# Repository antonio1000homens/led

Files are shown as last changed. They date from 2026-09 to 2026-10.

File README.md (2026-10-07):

# LED information board

CircuitPython prototype for four 64×32 HUB75 RGB panels arranged as one 256×32 board. The intended physical controller is an Adafruit MatrixPortal S3. The board is now a generic renderer: external feeds are normalized by the CPython backend into `/api/screens`, and both the browser simulator and physical MatrixPortal consume the same screen contract.

## Architecture

```text
National Rail ───┐
Queue-Times ─────┤
Todoist ─────────┼──> publisher/server ──> GET /api/screens ──> MatrixPortal S3
Open-Meteo ──────┤                              │                    │
Future feeds ────┘                              └──> browser          └──> 256×32 HUB75
```

## Repository layout

Application Python is grouped by runtime rather than kept flat at the repository root:

```text
code.py       CircuitPython/Wokwi entrypoint
hardware/matrixportal/firmware/  MatrixPortal implementation
backend/      local CPython server and Lambda implementation
shared/       renderer/fixture modules used by both runtimes
scripts/      build, test, deployment and maintenance tooling
tests/        host-side regression tests
docs/         cross-cutting architecture/deployment documentation
```

The root `code.py` is intentional because Wokwi/CircuitPython uses that
entrypoint. Use `scripts/stage-firmware.sh` to create the flat filesystem
expected by a physical board, or `scripts/install-firmware.sh` to copy it to
a mounted `CIRCUITPY` volume.

MQTT carries two independent display paths. Retained snapshots on
`led/screens/+` add expiring screens to the normal rotation; reminder events on
`led/flash/reminder` remain interrupting overlays that pause and resume that
rotation. The first cycle-screen producer is the [Home Assistant next-recycling
screen](https://github.com/antonio1000homens/homeassistant/issues/7). The board
uses one MQTT connection, and broker credentials remain in board-local
settings.

The MatrixPortal does not hold National Rail, Todoist, Queue-Times or weather-provider credentials. It only needs Wi-Fi access to the backend. Feed authentication, polling, caching and stale handling remain server-side.

The checked-in defaults run a deterministic fixture mode for Wokwi, with no credentials or LAN backend required. Screens rotate using each screen's `duration_seconds`. The top-right `HH:MM` clock and bottom-right weather status are renderer-level overlays and therefore remain visible on every screen.

## Production AWS deployment

Production does **not** run `backend/server.py` as an always-on webserver. EventBridge Scheduler invokes `led-publisher` once per minute; the Lambda refreshes only feeds whose independent TTL has elapsed, persists the last successful feed state to private S3, and atomically publishes the existing `/api/screens` contract as an S3 object. CloudFront serves the simulator and screen snapshot through a private S3 Origin Access Control (OAC).

The production endpoint is:

```text
https://led.alf-broadcast.co.uk
https://led.alf-broadcast.co.uk/api/screens
```

Cloudflare remains the authoritative DNS provider and points the DNS-only `led.alf-broadcast.co.uk` CNAME at CloudFront. The S3 `state/*` prefix is not exposed through CloudFront.

GitHub Actions uses AWS OIDC and stores only non-secret deployment configuration. The National Rail and Windsor Cloudflare deployment secrets are Standard `SecureString` parameters under `/led/deploy/*`; the workflow assumes `GitHubActionsLedDeployRole` first, then decrypts and masks those two values. Todoist is separate because its OAuth refresh token rotates at runtime: its client credentials plus access/refresh tokens remain in `/led/todoist/oauth`, which only the publisher runtime can read and update.

See [`docs/DEPLOYMENT.md`](docs/DEPLOYMENT.md) for first-time AWS bootstrap, the Bitwarden-to-SSM migration helper, deployment-secret rotation, Todoist OAuth bootstrap, GitHub variables, ACM/Cloudflare setup, manual deployment and runtime details.

## Remote model slicing

This repository owns the CAD sources and geometry validation. The reusable
Windsor Slicer service prepares this repository at an immutable commit,
generates the model declared in `.windsor-slicer.yaml`, validates it, and
returns a sliced 3MF. It does not submit jobs to a printer.

See [Windsor Slicer](https://github.com/antonio1000homens/windsor-slicer) for
the manifest contract and service details. The public MCP endpoint is
`https://slicer.alf-broadcast.co.uk/mcp`.
## Hardware notes

For the current MatrixPortal refresh/pacing architecture, measured performance
results, and the decisions from issues #70, #91, #92 and #94, see
[`hardware/matrixportal/docs/matrixportal-performance.md`](hardware/matrixportal/docs/matrixportal-performance.md).

The four panels must have an appropriate HUB75 data chain and a separate, correctly sized 5 V power supply. Do not attempt to power four panels from the MatrixPortal or USB alone. Confirm the panel scan/pin wiring against the actual panel before purchase; the software assumes the MatrixPortal S3 `MTX_*` pin definitions and 1/32-scan 64×32 panels.

Wokwi uses four chained WS2812 matrix parts as a visual surrogate because its documented CircuitPython target and built-in matrix part do not reproduce a MatrixPortal S3 HUB75 panel. It also prints the active screen to the serial monitor.

## Run tests

```sh
bash scripts/run-tests.sh
```

## Backend

For rapid look-and-feel work without a MatrixPortal, run the local server:

```sh
bash scripts/run-server.sh
```

Then visit `http://127.0.0.1:8000`. The browser polls `/api/screens` every 30 seconds and renders the same normalized screen kinds used by the physical board.

### Live National Rail data

The backend talks to National Rail Darwin LDBWS and keeps the credential server-side. Install the CPython-only dependency in an isolated environment:

```sh
python3 -m venv .venv
source .venv/bin/activate
python -m pip install -r requirements-server.txt
```

Copy `.env.example` to `.env` and set the Bitwarden Secrets Manager UUID:

```text
LED_DATA_SOURCE=national_rail
BWS_NATIONAL_RAIL_TOKEN_SECRET_ID=<bitwarden-secret-uuid>
```

The process requires an authenticated `bws` CLI, normally through `BWS_ACCESS_TOKEN`. It resolves the token at startup and never sends it to the MatrixPortal or browser. This is a local-development path only; the production GitHub deployment no longer depends on a Bitwarden machine account.

### Thorpe Park queue times

The backend can append a Thorpe Park screen sourced from Queue-Times.com park ID `2`. No Queue-Times credential is required. The default cache is 300 seconds to match the source's approximate refresh cadence.

Enable it in `.env`:

```text
LED_THORPE_PARK_SOURCE=queue_times
LED_THORPE_PARK_CACHE_SECONDS=300
LED_THORPE_PARK_RIDES=Hyperia,Stealth,The Swarm,SAW - The Ride,Nemesis Inferno,Colossus,Ghost Train,Rush,Detonator,Tidal Wave
```

Configured rides are matched case-insensitively and kept in a stable order. The heading remains fixed while a three-row viewport cycles down the configured list: rows hold briefly, slide upward together, then settle on the next ride. When more rides are configured the Thorpe Park screen duration grows so the additional rows can be shown before the board rotates to the next screen. A failed refresh keeps the last successful data and marks only the Thorpe Park screen stale; a cold Queue-Times failure produces an unavailable Thorpe screen without removing rail departures.

Queue data is displayed with `Powered by Queue-Times.com` attribution.

### Todoist upcoming events

Production can append a `calendar_agenda` screen sourced from the Todoist API v1 `GET /api/v1/tasks/filter` endpoint. The publisher follows Todoist cursor pagination, normalizes scheduled items into Europe/London time, retains active overdue tasks, sorts them chronologically, removes only undated tasks, and publishes at most six events. Overdue rows are labelled `OVERDUE` on the board.

The display uses a departure-board-style two-column row:

```text
13/09 18:30 Event one
14/09 ALL   All-day event
14/09 09:00 Event three
```

Three rows are visible at once. With four to six events the first three remain visible for five seconds, then the rows slide upward together and events 4–6 settle into the same viewport. The heading, clock and weather overlay remain fixed. With three or fewer events no paging occurs.

Default production settings are:

```text
LED_CALENDAR_SOURCE=off
LED_TODOIST_CACHE_SECONDS=300
LED_TODOIST_MAX_EVENTS=6
LED_TODOIST_FILTER_QUERY=due before: tomorrow | due after: yesterday
LED_TODOIST_TIMEZONE=Europe/London
LED_CALENDAR_DURATION_SECONDS=10
LED_CALENDAR_PAGE_SECONDS=5
```

The feed is intentionally **off by default**. The current production `/api/screens` object is publicly retrievable through CloudFront, so enabling a personal Todoist feed makes the selected task names and dates/times publicly retrievable as part of that JSON response. Use a deliberately narrow Todoist filter/project/label if this exposure is acceptable, or protect/personalize the screen endpoint before enabling private task data.

#### Todoist OAuth bootstrap

Use the Client ID and Client Secret from the Todoist integration rather than a personal API token. OAuth state is stored in SSM Parameter Store at `/led/todoist/oauth` as a **Standard `SecureString`**. The value contains the client credentials plus the current access and refresh tokens. The Lambda reads it with decryption, refreshes expiring access tokens itself, and immediately overwrites the parameter with Todoist's replacement refresh token.

For a newly-created Todoist integration, add this OAuth redirect URL in Todoist App Management unless you choose another URI:

```text
http://127.0.0.1:8765/callback
```

For a fresh authorization, run the bootstrap script from a machine with AWS CLI access to the LED account:

```sh
TODOIST_CLIENT_ID='<client-id>' \
AWS_PROFILE='<aws-profile>' \
python3 scripts/bootstrap-todoist-oauth.py
```

The script prompts securely for the Client Secret, requests only the `data:read` Todoist scope, opens the authorization page in your browser, validates the OAuth `state`, receives the localhost callback, exchanges the authorization code, and writes the credentials/tokens to the Standard `SecureString`. To use a different registered redirect URI, set `TODOIST_REDIRECT_URI`; `--manual` is also available when a localhost callback is unsuitable.

If you already bootstrapped the previous Secrets Manager implementation, migrate the existing OAuth JSON without authorizing Todoist again:

```sh
AWS_PROFILE='<aws-profile>' \
python3 scripts/bootstrap-todoist-oauth.py \
  --migrate-secret-id '<existing-secrets-manager-arn>'
```

After deploying the SSM-backed stack and verifying Todoist, schedule the old Secrets Manager secret for deletion so it is no longer billed:

```sh
AWS_PROFILE='<aws-profile>' aws secretsmanager delete-secret \
  --region eu-west-2 \
  --secret-id '<existing-secrets-manager-arn>' \
  --recovery-window-in-days 7
```

Do not pass the Client Secret on a shell command line. For unattended fresh authorization the script also accepts `TODOIST_CLIENT_SECRET` from the environment, but an interactive prompt is preferred.

Once OAuth is present in SSM, set the GitHub repository variable:

```text
LED_CALENDAR_SOURCE=todoist
```

and run the deployment workflow. There is no `BW_TODOIST_TOKEN` or Todoist token CloudFormation parameter; runtime token rotation is contained in the SSM `SecureString`.

A failed Todoist refresh preserves the last successful events and marks only the calendar screen stale. A cold Todoist failure publishes `Calendar unavailable` without affecting rail, queue or weather data. A successful response containing no qualifying tasks renders `No upcoming events` and is not stale.

For credential-free visual testing, the local fixture contains six normalized events and exercises both agenda pages:

```sh
bash scripts/run-server.sh --calendar-source fixture
```

### Current weather overlay and dedicated Weather screens

The backend uses one Open-Meteo request and one atomic Weather cache for all Weather output: the compact current-weather overlay, the seven-day daily forecast, the rolling next-24-hour forecast, and today's sunrise/sunset. The request includes current temperature/WMO weather code, hourly temperature/weather code, and daily max/min/weather code/sunrise/sunset with `timezone=auto`. The free non-commercial endpoint needs no API key. Weather is cached for 600 seconds by default, so MatrixPortal/browser polls never create separate upstream polling paths for the three dedicated screens.

The default coordinates are New Malden railway station, matching the default `NEM` departure board:

```text
LED_WEATHER_SOURCE=open_meteo
LED_WEATHER_CACHE_SECONDS=600
LED_WEATHER_LATITUDE=51.4039
LED_WEATHER_LONGITUDE=-0.256
```

Set `LED_WEATHER_SOURCE=off` to stop Weather polling and remove all Weather output, or change latitude/longitude for another location. When Weather is enabled, the dedicated screens appear in this order when their individual controls are enabled:

1. `weather_weekly` — the existing seven-day overview, default 8 seconds. It preserves the max-only layout introduced with #195: weekday, enlarged weather icon and maximum temperature.
2. `weather_today` — six rolling four-hour snapshots covering the next 24 hours, default 8 seconds. The first column is labelled `Now` and uses current conditions; the remaining columns are labelled at four-hour intervals and may cross midnight. The weather icon and temperature remain prominent.
3. `weather_sun` — today's local sunrise and sunset times, default 6 seconds.

The protected admin/control plane provides independent enable and duration controls for the overview, next-24-hour and sunrise/sunset screens. The master Weather `enabled` switch still owns provider polling. If all three dedicated screens are disabled while Weather remains enabled, polling/cache refresh continues and the current-weather overlay can still appear on unrelated screens.

The backend maps Open-Meteo WMO weather codes into a renderer-neutral icon set (`clear_day`, `clear_night`, `partly_cloudy_*`, `cloudy`, `fog`, `rain`, `snow`, `storm`). All three dedicated Weather screens use the full 256×32 canvas and suppress the normal clock/current-weather/STALE header chrome; the browser simulator mirrors the same screen sequence and supports forced-stale preview.

If a Weather refresh fails after at least one successful response, the complete last-good current + weekly + rolling next-24-hour + solar payload remains available with `stale: true` and the dedicated renderers use their muted treatment. On a cold Weather failure, unrelated feeds remain available; the seven-day overview may show its existing unavailable state when enabled, while empty next-24-hour and sunrise/sunset screens are not emitted. Browser attribution links to Open-Meteo are included as required by the provider's licence.

### Screen contract

`GET /api/screens` is the renderer-neutral contract. A response contains `fetched_at` plus one or more screens. The current-weather object is attached to every screen for the shared header carousel, and Weather also contributes one dedicated `weather_weekly` screen with a `days` array:

```json
{
  "fetched_at": "2026-09-13T11:45:30Z",
  "screens": [
    {
      "id": "departures",
      "kind": "rail_combined",
      "duration_seconds": 8,
      "title": "NEM departures",
      "source": "national_rail",
      "stale": false,
      "services": []
    },
    {
      "id": "calendar",
      "kind": "calendar_agenda",
      "duration_seconds": 10,
      "title": "UPCOMING",
      "source": "todoist",
      "stale": false,
      "viewport_size": 3,
      "page_seconds": 5,
      "events": [
        {"start": "2026-09-13T18:30:00+01:00", "all_day": false, "date_text": "13/09", "time_text": "18:30", "title": "Event one"}
      ]
    }
  ]
}
```

The MatrixPortal rotates these screens locally and does not reset the active screen every time fresh data is polled. If the backend becomes temporarily unreachable it keeps the last screens, marks the active screen stale, and dims the retained weather value.

The board can also receive MQTT cycle screens independently from HTTP. Publish
retained JSON snapshots to `led/screens/<screen.id>` at QoS 1. Each snapshot
uses `schema_version: 1`, `event: "upsert"`, ISO-8601 `published_at` and
`expires_at`, a `source`, and a renderer payload under `screen`. A later
`published_at` replaces that slot; an older one is ignored. Send
`event: "clear"` with a fresh `published_at` to remove a slot. Expiry is checked
against the synchronized board clock locally, so an expired retained value
does not reappear after reconnect. HTTP screens remain in backend order, then
active MQTT screens are appended in stable ID order.

The topic suffix must exactly equal `screen.id`. The board accepts only
schema version 1 and `upsert` or `clear` events, and ignores malformed,
unknown-kind, mismatched, older and already-expired snapshots. A clear retains
its publication timestamp for ordering. Reconnect delivers the broker's
retained active snapshot again.

```json
{
  "schema_version": 1,
  "event": "upsert",
  "published_at": "2026-10-07T19:00:05+01:00",
  "expires_at": "2026-10-14T00:00:00+01:00",
  "source": "homeassistant",
  "screen": {
    "id": "homeassistant-next-bin",
    "kind": "bin_collection",
    "title": "NEXT COLLECTION",
    "duration_seconds": 8,
    "slide_speed": 20,
    "collection_date": "2026-10-13",
    "collections": [{"id": "mixed", "label": "Mixed recycling"}],
    "source": "homeassistant",
    "stale": false
  }
}
```

Clear a slot by publishing a retained `event: "clear"` snapshot with a newer
`published_at` to that same topic. It has no `screen` or `expires_at` field.

The first MQTT renderer is `bin_collection`: provide `title`, ISO
`collection_date`, one or two `{id, label}` collection entries,
`duration_seconds`, and `slide_speed`. The supplied labels are shown together
on one screen, with long labels scrolling at the supplied pixel rate. Preview
it in the browser simulator with **Preview recycling screen**. The initial
producer work is tracked in [Home Assistant issue #7](https://github.com/antonio1000homens/homeassistant/issues/7).

The board clock is derived from the backend's UTC `fetched_at` timestamp and advanced locally between polls. The CircuitPython client converts UTC to Europe/London time itself, including the GMT/BST transitions, so no separate NTP or clock API is needed.

## Physical MatrixPortal configuration

For the deployed service, configure the board to use the CloudFront/custom-domain endpoint:

```python
DISPLAY_BACKEND = "matrix"
SCREEN_SOURCE = "api"
SCREEN_API_URL = "https://led.alf-broadcast.co.uk"
POLL_SECONDS = 30
ANIMATE = True
FRAME_SECONDS = 0.2

WIFI_SSID = "your-wifi-name"
WIFI_PASSWORD = "your-wifi-password"
WIFI_STARTUP_DELAY_SECONDS = 10
WIFI_TX_POWER_DBM = 8
```

The physical API application keeps Wi-Fi off for 10 seconds, then enables it
with an 8 dBm transmit-power limit before connecting. The bare-board test
restarted on the wall USB supply at its original transmit power, but remained
reachable at 8 dBm; the full application also answered pings on that supply.
Stability with powered panels still requires a physical check. Lower transmit
power reduces range and does not establish that the supply is electrically sound.

Use custom `WIFI_SSID` and `WIFI_PASSWORD` keys in board-local `settings.toml`,
or the Python settings above. Remove the reserved `CIRCUITPY_WIFI_SSID` and
`CIRCUITPY_WIFI_PASSWORD` keys: those cause an automatic connection before the
application can apply its transmit limit. Automatic browser maintenance is
disabled with this configuration; install over USB and power-cycle afterward
so the staged `boot.py` runs. Existing credentials remain board-local.

For local development instead, copy `hardware/matrixportal/firmware/settings_local.py.example` to the ignored root `settings_local.py` and point `SCREEN_API_URL` at the LAN machine running `scripts/run-server.sh`, for example `http://192.168.1.123:8000`.

The MatrixPortal does not need provider credentials or direct upstream API clients. It makes only the same `/api/screens` request regardless of which server-side feeds are enabled.

For a physical board to reach a local backend, start the grouped backend on an address reachable from the LAN rather than its safe `127.0.0.1` default. For example, on a trusted home network:

```sh
LED_SERVER_HOST=0.0.0.0 bash scripts/run-server.sh
```

Do not expose the local development server directly to the public Internet.

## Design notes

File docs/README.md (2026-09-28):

# Documentation

Cross-cutting repository documentation lives here. Hardware-specific documentation
lives beside the hardware it describes.

## Repository

- [Deployment](DEPLOYMENT.md) — AWS, CloudFront, Cloudflare, SSM and production rollout.
- [Control plane](CONTROL_PLANE.md) — admin/control API architecture and security boundaries.
- [GitHub Actions ownership](WORKFLOWS.md) — path-scoped CI/CD responsibilities.

## Hardware documentation

- [MatrixPortal S3](../hardware/matrixportal/README.md)
  - [Performance and refresh architecture](../hardware/matrixportal/docs/matrixportal-performance.md)
  - [Hardware refresh experiment record](../hardware/matrixportal/docs/HARDWARE_REFRESH_EXPERIMENT.md)
  - [MQTT hardware validation](../hardware/matrixportal/docs/MQTT_HARDWARE_VALIDATION.md)
- [Enclosure](../hardware/enclosure/README.md)
  - Direct-mount design docs are under `hardware/enclosure/docs/`.

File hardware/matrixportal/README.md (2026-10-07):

# MatrixPortal S3 first hardware test

This folder contains a deliberately small CircuitPython smoke test for the
physical HUB75 panels.

## Safe first connection

Start with one panel:

- power the MatrixPortal S3 from its USB-C connector;
- power the HUB75 panel from the separate regulated 5 V LED power supply;
- connect the MatrixPortal HUB75 output to the panel's **IN** connector;
- the HUB75 cable provides signal grounds between the controller and panel;
- do not try to power the LED panel from USB.

The test defaults to one 64x32 panel. Once one panel works, change
`PANEL_COUNT = 4` to test the repository's full 256x32 horizontal chain.

## Install CircuitPython from macOS

1. Use a USB-C cable that carries data, not a charge-only cable.
2. Connect the MatrixPortal S3 to the Mac.
3. Double-click **RESET**. A drive named `MATRXS3BOOT` should appear.
4. Download the current stable MatrixPortal S3 CircuitPython UF2 from:
   <https://circuitpython.org/board/adafruit_matrixportal_s3/>
5. Drag the UF2 onto `MATRXS3BOOT`.
6. The board reboots and a drive named `CIRCUITPY` appears.

If the board already mounts as `CIRCUITPY`, CircuitPython is already
installed and you can skip the UF2 step.

## Run the RGB smoke test

Copy `rgb_test.py` from this folder to the root of the `CIRCUITPY` drive
and rename it to `code.py`:

```sh
cp hardware/matrixportal/rgb_test.py /Volumes/CIRCUITPY/code.py
```

CircuitPython automatically reloads `code.py` when the file is saved.

With the panel powered separately you should see the whole panel cycle every
two seconds through dim red, green, blue, and black.

The colours are intentionally limited to roughly 25% per channel for this
first test rather than turning the entire panel full-bright white.

## Serial console on macOS

To see the test messages, find the CircuitPython USB serial device:

```sh
ls /dev/cu.usbmodem*
```

Then connect with the macOS `screen` command, substituting the device name
shown above:

```sh
screen /dev/cu.usbmodemXXXX 115200
```

Exit `screen` with **Ctrl-A**, then **\\** and confirm.

Expected output repeats the colour names:

```text
MatrixPortal S3 HUB75 smoke test started
Panel count: 1
Display size: 64x32
RED
GREEN
BLUE
BLACK
```

## After one panel works

Change:

```python
PANEL_COUNT = 1
```

to:

```python
PANEL_COUNT = 4
```

Then connect panel 1 **OUT** to panel 2 **IN**, panel 2 **OUT** to panel 3
**IN**, and panel 3 **OUT** to panel 4 **IN**. Each panel still needs its
proper 5 V power connection.

The smoke test intentionally uses the same MatrixPortal S3 pin setup as
`hardware/matrixportal/firmware/display.py`:

```python
addr_pins=board.MTX_ADDRESS[:4],
**board.MTX_COMMON,
```

If a panel displays repeated rows, shifted rows, wrong colours, or no image
while the serial test is running, check the panel model/scan type and HUB75
IN/OUT orientation before changing the application renderer.

## Install the production application

After the four-panel smoke test works, replace the smoke-test `code.py` with
the real application. Put this uncommitted `settings_local.py` on the root of
the `CIRCUITPY` drive:

```python
DISPLAY_BACKEND = "matrix"
SCREEN_SOURCE = "api"
SCREEN_API_URL = "https://led.alf-broadcast.co.uk"

POLL_SECONDS = 30
ANIMATE = False  # use static pages for maximum HUB75 stability
FRAME_SECONDS = 0.2

WIFI_SSID = "YOUR_WIFI_NAME"
WIFI_PASSWORD = "YOUR_WIFI_PASSWORD"
```

Keep Wi-Fi credentials out of `settings.py` and out of Git. The application
uses `wifi.radio.connect(...)` through `ScreenClient` and reads production
screen data from `/api/screens`.

### Enable local Wi-Fi application uploads

The MatrixPortal S3 supports CircuitPython Web Workflow over its local Wi-Fi
network. This updates application files only; CircuitPython UF2 firmware still
requires USB and `MATRXS3BOOT`.

During initial USB setup, copy `settings.toml.example` to the root of the
`CIRCUITPY` drive as `settings.toml` and replace the placeholders:

```toml
CIRCUITPY_WIFI_SSID="your-wifi-name"
CIRCUITPY_WIFI_PASSWORD="your-wifi-password"
CIRCUITPY_WEB_API_PASSWORD="unique-local-password"
CIRCUITPY_WEB_API_PORT=80
CIRCUITPY_WEB_INSTANCE_NAME="matrixportal-s3"
```

Hard-reset the board after saving the file. From a computer on the same trusted
LAN, open `http://matrixportal-s3.local/` (or the IP shown by the serial
console) and authenticate with a blank username plus the Web Workflow password.

For an application upload, open the Web Workflow serial console, press
**Ctrl-C** until the `>>>` prompt appears, and eject any mounted `CIRCUITPY`
drive on the computer. Then run:

```sh
python3 scripts/upload-firmware-wifi.py --host http://matrixportal-s3.local
```

The helper stages the same application payload as the USB installer, uploads
`code.py` last, and verifies every file by SHA-256 readback. It never modifies
`settings.toml`, `settings_local.py`, or `lib/`.

If a write returns HTTP 409, first eject the USB drive and retry while leaving
the board at the `>>>` prompt. On the tested MatrixPortal S3 running
CircuitPython 10.3.0, ejecting alone left the filesystem locked. If HTTP 409
persists, use the verified workaround: disable USB mass storage at startup for
the upload:

1. With `CIRCUITPY` mounted read/write and the app paused, check whether
   `boot.py` already exists at the drive root. If it does, stop and preserve it;
   do not overwrite a pre-existing startup script. Otherwise create a temporary
   `boot.py` containing only these two lines:

   ```python
   import storage
   storage.disable_usb_drive()
   ```

2. Eject `CIRCUITPY` but keep USB connected, then hard-reset the board. Confirm
   the volume is absent and `/cp/diskinfo.json` reports `writable: true`.
3. After the hard-reset, press **Ctrl-C** in the serial console to pause the
   application again at `>>>`, then run the uploader. Do not leave the temporary
   `boot.py` on the board after the upload.
4. Remove it through the authenticated Web Workflow endpoint with:

   ```sh
   python3 scripts/upload-firmware-wifi.py --host http://matrixportal-s3.local --remove-temporary-boot-py
   ```

   The helper prompts for the password, confirms `boot.py` contains exactly the
   two workaround lines above, deletes it, and verifies the file is gone. It
   refuses to delete a different `boot.py`. Then press **Ctrl-D** to resume the
   app and hard-reset once more to restore the default USB mass-storage
   interface.

Authentication failures return only a safe retry message. If an upload is
interrupted, leave the board paused and run the helper again; uploads are
repeatable and overwrite the staged application files before verifying them
again.

Press **Ctrl-D** in the serial console after a successful upload. CircuitPython
reloads `code.py` and returns to normal display mode. A hardware reset also
starts normal mode. The existing USB procedure remains the recovery path:
restore application files to `CIRCUITPY`, and use `MATRXS3BOOT` for UF2
firmware updates.

Web Workflow uses password-protected HTTP on the local network. Do not expose
the board outside the trusted LAN or reuse its Web Workflow password elsewhere.

From the repository root, create an uncommitted local settings file if needed:

```sh
cp hardware/matrixportal/firmware/settings_local.py.example settings_local.py
```

Then stage and install the application. The install helper flattens `hardware/matrixportal/firmware/`
and `shared/` into the layout CircuitPython expects while leaving an existing
`settings_local.py` and `lib/` directory untouched:

```sh
bash scripts/install-firmware.sh /Volumes/CIRCUITPY
cp settings_local.py /Volumes/CIRCUITPY/
```

To inspect the exact payload without writing to the board:

```sh
bash scripts/stage-firmware.sh
ls .build/circuitpy
```

The current runtime dependencies are listed in `requirements.txt`. Install
them into a temporary macOS environment and target the board:

```sh
python3 -m venv .venv-circuitpy
source .venv-circuitpy/bin/activate
pip install circup
circup install -r requirements.txt
```

The MQTT listener is enabled by default, but it needs a broker configured only
in board-local `settings_local.py`. The checked-in broker setting stays empty
and contains no credentials. MQTT waits 30 seconds after display and client
initialization before its first connection attempt. It subscribes at QoS 1 to
the exact reminder topic and to the configured cycle-screen wildcard
(`MQTT_SCREENS_TOPIC`, default `led/screens/+`). Cycle screens do not depend on
the runtime Flash control from `/api/screens`; that control gates reminder
overlays only.

Flash enablement and display duration are runtime values from `/api/screens`;
they are not configured in `settings_local.py`. The board uses the safe
five-second default until its first successful runtime-config refresh.

Install `adafruit_minimqtt` into `CIRCUITPY/lib` with
`circup install -r requirements.txt`; the board still uses only uncommitted
`settings_local.py` for broker hostname, port, topic and any credentials. The
board connects outbound and does not require a reserved IP.

`gtsr4.pem` is a public Google Trust Services root certificate required by the
current `led.alf-broadcast.co.uk` certificate chain on this CircuitPython
firmware. Keep it on `CIRCUITPY`; it contains no project secret.

The production application starts in normal mode. Press **UP** to toggle
diagnostic mode. In diagnostic mode, **DOWN** cycles moderate-brightness
full-panel red, green, blue, white, and black. Press **UP** again to return to
the application. In normal mode, **DOWN** immediately advances to the next
screen and restarts its display duration. A reset always returns to normal
mode.

## Serial diagnostics on macOS

With the board connected over USB-C, find its CircuitPython serial device:

```sh
ls /dev/cu.usbmodem*
```

Connect at 115200 baud:

```sh
screen /dev/cu.usbmodemXXXX 115200
```

Startup messages, Wi-Fi failures, API failures, and rendered screen details
are printed there. Exit `screen` with **Ctrl-A**, then **\\**, then confirm
with **y**. Press **Ctrl-D** to reload CircuitPython after saving files; use
**Ctrl-C** to interrupt the running application when debugging.

Always eject `CIRCUITPY` before unplugging it:

```sh
diskutil eject /dev/diskN
```

Replace `diskN` with the external disk shown by `diskutil list`. Keep the
MatrixPortal on USB-C and the HUB75 panels on their separate regulated 5 V
supply; never hot-plug HUB75 cables while powered.

## Dirty-region refresh benchmark

Issue #92 contains a standalone benchmark for checking whether smaller
`displayio` dirty regions reduce the time spent in
`FramebufferDisplay.refresh()` on the four-panel MatrixPortal S3 chain.

This benchmark temporarily replaces the production `code.py`. It does not use
Wi-Fi, HTTP, MQTT, fonts, or the application renderer.

Copy it to the board:

```sh
cp hardware/matrixportal/partial_refresh_benchmark.py /Volumes/CIRCUITPY/code.py
```

Connect to the serial console and capture the `BENCH` lines. The script runs
three rounds and alternates scenario order to reduce bias from runtime drift.
It compares:

- a full 256×32 dirty TileGrid;
- a 256×8 dirty band;
- a 32×8 dirty band;
- a 32×8 TileGrid moving by one pixel.

All cases use the production-oriented matrix constraints for this experiment:
`bit_depth=1`, `doublebuffer=True`,
`FramebufferDisplay(auto_refresh=False)`, and
`refresh(target_frames_per_second=None)`.

The lit pattern is intentionally sparse so the full-screen case does not drive
all LEDs continuously while still dirtifying the complete TileGrid extent.

Expected serial output is aggregate-only:

```text
MatrixPortal dirty-region refresh benchmark
CONFIG width=256 height=32 bit_depth=1 doublebuffer=True warmup=12 samples=80 rounds=3
ROUND 1
BENCH scenario=full_256x32 count=80 min_ms=... avg_ms=... max_ms=...
BENCH scenario=band_256x8 count=80 min_ms=... avg_ms=... max_ms=...
BENCH scenario=band_32x8 count=80 min_ms=... avg_ms=... max_ms=...
BENCH scenario=move_32x8_1px count=80 min_ms=... avg_ms=... max_ms=...
...
BENCH COMPLETE
```

Do not interpret a smaller dirty area as a native partial HUB75 scan. The
benchmark is specifically intended to determine whether the current
CircuitPython RGBMatrix/Protomatter presentation cost remains effectively
global after `displayio` has already limited composition to dirty regions.

After testing, restore the production application with:

```sh
bash scripts/install-firmware.sh /Volumes/CIRCUITPY
cp settings_local.py /Volumes/CIRCUITPY/
```

## Short-transition cadence experiment

Issue #94 adds explicit application-cadence profiles for matched physical
comparisons. The checked-in and production default is `transition_20` (fixed
B8 presentation with 20 Hz page/header transitions).
The opt-in candidates are:

- `adaptive`: current P1 behaviour, with 12 Hz page/header/departures
  transitions and the Todoist marquee at 8 Hz;
- `transition_15`: P2, with only Todoist page/header transitions at 15 Hz;
- `transition_20`: P3, with only Todoist page/header transitions at 20 Hz.

Set one value in the ignored board-local `settings_local.py`, then install the
current application and reload CircuitPython:

```python
MATRIX_ANIMATION_PROFILE = "transition_15"
```

```sh
bash scripts/install-firmware.sh /Volumes/CIRCUITPY
```

Capture `MATRIX PRESENTATION`, `MATRIX STATS`, and `FRAME PACE` serial lines
for matched runs. The class counters in `MATRIX STATS` distinguish Todoist
marquee, Todoist page slide, header slide, and departures calling updates.
Do not change marquee speed, slide duration, or presentation mode as part of
this comparison. Restore `transition_20` after temporary candidate runs and
verify a clean boot before treating the board as deployable.

For a deterministic local payload that actually exercises both Todoist pages
and the clock/weather header, run the backend with both fixture sources:

```sh
LED_SERVER_HOST=0.0.0.0 bash scripts/run-server.sh \
  --calendar-source fixture \
  --weather-source fixture
```

The calendar fixture is emitted with the production Todoist source identity,
viewport/page timing, and an extended screen duration calculated for all six
events. The weather fixture avoids making the comparison depend on an external
weather request.

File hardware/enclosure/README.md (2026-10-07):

# LED enclosure CAD

The project is committed to the **modular hinged direct-mount enclosure** tracked by issue #133. This is the single supported enclosure architecture.

The hinge mechanism follows the validated geometry restored in PR #119:
the **equipment enclosure/base is stationary**, while the **LED panel and its
mounting template form the moving leaf** and open forward/down through a full
0–90° service arc.

The newer modular equipment system remains in place behind that hinge: a
stationary universal base contains a recessed rear locating groove, and the
universal backplane/enclosure drops vertically into that groove from above.
The backplane now carries a **54 mm clear-depth universal equipment zone**.
Only the lower U-channel insertion section is smaller; immediately above the
guides the shell uses one identical full-width Y/Z profile for the complete
256 mm length. That makes the long X dimension suitable as the print-vertical
axis. The deep section returns toward the panel near the top and finishes with a
**23.5 mm flat upper wall** parallel to the lifted LED panel. Ventilation uses **horizontal slots on the upper return ramp and lower
transition shoulder**. The long rear wall remains solid for the accessory-boss
mounting grid. The backplane reuses all three
existing top-row panel screw positions as aligned closure fasteners, so no
rotating tab or local top cutout is required.

## Architecture

```text
moving LED panel
   |
moving panel mounting template + local hinge roots
   |
6 mm metal hinge rail
   |
stationary equipment-side hinge knuckles
   |
reinforced hinge shelf + rearward support webs
   |
stationary universal equipment base
   |
recessed rear top-down groove
   |
lower 40 mm-depth U-channel insertion section
   |
full-width 54 mm enclosure profile with constant X cross-section
   |
solid rear boss-mount wall
   |
horizontal vents on lower transition + upper return ramp
   |
23.5 mm flat upper wall flush with lifted panel
   |
three aligned top-row closure screw holes
   |
   +-- detachable left side
   +-- detachable right side
   +-- future PSU adapter
   +-- future MatrixPortal adapter
   +-- future power/cable adapters
```

Every equipment base and every backplane remains interchangeable between all
four panel positions. Position- or component-specific behaviour belongs on
detachable side pieces or accessory adapters.

### Side naming and front-view orientation

The enclosure's `left` / `right` identifiers are **CAD coordinate/end names**,
not the viewer's left/right when standing in front of the finished LED display.
Because the assembly is being viewed from the opposite face, they appear
reversed in a front view:

- CAD **right** / X=module width = **front-view LEFT** = **C14 power inlet**;
- CAD **left** / X=0 = **front-view RIGHT** = **MatrixPortal S3 service/dock**.

The intended physical layout is therefore **C14 on the left and MatrixPortal on
the right when looking at the LED board from the front**. Do not swap these
parts solely to make the internal CAD side names match front-view terminology.

## Canonical printable parts

| Wrapper | Purpose |
| --- | --- |
| `parts/01_panel_hinge_template_PRINT_1.scad` | **Moving** LED/panel mounting template with local hinge roots |
| `parts/02_hinged_equipment_base_PRINT_1.scad` | **Stationary** universal equipment base, hinge knuckles/support webs/guard and recessed rear backplane groove |
| `parts/03_universal_equipment_backplane_PRINT_1.scad` | Top-down removable enclosure backplane, oriented with its 256 mm length vertical for printing; the STL is clean and uses slicer-generated support under the insertion tongue |
| `parts/04_left_equipment_side_PRINT_1.scad` | Detachable left end wall matching the lower insertion section, constant full-depth zone and upper return |
| `parts/05_right_equipment_side_PRINT_1.scad` | Detachable right end wall matching the lower insertion section, constant full-depth zone and upper return |

Matching canonical STL meshes are versioned under `stl/` and must be regenerated whenever a production SCAD changes.

## Panel mounting geometry

The six physically corrected brass insert centres remain:

- X = **7.9 / 128.0 / 248.1 mm**
- Y = **7.9 / 120.1 mm**

The four moulded-locator clearance centres remain:

- X = **26.704 / 229.296 mm**
- Y = **12.0 / 116.0 mm**
- clearance diameter = **10 mm**

## Restored PR #119 hinge

The canonical hinge now preserves the validated mechanical arrangement rather
than only its clearance numbers:

- metal rail: **6.0 mm**
- printed bore: **7.2 mm**
- barrel OD: **14 mm**
- moving panel/template lower edge and hinge centreline: **40 mm above the stationary floor**
  (**20 mm higher** than the previous installation)
- hinge axis: **y=40 mm, z=16 mm**
- closed moving-template back to barrel clearance: **7 mm**
- moving panel/template knuckles: **34–60, 92–118, 166–194 mm**
- stationary equipment knuckles: **62–90, 136–164, 196–220 mm**
- moving template uses the existing **local hinge roots only**, with no
  full-width lower lip; the moving/front-panel geometry is intentionally
  unchanged and remains outside this reinforcement change
- stationary hinge roots use **rearward-sloping webs that terminate at the hinge shelf**
- each stationary root has a **3 mm local pad** joining its barrel to the web
- a **2 mm full-width stationary lower hinge guard** sits behind the barrel with
  **0.8 mm radial clearance**
- service/mechanical opening range: **0–90°**

The panel/template rotates forward/down. The equipment base, removable backplane
and electronics stay stationary. The raised hinge also allows the stationary
base floor to extend **20 mm farther toward the front** without entering the
0–90° moving-panel sweep. The extension remains a flat structural floor; the
previous shallow front reinforcement ramp has been removed. The moving
template/front-panel geometry is unchanged; its print wrapper removes the
40 mm installation offset.

The 6 mm hinge rail is defined from **X=10 mm to X=246 mm**. Each detachable
outer side now carries a hinge-style rod support with the same **14 mm OD** and
**7.2 mm clearance bore** as the main hinge barrels. The outer section remains
capped at the rail endpoint so the rod cannot escape axially; from that endpoint
the support becomes a hollow sleeve around the rod and continues to the nearest
hinge barrel (**X=34 mm** on the left and **X=220 mm** on the right). This removes
the previous exposed solid-plug appearance while keeping the rod retained.

## Top-down removable backplane

The base/backplane interface uses a **recessed groove at the rear edge of the
base** plus two structural side guides. The centre groove is 2 mm deep with
0.6 mm nominal clearance around the 3 mm backplane edge. Each side guide is
**40 mm high × 5 mm wide** and grows directly from the base. The lower 40 mm of
the backplane is stepped inward by 5 mm per side plus 0.6 mm running clearance;
above the guide towers it returns to the normal full width.

**Base/backplane compatibility:** the 40 mm guide height and 40 mm narrowed
backplane foot are a matched interface. A backplane built to this geometry will
not fully seat in the earlier 50 mm-guide base: its full-width shoulder contacts
the final ~10 mm of the old towers before the lower edge reaches the 2 mm rear
seat, leaving the assembly standing roughly 10 mm high. When adopting this
revision, print/use the matching `02_hinged_equipment_base_PRINT_1` and
`03_universal_equipment_backplane_PRINT_1` together.

The guide towers are deliberately thickened toward the **inside** of the
enclosure. Their self-mating pin/socket junctions are carried on that interior
structure, so module-to-module and end-panel connections are hidden from the
outside. The rear exterior plane remains clean.

Each guide root is now additionally reinforced in two directions without
changing the backplane slot:

- the existing **16 mm-high junction support** continues forward until it
  overlaps the stationary hinge plate/guard, making one continuous side load
  path;
- each guide also has a **26 mm-footprint triangular floor gusset**, spanning
  the full 5 mm guide width and rising to 75% of the 40 mm guide height. The
  wedges sit ahead of the insertion slot and overlap the guide's front lip;
- both 1.2 mm capture lips of each 40 mm side guide now continue **inward toward
  the centre as backup backplane support**, stopping at the outer edge of the
  first continuous-rib socket (around X=51.4 mm on the left and X=204.6 mm on
  the right). The resulting first rib gaps remain open with the existing
  0.6 mm rib clearance, so a damaged end tongue does not leave the backplane
  supported only at the extreme enclosure edge;
- the rear of the guide gains a **10 mm-deep triangular buttress at the base**,
  tapering back to the normal guide rear face at the top of the 40 mm rail;
- a low **full-width rear shelf** extends the stationary base to the same rear
  plane as those buttresses; the left and right **1.2 mm-thick upright
  guardrails now continue from each side guide to the nearest outer rib**
  (about 58.5 mm each), with a small overlap into the X=64 / 192 mm rib tabs;
  the centre span stays open apart from the existing X=128 mm tab;
- the **3 mm backplane slot and 0.6 mm running clearance remain unchanged**.

The removable backplane/enclosure installs from directly above:

1. lower the shortened 40 mm backplane foot between the two 5 mm side guides;
2. continue downward into the rear groove until the backplane reaches the
   positive 2 mm-deep seat;
3. the 2 mm rear groove seats the sliding tongue independently. Each of the
   three **continuous 24 mm ribs now extends 1 mm below the nominal Y=0.5 mm
   floor reference**. This compensates for the observed ~1 mm physical assembly
   lift without changing the stationary base. The stationary guardrail enters a channel carved through the
   front of the rib: 0.6 mm tongue clearance, 1.2 mm guardrail thickness and
   0.6 mm clearance to the solid rear rib wall. The low rear shelf is pocketed
   through the complete rear shelf/base-seat band beneath the rib footprint,
   while the #170 outer rails/tabs are deliberately retained inside those
   sockets. All three rib feet expose bilateral lower/front entry relief so a
   stationary tab cannot catch on a closed half of a rib during top-down
   insertion. The centre tab uses two
   short low root spurs across the centre-rib socket so it remains manifold with
   the surrounding shelf without closing the full centre span;
4. the full-width shoulder above the guides then sits over the tower tops while
   the low rear shelf and rib rear faces terminate on the same flush plane;
5. fit the detachable outer side/end piece where required.

The universal backplane keeps the existing lower guide interface but is now
designed around side-on vertical printing:

- lower guide/insertion zone retains the original **40 mm** depth and narrowed
  width required by the U-channel capture;
- immediately above the 40 mm guide section, the shell switches to the
  **full service width** and keeps the same Y/Z profile across the complete
  256 mm X length;
- the fragile tongue-to-deep-shell junction is reinforced by **three continuous
  rear ribs**, centred at X = **64 / 128 / 192 mm**. Each keeps the existing
  **24 mm print-Z taper** but now runs as one solid object from the reinforced
  shoulder to **Y=-0.5 mm**, providing 1 mm of rib-only seating compensation
  below the nominal Y=0.5 mm base reference. The existing **18 mm-wide guardrail
  channel** is subtracted through the lower/front portion of that solid rib,
  preserving the 0.6 mm tongue clearance, 1.2 mm guardrail and 0.6 mm rear
  clearance. Because the whole rib retains the existing gradual X/print-Z taper,
  Windsor/Bambu Studio does not detect a floating region;
- main equipment zone: **54 mm clear depth**;
- structural full-depth rear-wall region: **92 mm high** from the 40 mm guide
  top to the return ramp;
- the reinforced lower shoulder occupies the first **8 mm**, leaving **84 mm
  of genuinely usable full-depth height above it**: 80 mm PSU height + 4 mm
  total vertical clearance;
- return ramp: **12 mm high**, repeated identically across X and carrying the restored top ventilation;
- final upper wall: **23.5 mm high**, flat and parallel to the lifted LED panel;
  the raised enclosure provides enough extra height to restore the 12 mm return
  ramp while retaining the full PSU envelope;
- stationary enclosure top: **168 mm**, matching the lifted front-panel height;
- ventilation: **three rows** of seven **24 mm × 1 mm rounded horizontal slots**
  on the reinforced lower transition plus **four rows** of seven matching slots
  across the restored **12 mm upper return ramp**;
- the full-depth rear wall stays solid for the M3 boss grid;
- lower insertion wall and final 23.5 mm top wall remain solid;
- rear cable/ribbon slots remain absent;
- three closure-hole X positions: **7.9 / 128.0 / 248.1 mm**;
- closure-hole installed Y: **160.1 mm**;
- closure-hole diameter: **4.5 mm**, identical to the panel mounting holes.

These three holes are derived directly from the existing measured top-row panel
mounting coordinates, so the enclosure and panel stay aligned from one source
of truth. Longer screws pass through the stationary backplane into the existing
panel mounting locations and act as removable closure fasteners. The three
closure screws must be removed or loosened before opening the hinged panel.

### Panel-pair seam joiners

Three removable joiners tie the four enclosure modules together at the three
internal panel seams. Each joiner reuses the two existing top-row closure screws
nearest a seam: the right-most hole of the module on the left and the left-most
hole of the module on the right.

- screw-centre spacing across a seam: **15.8 mm** (7.9 mm either side);
- clearance holes: **4.5 mm**, matching the existing panel/enclosure holes;
- body: **28.8 mm × 13 mm × 3 mm** PETG-friendly dog-bone plate;
- install location: rear face of the shallow top wall at the existing closure
  screw height;
- quantity for the complete four-panel display: **3**.

Render `parts/10_panel_pair_joiner_PRINT_3.scad` to produce all three joiners
in one print job. Because the joiner adds 3 mm under each screw head, use
closure screws long enough to retain the same thread engagement in the LED
panel. The joiners are removable and do not change the hinge/service procedure.

The upper module/end-plate alignment remains entirely below the 75 mm ramp
start, but now uses only **compact local seam bosses** around the seated tab/slot
instead of the previous long diagonal edge arms. Each boss is 10 mm high and
tapers across the 8 mm edge width from the native 3 mm rear wall to the local
connector thickness, which keeps the side-on print self-supporting. The vertical
release slot still extends 15 mm into the ramp so the removable backplane can
lift past an end plate without bringing solid connector geometry into the clamp
clearance zone.

The full-depth **rear wall** carries the accessory mounting grid and remains
solid around that grid except for the blind boss holes. Ventilation is confined
to the reinforced lower transition shoulder and the restored 12 mm upper return
ramp. The lower insertion section and final 23.5 mm flat upper wall remain solid. Rear cable/ribbon through-slots remain intentionally absent.

In a joined row, side pieces are installed only at the two outside edges;
neighboring guide-tower pin/socket features mate across internal seams.
HUB75/power cabling must route through these open internal module-to-module
sides rather than through the rear backplane.
Glue is not part of normal assembly.

## Universal accessory interface

Every backplane carries the same M3-ready boss grid on its **inside face**.
The bosses project into the equipment cavity and use blind holes; at least
1.2 mm of solid material remains on the external rear face, so no boss or screw
hole is visible from outside:

- X = **32 / 80 / 128 / 176 / 224 mm**
- Y = **62.5 / 82.5 / 102.5 mm** (three rows; outer rows 22 mm inside the full-depth-region edges, plus a centred row)
- boss OD = **7 mm**
- boss height = **4 mm**
- blind M3 clearance hole = **3.4 mm**, stopping before the external rear skin

PSU, MatrixPortal and future electronics should use detachable adapter plates.

### MatrixPortal S3 side-mounted click dock

The MatrixPortal S3 has a removable left-end service dock under
`matrixportal/`. The **dedicated left side**, rather than the backplane, now
retains the dock:

- `parts/09_left_equipment_side_matrixportal_PRINT_1.scad` adds two inward
  keyed receiver channels immediately below/above the **52 × 31 mm**
  carrier/service opening;
- `parts/08_matrixportal_s3_dock_PRINT_1.scad` has matching PETG snap tabs,
  no M3 dock fixing holes and **no backplane boss sockets**;
- the dock's solid rear face runs **0.40 mm clear of the universal boss-tip
  plane**, so the complete side/dock/controller assembly can be pulled outward
  without the backplane capturing it;
- `parts/10_matrixportal_s3_carrier_PRINT_1.scad` carries the controller on
  four **11.5 mm** standoffs, each with a fixed **2.20 mm locating pin**, clearing
  the conservative 9 mm underside connector envelope by 2.5 mm;
- print **two** `parts/11_matrixportal_s3_keeper_PRINT_1.scad` bars; each drops
  over one column of locating pins and slides 2 mm into a small PETG click-lock,
  so the PCB needs no M2.5 screws or nuts;
- the carrier still slides in from the CAD-left/front-right side on captive
  dovetails and clicks into a shallow PETG detent at a positive seated stop;
- normal controller access is now by removing the **front-right side with the
  MatrixPortal still attached**, exposing its connectors without opening the
  hinged enclosure;
- the controller keeps its native XY orientation so the USB/button edge faces
  outward left and HUB75 faces inward;
- `schematics/01_matrixportal_mount_ASSEMBLY.scad` previews the complete
  side-mounted dock, carrier, PCB and keeper assembly.

The generic `04_left_equipment_side_PRINT_1.scad` remains available when
controller-side service access is not required. See `matrixportal/README.md`
for hardware, fit-tuning and printing details.

For the measured ~110 × 80 × 37 mm PSU, the full-width ~255 × 84 × 54 mm
equipment region leaves ample horizontal room, 2 mm above/below the 80 mm
dimension when centred, and 17 mm of depth clearance. The rear shell profile is
continuous across X above the lower guide/insertion section. Where a 4 mm boss overlaps
the PSU footprint, 50 mm of usable depth remains, still 13 mm beyond the PSU.

## Full-height detachable end caps and side alignment

The detachable left/right sides are now full-height **end caps** rather than
enclosure-only plates:

- the **lower/base section** now uses a deliberate stepped side silhouette:
  from the rear guide/guard-rail region its upper edge runs **horizontally
  forward to the hinge/front panel**, then the front edge runs **vertically
  downward** until it intersects the existing triangular base reinforcement,
  and from that intersection the side continues along the existing **diagonal
  triangle profile** to the lower tip;
- the side therefore closes the exposed region between the rear rails and hinge
  panel without extending the diagonal upward across that gap. The old forward
  floor extension remains deliberately omitted;
- the base's existing complementary **4.0 mm pin / 4.7 mm socket** interface is
  reused unchanged by the end cap, so each side locks to the same A/B junctions
  used when two bases mate;
- the **upper/enclosure section** follows the deep region and return ramp, then
  stops at the ramp end; there is **no shallow top leg** up to the LED-board edge
  because the enclosure/backplane itself closes that final gap;
- the retained upper section still adds an inward return that reaches
  **10 mm beyond the actual enclosure edge**;
- that return includes the complete vertical service corridor swept by the
  removable backplane during its first 15 mm of upward release, so it cannot
  trap the backplane during removal;
- the existing 0.4 mm side clearance plus 0.5 mm backplane inset means that
  return is 10.9 mm from the side's inner face to its inner end;
- the return is carved around the live base/backplane geometry and has a
  dedicated keep-out around the upper module-to-module connector and its
  vertical release path, so it cannot consume the connector region.

The external 3 mm end face follows the retained base/upper profile. In the lower
section the visible front boundary is now explicitly **horizontal → vertical →
diagonal** when viewed from the side: rear rails to hinge/front panel, down that
panel to the live triangle, then along the triangle. Small overlaps into the
adjacent base geometry keep the STL one printable shell. It does not recreate
the removed forward floor extension and does not add an inward capture tongue.
The upper section still does not extend above the enclosure return ramp, and the
internal 10 mm return remains locally removed where the current
enclosure/module connector needs space.
These features provide end coverage and alignment/retention, not the primary
structural load between modules.

## Right-side C14 mains inlet

The detachable **right** equipment side includes a portrait snap-in opening for
the fused/switched IEC C14 inlet. It is integrated into the new full-height end
cap and its hidden relief cuts through the 10 mm upper return locally, leaving
the intended thin snap land at the exterior face.

- measured body/cutout: **44 mm high × 27 mm wide** in portrait orientation;
- requested fit allowance: **1.10 mm per edge** → **46.2 × 29.2 mm printed opening** (1 mm larger on every edge than the previous 44.2 × 27.2 mm aperture);
- measured body intrusion: **30 mm** behind the inside face;
- conservative rotated flange keep-out: **50 mm high × 30.5 mm wide**;
- current side wall: **3.0 mm**;
- hidden relief leaves a **1.4 mm** snap land while the rest of the side stays
  at the current 3 mm thickness;
- hidden relief margin: **2 mm** around the opening.

Placement is derived from the current `universal_deep_y1`,
`enclosure_front_z` and `universal_deep_rear_z` values. In the current model
the 44 × 27 × 30 mm occupied body envelope sits well above the hinge rod
retainer/sleeve; validation checks both the full body envelope against the rod
sleeve and against the stationary enclosure core. Later base/enclosure changes
therefore fail CI if they consume that clearance.

If the real inlet has a 2 mm or thicker latch shoulder, tune
`c14_snap_panel_t` after the physical fit test rather than changing the measured
44 × 27 mm body envelope; the exterior opening intentionally carries the larger
46.2 × 29.2 mm fit allowance above.

Physical acceptance: the flange sits flat, the spring lugs clear and catch
behind the inner edge, the inlet cannot pull back out without compressing the
lugs, and the 3 mm side remains intact outside the local hidden relief.

## Assembly previews

Single-module service views:

- `schematics/00_hinged_enclosure_ASSEMBLY.scad` — one module open to 90°
- `schematics/00_hinged_enclosure_CLOSED_ASSEMBLY.scad` — one module closed

Complete four-module display views:

- `schematics/00_complete_enclosure_OPEN_ASSEMBLY.scad` — all four modules open to 90°
- `schematics/00_complete_enclosure_CLOSED_ASSEMBLY.scad` — all four modules closed

The complete views use the current self-mating modular geometry: internal seams do
not carry detachable side retainers; only the two outside edges use end pieces.

## STL generation and validation

Regenerate the checked-in manufacturing STLs with:

```bash
python hardware/enclosure/scripts/generate_stls.py
```

Run the mechanical validator with:

```bash
python hardware/enclosure/scripts/validate_enclosure.py
```

CI regenerates all eleven canonical parts, verifies they match the checked-in
STLs, checks mesh health and floating-layer proxies, verifies base/backplane
fit and top-down insertion, then holds the **equipment enclosure stationary**
and checks the **moving panel/template** and 6 mm rod for volumetric interference
at 0, 15, 30, 45, 60, 75 and 90°. It also checks the rear-groove location,
the 54 mm universal deep zone, the **constant X profile and horizontal vents**,
the final 23.5 mm flat top wall, the three-screw top closure, capped hollow rail sleeves, lower usable
equipment volume, and neighboring-module clearance.

During design/iteration, Windsor Slicer can be invoked explicitly using the repository-root
`.windsor-slicer.yaml` and the real Bambu Studio H2D profile. GitHub Actions does **not** run Bambu Studio or generate `.3mf` files.

## Physical acceptance order

1. Print one moving panel hinge template and one stationary equipment base.
2. Confirm the three top closure screws align and secure the closed panel; then
   remove/loosen them and confirm the real 6 mm rail lets the **panel/template**
   rotate freely from 0–90° while the equipment base stays fixed.
3. Confirm the stationary lower guard and rearward hinge support webs never touch the moving panel.
4. Print one universal backplane and verify the narrowed lower 40 mm slides
   between both 5 mm guide towers with 0.6 mm running clearance, then seats
   2 mm into the rear groove and removes upward.
5. Verify the backplane returns to full width above the guide towers and the
   towers prevent lateral movement. Inspect all three tapered rear reinforcement
   ribs and confirm the **gap behind the sliding tongue is visibly present**.
   Check that the left/right upright guardrails run continuously from the side
   guides to the first outer rib on each side, and that all three 1.2 mm tabs
   enter their rib channels freely with 0.6 mm clearance to the tongue and
   0.6 mm clearance to the rear rib foot/wall. Confirm the 12 mm-wide rear foot
   continues below each rail to Y=2.5 mm without closing the channel. The centre
   span must remain open and the slide-facing surface must remain flat/unmodified.
6. Verify the main equipment zone provides 54 mm clear depth across the usable
   width and **84 mm clear height above the reinforced shoulder** (80 mm PSU +
   4 mm clearance). Confirm all three narrow rounded vent rows are clean on the
   reinforced lower transition and all four rounded rows are clean across the
   restored 12 mm upper return ramp; the full-depth rear boss wall should remain solid.
   Confirm the final 23.5 mm wall is flat/parallel to the panel with all three
   top-row closure holes aligned and there are still no rear cable/ribbon slots.
7. Print both side pieces and verify the hidden pin/socket engagement, solid
   exterior faces, profile alignment, and that each capped rod retainer remains
   hollow around the 6 mm rod up to the nearest hinge barrel.
8. Verify two identical stationary equipment assemblies align side-by-side
   using the hidden guide-tower junctions.
9. Fit representative M3 hardware/adapters to the **inside** lower boss grid
   and confirm the outside rear skin remains unbroken.
10. Only then print the remaining modules.

PETG remains preferred for repeated hinge testing.

### Backplane print stability

The backplane now prints **side-on with the 256 mm X dimension vertical**. Above
the guide section the shell has the same Y/Z profile on every structural layer,
so the 54 mm deep wall, 12 mm return ramp and top wall build without the old
under-ramp support forest.

The lower insertion tongue is intentionally narrower than the main shell so it
can slide into the base U-channels. With the left end on the bed, that tongue
starts above the bed. The manufacturing STL now leaves this region **clean**:
no sacrificial pedestal is fused into the CAD.

Use the repository-root Windsor Slicer manifest with the
`petg-supported` variant. It selects **Bambu Lab H2D 0.4 nozzle**,
**0.20mm Standard @BBL H2D**, **Bambu PETG Basic @BBL H2D 0.4 nozzle**,
**Textured PEI Plate**, and **tree-auto support**. The separate
`support-free-check` variant deliberately leaves support off so unsupported
regions remain visible during diagnostics.

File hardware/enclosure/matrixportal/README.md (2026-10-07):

# MatrixPortal S3 click dock

This accessory mounts an Adafruit MatrixPortal S3 from the **detachable left
equipment side**, keeping controller-specific attachment off the universal
backplane.

The controller uses a **side-carried two-part service dock**:

1. the fixed dock snaps into two keyed PETG receiver channels built into the
   MatrixPortal-specific CAD-left / **front-view-right** side;
2. the dock has **no backplane screws, boss sockets, locating pockets or other
   capturing features**;
3. its solid rear face runs **0.40 mm clear of the universal backplane boss
   tips**, so the side can withdraw laterally without catching them;
4. the MatrixPortal stays attached to a raised removable carrier;
5. the carrier still slides on captive dovetails for separate bench servicing.

The complete **side + dock + carrier + MatrixPortal** is therefore one removable
service assembly. Pulling the front-right side outward brings the controller
with it and exposes the USB-C, buttons and HUB75 connectors without opening the
main enclosure.

## Mechanical source

The board dimensions come from Adafruit's official Eagle board file in
`adafruit/Adafruit-MatrixPortal-S3-PCB`:

- PCB: **63.50 × 44.45 mm**;
- PCB thickness model: **1.60 mm**;
- four plated mounting holes: **2.50 mm**;
- native hole centres: X = **7.62 / 48.26 mm**, Y = **15.875 / 35.56 mm**;
- USB-C and Reset/Up/Down are on the same short edge;
- HUB75 connectors are on the opposite short edge.

The board uses its native XY orientation so the USB/button edge faces the
**outer left side** and HUB75 faces inward.

The Eagle source confirms a mirrored HUB75 connector on the underside, but does
not provide a reliable mechanical component height. The CAD therefore uses a
conservative **9 mm underside connector envelope** and the carrier raises the
PCB by **11.5 mm**, leaving **2.5 mm nominal clearance**. If the physical
connector proves taller, tune `mp_underside_connector_h` rather than moving the
official mounting-hole pattern.

## Printable parts

- `../parts/08_matrixportal_s3_dock_PRINT_1.scad` — fixed side-carried dock
  with two keyed snap tabs, a solid backplane-facing surface, two captive
  dovetail rails, click detent and seated stop;
- `../parts/09_left_equipment_side_matrixportal_PRINT_1.scad` — replacement
  left end cap with the enlarged carrier/service opening plus the two matching
  inward-facing dock receiver channels;
- `../parts/10_matrixportal_s3_carrier_PRINT_1.scad` — removable raised
  controller carrier with four 11.5 mm standoffs, integrated locating/locking
  pins and a low-profile pull tab;
- `../parts/11_matrixportal_s3_keeper_PRINT_1.scad` — tool-free slide-lock
  keeper bar. **Print two copies**, one for each mounting-hole column.

Do **not** fit both the generic `04_left_equipment_side_PRINT_1` and the
MatrixPortal-specific `09_...` left side.

## Side-carried dock attachment

The MatrixPortal-specific CAD-left / **front-view-right** side is the dock's
**only structural attachment**. Two receiver channels sit just outside the
52 mm-high service aperture: one below and one above. Matching tabs on the dock
slide into these channels from the enclosure interior and click into place.

The dock deliberately has **no geometry that wraps around, screws into or keys
against the backplane**. Its rear face is solid and the installed dock plane is
offset **0.40 mm toward the LED panel** from the universal boss-tip plane. This
provides running clearance when the side is pulled outward.

The boss grid therefore remains completely independent of MatrixPortal service.
If the long dock flexes unusually far, the boss tips can act only as
non-capturing bump stops after the 0.40 mm gap is consumed; they are not part of
normal retention.

### Side-removal service sequence

1. disconnect any external cable that would prevent the side moving outward;
2. release the detachable front-right side from the enclosure;
3. pull the side outward — the fixed dock, carrier and MatrixPortal move with it;
4. the USB-C, Reset/Up/Down and HUB75 connections are then accessible without
   opening the hinged enclosure;
5. if required on the bench, pull the carrier from its dovetails separately.

## Carrier / click interface

The carrier inserts from **left to right**:

- two captive dovetails guide and retain it in Z;
- **0.30 mm** dovetail running clearance is built into the grooves;
- one rail has a shallow ramped detent with **0.25 mm nominal click
  interference**;
- the matching carrier roof pocket lets the detent relax once fully seated;
- a fixed stop behind the carrier leading edge prevents over-insertion;
- a 3 mm low-profile pull tab sits inside the left service opening for removal.

The detent is intentionally a modest PETG interference rather than a rigid
latch. It should click positively while still releasing with a deliberate pull.
Physical fit testing should tune `mp_detent_extra_h` or
`mp_dovetail_clearance` in small increments if needed.

## Tool-free board attachment and underside clearance

The carrier now needs **no MatrixPortal screws or nuts**.

Each 11.5 mm standoff has a fixed **2.20 mm printed locating pin**. The official
PCB holes are 2.50 mm, leaving 0.30 mm diametral installation clearance. Place
the MatrixPortal straight down over the four pins until the PCB rests on the
standoff shoulders.

Each pin then continues above the PCB to a reduced **1.60 mm locking neck** and
a full-diameter tip. Lock the board with **two printed keeper bars**:

1. place one keeper over each X column of two pins using the round entry holes;
2. slide the keeper approximately **2 mm** toward the board's lower-Y edge;
3. both pin necks pass a slightly undersized PETG throat and click into the
   terminal pockets;
4. the full-diameter pin tips prevent the locked keeper lifting off.

The keeper has local feet only around the mounting-hole keepouts. Its bridge
sits **4.5 mm above the PCB top surface**, avoiding the known USB/button
components and staying left of the modelled HUB75 connector envelope. To remove
the board, slide both keepers back through their click throats, lift them off,
then lift the PCB straight off the four locating pins.

The **11.5 mm** standoff height continues to clear the conservative 9 mm
underside connector envelope by 2.5 mm.

## Service opening

The MatrixPortal service edge remains at X = **1.5 mm**. The MatrixPortal side
now has a rounded **52 × 31 mm** Y/Z opening so the complete carrier + raised PCB
can pass through the left end while keeping USB-C and the three right-angle
buttons accessible.

## Printing

The dock, carrier and keeper have been validated with:

- Bambu Lab H2D 0.4 nozzle;
- 0.20 mm Standard;
- Bambu PETG Basic;
- Textured PEI Plate;
- supports **off**.

All three slice without a floating-region warning. The MatrixPortal-specific side
retains the enclosure side part's existing support/floating-region behaviour.

## Preview

Open `../schematics/01_matrixportal_mount_ASSEMBLY.scad` to inspect the
side-mounted fixed dock, the two side receiver channels, passive backplane-boss
registration, raised carrier, locked keeper bars, PCB reference and conservative
underside connector envelope together.

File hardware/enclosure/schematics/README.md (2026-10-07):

# Mechanical reference views

The hinged direct-mount design is canonical.

Current assembly views:

- `00_hinged_enclosure_ASSEMBLY.scad` — single module, open service position;
- `00_hinged_enclosure_CLOSED_ASSEMBLY.scad` — single module, closed position;
- `00_complete_enclosure_OPEN_ASSEMBLY.scad` — complete four-module display,
  all panel leaves open to 90°;
- `00_complete_enclosure_CLOSED_ASSEMBLY.scad` — complete four-module display,
  all panel leaves closed;
- `01_matrixportal_mount_ASSEMBLY.scad` — left-end MatrixPortal click dock, raised carrier, tool-free keeper bars, PCB reference and service-side end-cap preview;
- `matrixportal_s3_REFERENCE.scad` — non-printing MatrixPortal S3 mechanical
  reference derived from Adafruit's official Eagle board geometry.

The old non-hinged complete assembly was removed when issue #133 committed the
repository to the hinged architecture. The two complete assembly views above
restore full-system visualisation using the current hinged modular geometry.

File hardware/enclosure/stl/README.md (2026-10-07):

# Canonical STL outputs

The printable STL meshes in this directory are **versioned manufacturing
outputs** generated from the canonical OpenSCAD wrappers in `../parts/` and
`../powersupply/`.

The SCAD files remain the editable source of truth, but each production print
wrapper has a matching checked-in STL so the current design can be inspected or
loaded directly into Bambu Studio without relying on an expiring CI artifact.

Canonical pairs:

- `../parts/01_panel_hinge_template_PRINT_1.scad`
  → `01_panel_hinge_template_PRINT_1.stl`
- `../parts/02_hinged_equipment_base_PRINT_1.scad`
  → `02_hinged_equipment_base_PRINT_1.stl`
- `../parts/03_universal_equipment_backplane_PRINT_1.scad`
  → `03_universal_equipment_backplane_PRINT_1.stl`
- `../parts/04_left_equipment_side_PRINT_1.scad`
  → `04_left_equipment_side_PRINT_1.stl`
- `../parts/05_right_equipment_side_PRINT_1.scad`
  → `05_right_equipment_side_PRINT_1.stl`
- `../powersupply/02_service_tray_snap_dock_PRINT_1.scad`
  → `06_psu_service_tray_snap_dock_PRINT_1.stl`
- `../powersupply/03_service_tray_snap_tray_PRINT_1.scad`
  → `07_psu_service_tray_snap_tray_PRINT_1.stl`
- `../parts/08_matrixportal_s3_dock_PRINT_1.scad`
  → `08_matrixportal_s3_dock_PRINT_1.stl`
- `../parts/09_left_equipment_side_matrixportal_PRINT_1.scad`
  → `09_left_equipment_side_matrixportal_PRINT_1.stl`
- `../parts/10_matrixportal_s3_carrier_PRINT_1.scad`
  → `10_matrixportal_s3_carrier_PRINT_1.stl`
- `../parts/11_matrixportal_s3_keeper_PRINT_1.scad`
  → `11_matrixportal_s3_keeper_PRINT_1.stl`

## Additional committed manufacturing output

- `../parts/10_panel_pair_joiner_PRINT_3.scad`
  → `10_panel_pair_joiner_PRINT_3.stl`

The panel-pair joiner STL is checked in alongside its SCAD source so it can be
loaded directly into Bambu Studio like the other enclosure manufacturing
outputs. It contains all three identical seam joiners required for the
four-panel display.

This supplemental joiner is intentionally **not** added to the enclosure
CI/validation matrix; it reuses the existing closure-hole geometry and does not
modify any enclosure component.

## Development workflow

During creation/iteration:

```bash
python hardware/enclosure/scripts/generate_stls.py
```

Then:

1. edit the SCAD;
2. regenerate the matching STL;
3. inspect/validate geometry;
4. when useful, explicitly run Windsor Slicer/Bambu Studio to validate actual
   printability;
5. iterate until satisfied;
6. commit the final SCAD and matching STL together.

Bambu slicing is **not** a normal GitHub Actions/PR step. Generated `.3mf`
files are iteration/validation artifacts and are not canonical repository
outputs.

## Pull-request validation

GitHub Actions regenerates all **eleven** canonical STLs with OpenSCAD and runs
the normal mechanical/geometry checks. The regenerated meshes are also uploaded
as a downloadable workflow artifact.

CI compares each regenerated mesh with the corresponding checked-in STL. A
missing or stale checked-in STL is reported as a **warning**, not as a mechanical
validation failure: the fresh OpenSCAD output generated in that run is the mesh
used by validation and is available in the `enclosure-stls` artifact.

Generation failures, missing generated meshes, and mechanical/geometry
validation failures remain hard CI failures. The verification script remains
strict by default for local/manual use; CI opts into warning mode with
`--warn-only`.

## Loop safety

The GitHub Actions enclosure workflow **never commits generated STL files**.

- SCAD changes on an open PR trigger regeneration, validation and comparison.
- SCAD/STL changes merged to `master` trigger the same read-only validation.
- STL-only changes can trigger one validation run so manual replacements are
  checked.
- STL drift is surfaced as a warning and does not cause a red mechanical check.
- The workflow has `contents: read` permission and cannot push generated files
  back into the repository.

This deliberately prevents the pattern:

`SCAD change → bot STL commit → workflow trigger → bot STL commit → ...`

Canonical STL updates are created with
`python hardware/enclosure/scripts/generate_stls.py` and can be committed with
the corresponding SCAD change when a refreshed versioned manufacturing output
is wanted. CI independently regenerates the meshes and warns if the committed
STL differs from the source-generated geometry.

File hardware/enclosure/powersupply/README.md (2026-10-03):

# Enclosure-centred PSU service tray

Issue #177 replaces the fixed dock's front screw-mounted latch with a pull-release flexure integral to the removable tray. Source geometry is OpenSCAD; checked-in meshes are generated artifacts.

## Parts and interface

| File | Purpose |
| --- | --- |
| `02_service_tray_snap_dock_PRINT_1.scad` | Fixed dock with enclosure pockets, runners, stop and underside detent groove |
| `03_service_tray_snap_tray_PRINT_1.scad` | Removable tray with open-ended runner grooves and integral flexure |
| `05_backplane_fit_preview.scad` | Actual enclosure backplane, fit states, PSU envelope and detent section |
| `06_boss_heatset_insert_test.scad` | Optional M3 insert test coupon for the enclosure's blind boss holes |
| `07_detent_test_coupon_TEST_1.scad` | Parametric production flexure and mating-groove coupon for PETG fit testing |
| `psu_mount_common.scad` | PSU measurements and common mount geometry |
| `service_tray_snap_latch_common.scad` | Dock, tray and flexure geometry |
| `../psu_adapter_interface.scad` | Shared geometry-free mounting-grid offsets and column selection |

## Measured dimensions

The enclosure's reinforced 8 mm shoulder leaves a usable cavity from Y=48.5 to 132.5 mm, centred at Y=90.5. The shared grid uses five X columns `[32,80,128,176,224]` and rows `[71.5,90.5,109.5]`. The dock selects columns 80 and 176, represented locally by X=±48 and row offsets Y=−19/0/+19. The other enclosure bosses remain available for accessories; the dock has relief for the two upper/lower bosses in the unused X=128 column.

A revised dock only fits a backplane with the revised boss rows. Previously printed backplanes retain Y=67.5/86.5/105.5 and will not align. The dock is 118 × 79 × 4.2 mm and the tray remains 114 × 79 × 2.8 mm. The extra 1 mm dock thickness permits the enclosure screw heads to be recessed below the sliding surface without reducing the structural web above the rear boss pockets. The 110 × 80 × 37 mm PSU overhangs the tray by 0.5 mm per side. After physical fit correction, its diagonally opposed pilots are at (−52,−36) and (+52,+36), Ø2.8 mm: the landscape bottom-left hole moved up 1 mm and the top-right hole moved down 1 mm. The pilot edge now retains 2.1 mm of material.

The two support bars and PSU screw bosses share a top plane at tray-local Z=4.8 mm (2.8 mm plate + 2 mm support). Bars are at X=±34 mm, 5 mm wide and 66 mm long. This is separate from the six enclosure fixings (Ø3.6 clearance, Ø7 × 1.8 mm head recess, Ø7.5 × 1.2 mm locating pockets).

## Slide and pull-release flexure

The tray inserts along +X. Two internal runners at Y=±25 mm use a 2.4 mm base, 4 mm top and 1.8 mm height. Their 96 mm length ends at X=+39 mm; the former +49 mm end was shortened by 10 mm. Matching grooves retain 0.3 mm lateral clearance and open through the tray's +X leading edge. A separate wall at +X stops insertion.

The tray flexure wraps around the dock's −X edge. Its PETG coupon geometry uses a 30 mm cantilever, 5 mm X width and 1.2 mm thickness. The existing 3 mm-wide ramped nose remains at Y=0..3 so the cantilever stiffness and print geometry are unchanged; the fixed dock's 6.6 mm-wide underside pocket is shifted to Y=−1.8..+4.8, centring it on the nose at Y=+1.5 and leaving 1.8 mm lateral clearance per side. Nominal engagement remains 0.5 mm into the 0.8 mm-deep pocket, leaving 0.3 mm seated clearance above the detent. Pulling the tray cams the detent down; no button press is needed. Beam thickness and engagement are parameters for physical tuning. No release-force value has been measured. Check deflection against the actual backplane and use a PETG coupon before relying on repeated flexing.

Use six M3 ISO 7380 button-head screws with head diameter no greater than 5.7 mm and height no greater than 1.65 mm. The 1.8 mm recess puts that maximum head 0.15 mm below the 4.2 mm dock surface. The tray underside runs at Z=4.45 mm when seated, leaving 0.40 mm over the supported screw-head envelope during insertion/removal. The 4.2 mm dock still retains 1.2 mm of material between the head recess and the 1.2 mm rear registration pocket. Other screw heads require a fresh clearance check.

The dock's six bosses have a nominal 4 mm height and overlap the 3 mm backplane by 0.3 mm, leaving 3.7 mm exposed toward the dock. The assembly preview places the dock so those tips enter the registration pockets by 1.2 mm. The shared interface preserves Ø7 bosses, Ø3.4 blind holes and the 1.2 mm external wall skin. Confirm screw-head clearance for the actual hardware before assembly.

## Bill of materials

| Qty | Item | Specification / note |
| ---: | --- | --- |
| 1 | Universal equipment backplane | Must use the revised boss rows Y=71.5/90.5/109.5; older printed backplanes are incompatible. |
| 1 | Fixed PSU dock | Print in PETG; 118 × 79 × 4.2 mm. |
| 1 | Sliding PSU tray | Print in PETG; 114 × 79 × 2.8 mm plate with integral flexure. |
| 1 | PSU | Measured envelope 110 × 80 × 37 mm; corrected diagonal mounting pilots at (−52,−36) and (+52,+36) mm. |
| 6 | Dock-to-backplane screws | M3 ISO 7380 button head; head diameter ≤5.7 mm and head height ≤1.65 mm. Screw length is not established by the available measurements: verify engagement in the Ø3.4 mm blind boss bores and ensure the tips preserve the 1.2 mm exterior wall skin before ordering. |
| 2 | PSU-to-tray screws | Use the PSU's specified thread and length through the Ø2.8 mm tray pilots; the PSU thread and screw length were not measured here. |
| 1 each | Detent coupon pieces | Optional PETG fit test: flexure coupon and matching groove coupon from `07_detent_test_coupon_TEST_1.scad`. |

Assembly order: attach the dock to the revised backplane using the six M3 screws and locating pockets; fit the PSU to the tray with the PSU-specified fasteners; then feed the loaded tray from −X along the runners until its +X hard stop seats and the flexure engages. Pull the tray deliberately to release it. Verify the coupon and assembled fit physically before relying on repeated service cycles.

## Render and validate

From the repository root:

```bash
python hardware/enclosure/scripts/generate_stls.py --output-dir build/enclosure-stls
python hardware/enclosure/scripts/validate_psu_adapter.py --generated-dir build/enclosure-stls
python hardware/enclosure/scripts/validate_enclosure.py --generated-dir build/enclosure-stls --workers 4
python hardware/enclosure/scripts/verify_canonical_stls.py --generated-dir build/enclosure-stls
```

The canonical model IDs remain `psu-service-tray-dock` and `psu-service-tray-tray`. Slice the dock flat. The tray print wrapper stands the plate on its 2.8 mm lower edge for a 118.8 × 13.75 × 79 mm pose; the underside flexure requires generated supports in this orientation. With Bambu Lab H2D 0.4 nozzle, 0.20 mm Standard, Bambu PETG Basic and Textured PEI, use `enable_support=1`, `support_type=tree(auto)`, `support_on_build_plate_only=0`, `support_threshold_angle=30`, `support_top_z_distance=0.2`, `support_bottom_z_distance=0.2`, and `brim_type=auto_brim` / `brim_width=5`. Bambu Studio 02.08.02.61 sliced the tray successfully with those settings and generated support features. Windsor's stock profile leaves support disabled and therefore reports `FLOATING_REGION`; that result means the unsupported profile is not print-ready, not that CAD should contain a permanent support rib. Inspect the generated supports around the flexure and open grooves before printing. A trial PSU-retention-edge pose (118.8 × 79 × 13.75 mm) was rejected by the 1 mm proxy at the upper flexure layers. Slicer validation does not start a printer job.

Render the two PETG detent coupon pieces separately (the default is the flexure):

```bash
openscad -o /tmp/psu-detent-flexure-coupon.stl hardware/enclosure/powersupply/07_detent_test_coupon_TEST_1.scad
openscad -D coupon_part=1 -o /tmp/psu-detent-groove-coupon.stl hardware/enclosure/powersupply/07_detent_test_coupon_TEST_1.scad
```

The flexure coupon reuses the production tab geometry and edge-on pose; slice it with the tray's support and brim settings. The matching groove is cropped from the production dock and prints flat without support. The coupon is for checking fit and qualitative release feel, not measuring a specified force. Adjust `detent_beam_thickness_z` or `detent_peak_z` in the common source if the printed sample needs tuning, then regenerate and revalidate all affected models.

Physical acceptance is separate: first check the PETG coupon for engagement and deliberate pull release. Then assemble the real dock and tray, confirm full seating, a perceptible click and no PSU rocking, and complete 20 insertion/removal cycles without cracks or permanent flexure deformation. Record physical acceptance separately from CAD and slicer validation.

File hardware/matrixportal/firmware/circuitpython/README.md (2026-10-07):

# MatrixPortal S3 CircuitPython 10.3.0 Wi-Fi cap

This patch sets the MatrixPortal S3 radio's compile-time default transmit power to 8 dBm and waits 10 seconds before CircuitPython's native Web Workflow first enables Wi-Fi. This protects the automatic connection that happens before `boot.py` and `code.py`. Later radio starts also use the 8 dBm default. The application keeps its own 8 dBm setting as a second guard and reuses a connection that the patched runtime has already delayed and capped.

The patch is based on Adafruit CircuitPython 10.3.0, commit `d897c15f24b2a6de6529f138aed4705327020dab`. It changes the MatrixPortal S3 board configuration and the Web Workflow Wi-Fi startup path.

## Rebuild

In an Adafruit CircuitPython 10.3.0 checkout with the Espressif build prerequisites installed:

```sh
git apply --unidiff-zero /path/to/matrixportal-s3-wifi-default-8dbm.patch
make -C ports/espressif BOARD=adafruit_matrixportal_s3
```

The resulting image is `ports/espressif/build-adafruit_matrixportal_s3/firmware.uf2`. The tested build used ESP-IDF 6.0 and the board's normal Web Workflow and BLE feature configuration. BLE is left enabled so the first hardware test isolates the Wi-Fi default change.

## Hardware test

1. Back up the board's `settings.toml` and `settings_local.py` before installing firmware.
2. Connect the board to the laptop by USB. Double-tap RESET to mount `MATRXS3BOOT`, then copy the custom `firmware.uf2` onto that drive. Wait for `CIRCUITPY` to remount.
3. To test native Web Workflow, add `CIRCUITPY_WIFI_SSID` and `CIRCUITPY_WIFI_PASSWORD` to the board's `settings.toml`, copying the values locally from the existing application `WIFI_SSID` and `WIFI_PASSWORD` entries. Keep the existing `CIRCUITPY_WEB_API_PASSWORD` entry. Do not paste credentials into logs or tickets.
4. Keep the existing root `boot.py` radio-off guard. The first Web Workflow attempt is delayed and capped by the patched runtime; `boot.py` then disables Wi-Fi, and the post-boot Workflow restart is delayed and capped again. Application startup preserves that active connection rather than cycling the radio.
5. Reset on laptop power first. Allow up to 20 seconds for the post-boot Workflow restart, confirm `/cp/version.json` responds, then check serial output for `Wi-Fi already connected tx_power_dbm=8`.
6. Move the same USB cable and board to the wall supply that previously caused the loop. Check Web Workflow reachability and whether the board remains running through repeated resets and a longer soak. Record the firmware version, supply, connection result, and reset observations.
7. If the test is unstable, return to laptop power and restore the saved settings and `boot.py`. The stock UF2 can be reinstalled from the Adafruit MatrixPortal S3 download page.

This compile proves the patched firmware image builds; it does not prove radio behavior or stability on the physical board. The test should be treated as an experimental firmware install.

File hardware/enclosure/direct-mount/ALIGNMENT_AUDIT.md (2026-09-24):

# Direct-mount enclosure alignment audit

This audit tracks the mechanical files referenced by issue #76 and later enclosure follow-ups.

The distinction is important:

- **CAD-aligned** means the mating coordinates are derived from the same source or explicitly checked in CI.
- **Physically validated** requires a real printed part / real LED panel / real MatrixPortal fit test.

## Part/interface audit

| Part | Interface checked | CAD status | Physical status |
| --- | --- | --- | --- |
| `stl/01_backplane_module_PRINT_3.stl` | P4 bosses, locator clearances, seam tongues, joiner inserts, accessory inserts, lid sockets | Aligned to current source | One real backplane still required |
| `stl/01b_backplane_right_end_PRINT_1.stl` | Same as standard backplane, without unused outer seam features | Aligned to current source | One real fit still required |
| `stl/02_module_joiner_PRINT_4.stl` | Four M3 holes vs neighbouring backplane inserts | **Corrected in this audit**: local y=9/51 at installed y=34 gives global y=43/85 | Print/assemble one seam |
| `stl/03_rod_end_plug_PRINT_4.stl` | 7.2 mm reinforcement bore | Concentric/sized from common source | Retention fit remains physical |
| `stl/04_matrixportal_mount_PRINT_1.stl` | Carrier M3 holes vs Panel 1 accessory inserts; MatrixPortal four-hole pattern | Carrier holes align exactly. Board orientation corrected to landscape | Fit real MatrixPortal |
| `stl/05_power_distribution_mount_PRINT_1.stl` | Carrier M3 holes vs Panel 2 accessory inserts | Aligns exactly | Fit selected power hardware |
| `stl/06_cable_clip_PRINT_8.stl` | Independent screw-down accessory | No fixed panel coordinate required | Fit cable bundle |
| `stl/07_mounting_slot_coupon_PRINT_1.stl` | Heat-set insert pilot/depth | Reproduces production insert geometry | Print first for insert fit |
| `stl/08_mount_pattern_template_PRINT_1.stl` | Six panel bosses + four locator clearances | Uses the same source coordinates as structural backplanes | Current physical template test remains source of truth |
| `stl/09_centre_boss_desk_stand_PRINT_3.stl` | Lower-centre panel boss | Local stand screw maps to x=128, y=7.9 | Stability/screw length still physical |
| `stl/10_rear_lid_PRINT_4.stl` | Four snap pegs vs four backplane sockets | **Corrected in this audit**: same XY coordinate system and exact centres | Print one PETG lid |

## Key coordinate checks

### Panel mounting

Current physical-fit-corrected panel boss centres:

- x = 7.9 / 128.0 / 248.1 mm
- y = 7.9 / 120.1 mm

The mounting template and both structural backplanes use these same source variables.

### Seam joiner

For each PRINT_4 joiner set:

- installed joiner origin y = 34 mm
- local screw rows y = 9 / 51 mm
- installed screw rows y = **43 / 85 mm**

These now match the backplane joiner heat-set insert rows exactly.

### MatrixPortal carrier-to-backplane

Carrier-local M3 holes:

- x = 6 / 238 mm
- y = 6 / 66 mm

Panel 1 carrier translation:

- x = +6 mm
- y = +28 mm

Installed carrier holes therefore become:

- x = **12 / 244 mm**
- y = **34 / 94 mm**

These exactly match the Panel 1 backplane accessory inserts. The power carrier uses the same local interface on Panel 2.

### MatrixPortal board direction

The MatrixPortal S3 is represented as:

- **63.50 mm long dimension along X**
- **44.45 mm short dimension along Y**
- the **short USB/button edge** faces the outside/left edge of Panel 1
- approximately 10 mm of board overhang is reserved for access

The previous portrait representation exposed the long edge and was not consistent with the physical controller orientation.

### Rear lid

Backplane socket centres:

- x = 64 / 192 mm
- y = 8 / 120 mm

Lid snap-peg centres are now exactly the same values. The lid also uses the same 255 × 127 mm rear footprint coordinate system, removing the former hidden +2 mm placement offset.

See `schematics/10_rear_lid_alignment_ASSEMBLY.scad`.

## CI coverage

`assembly_validation.json` now includes point-level checks for:

- all three seam-joiner screw patterns;
- MatrixPortal carrier M3 holes vs Panel 1 accessory inserts;
- power carrier M3 holes vs Panel 2 accessory inserts;
- lid peg centres vs socket centres;
- desk-stand lower-centre boss alignment.

Collision/interference and connected-component checks still run in addition to these coordinate checks.

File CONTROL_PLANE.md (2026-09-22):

# LED runtime control plane

The runtime control plane changes operational LED behaviour without rebuilding or redeploying the Lambda package. It is deliberately separate from deployment configuration and secrets.

## Architecture

The scheduled `led-publisher` Lambda still runs once per minute. On every invocation it reads the current runtime configuration from DynamoDB, refreshes only feeds that are enabled and due, preserves last-successful feed state in the private S3 state prefix, and publishes the renderer-neutral `/api/screens` object through CloudFront.

The `led-control-api` Lambda is reached through the same public LED hostname at `/api/control/v1/*`. It validates the Cloudflare Access application JWT itself before reading or mutating configuration. A successful mutation uses a DynamoDB conditional write and asynchronously invokes the publisher so display changes normally apply immediately rather than waiting for the next scheduled tick.

`/api/screens` and the public simulator remain outside Cloudflare Access. `/admin*` and `/api/control/v1/*` are the protected control plane.

## Runtime versus deployment configuration

DynamoDB contains only non-secret settings that are safe to change at runtime. The stable v1 feeds are:

| Feed | Provider | Mutable settings |
| --- | --- | --- |
| `departures` | National Rail | `enabled`, `poll_seconds`, `screen_duration_seconds` |
| `thorpe_park` | Queue-Times park 2 | `enabled`, `poll_seconds`, `screen_duration_seconds`, ordered `rides` |
| `chessington` | Queue-Times park 3 | `enabled`, `poll_seconds`, `screen_duration_seconds`, ordered `rides` |
| `weather` | Open-Meteo | `enabled`, `poll_seconds` |
| `calendar` | Todoist | `enabled`, `poll_seconds`, `screen_duration_seconds` |
| `flash` | Pending MQTT event path | `enabled`, `screen_duration_seconds` (default 5) |

`poll_seconds` is between 60 and 86400 seconds. Screen duration is between 2 and 300 seconds. Queue-Times `park_id` is implementation metadata and cannot be patched.

Deployment settings still own provider credentials, station CRS, weather coordinates, Todoist OAuth storage, AWS resource names, and Cloudflare Access validation metadata. The control API has no endpoint for arbitrary environment variables and its IAM role does not receive National Rail or Todoist credentials.

If the DynamoDB item does not exist, callers see safe defaults derived from the deployment configuration. The first authenticated configuration read seeds those defaults as version 1. After that, the DynamoDB values are authoritative for supported runtime fields.

## Control API

All endpoints return JSON and `Cache-Control: no-store`. Configuration responses include an `ETag` containing the current numeric configuration version.

### Read configuration

`GET /api/control/v1/config`

Returns the effective configuration, `config_version`, `updated_at`, `updated_by`, field limits, provider/display metadata, and live ride choices for Queue-Times feeds.

### Read status

`GET /api/control/v1/status`

Returns enabled state, provider, health, last successful refresh, last attempted refresh, stale state and effective polling interval for every feed, plus the timestamp and config version currently published in `/api/screens`. Provider exception bodies and secrets are never returned.

### Read ride choices

`GET /api/control/v1/feeds/{feed_id}/options`

This is available for `thorpe_park` and `chessington`. Choices come from the most recent cached Queue-Times response when possible, with a live Queue-Times lookup as fallback. If Queue-Times is temporarily unavailable, the currently configured ride names remain usable.

### Patch one feed

`PATCH /api/control/v1/feeds/{feed_id}` accepts any subset of that feed's mutable fields. Unknown feed IDs and fields are rejected. Queue-Times ride names are validated case-insensitively against current known rides and stored using the provider's canonical names while preserving the requested order.

Use either `If-Match` with the current ETag or a numeric `config_version` field in the JSON body. A stale version returns `412 Precondition Failed`.

Example after authenticating through Cloudflare Access:

```bash
curl -X PATCH "https://led.alf-broadcast.co.uk/api/control/v1/feeds/chessington" \
  -H 'Content-Type: application/json' \
  -H 'If-Match: "8"' \
  --data '{
    "enabled": true,
    "poll_seconds": 300,
    "screen_duration_seconds": 10,
    "rides": ["Vampire", "Dragon's Fury", "Mandrill Mayhem"]
  }'
```

After the conditional write succeeds, the control Lambda logs the actor type, feed ID, changed fields, old/new version and request ID, then invokes the publisher asynchronously.

## Cloudflare Access setup

The repository intentionally does not contain Cloudflare service-token credentials or a second interactive authentication system. Configure Access on the existing LED hostname using the existing Google identity provider and existing reusable two-user allow policy.

Use two path-scoped Access applications so the Home Assistant service token never grants access to the HTML admin page:

1. Protect `https://<led-host>/admin*` with the existing interactive Google/two-user allow policy only.
2. Protect `https://<led-host>/api/control/v1/*` with the same human allow policy plus a Service Auth policy that includes the dedicated Home Assistant service token.
3. Do not add an Access application covering `https://<led-host>/api/screens` or the public simulator path.

Set these GitHub repository variables before production deployment:

- `CF_ACCESS_TEAM_DOMAIN`: the full Access team domain, for example `https://example.cloudflareaccess.com`.
- `CF_ACCESS_AUD`: the audience tag of the Access application protecting `/api/control/v1/*`.

The backend fetches and caches Access public keys from `<team-domain>/cdn-cgi/access/certs` and validates RS256 signature, issuer, application audience and expiry on every API request. This validation also runs when the API Gateway hostname is called directly, so bypassing Cloudflare does not bypass origin authentication.

Human Access JWTs are audited as `human:<email>`. Service-token JWTs are audited separately as `machine:<service identity>`.

## Home Assistant

Store the Cloudflare service-token values only in Home Assistant secrets, never in this repository:

```yaml
# secrets.yaml
led_cf_access_client_id: "<service-token-client-id>"
led_cf_access_client_secret: "<service-token-client-secret>"
```

A REST sensor can expose the current control-plane status:

```yaml
rest:
  - resource: https://led.alf-broadcast.co.uk/api/control/v1/status
    headers:
      CF-Access-Client-Id: !secret led_cf_access_client_id
      CF-Access-Client-Secret: !secret led_cf_access_client_secret
    scan_interval: 60
    sensor:
      - name: LED Thorpe Park health
        value_template: "{{ value_json.feeds.thorpe_park.health }}"
        json_attributes_path: "$.feeds.thorpe_park"
        json_attributes:
          - enabled
          - poll_seconds
          - last_successful_refresh
          - stale
```

For mutations, first expose `config_version` from `GET /api/control/v1/config`, then send that version with the desired patch. Passing the version in the body avoids needing a dynamically generated `If-Match` header:

```yaml
rest_command:
  led_set_feed:
    url: "https://led.alf-broadcast.co.uk/api/control/v1/feeds/{{ feed_id }}"
    method: PATCH
    headers:
      Content-Type: application/json
      CF-Access-Client-Id: !secret led_cf_access_client_id
      CF-Access-Client-Secret: !secret led_cf_access_client_secret
    payload: >-
      {"config_version": {{ config_version }}, "enabled": {{ enabled | lower }}}
```

The same API maps naturally to REST-backed switches, input-number controls, scripts/buttons and stale/refresh sensors. No Home Assistant-specific fields are stored in DynamoDB.

## Ride selection behaviour

Thorpe Park and Chessington use the same Queue-Times normalization/provider code. Ride selection is ordered. If a previously configured attraction disappears or is renamed upstream, the publisher ignores that missing ride, logs/flags it in the published park screen as `missing_configured_rides`, and continues rendering any remaining configured rides. Every Queue-Times screen retains Queue-Times attribution.

The admin UI obtains choices from the API rather than hard-coding attractions, so new rides can appear without a frontend deployment once Queue-Times reports them.

## Flash events

The `flash` setting owns only operational controls for transient events. It is
disabled by default and does not make the backend ingest Alexa reminders. The
future Home Assistant publisher owns the event payload and will publish it to
the board's configured MQTT topic after issue #3 is complete. The board-side
MQTT connection currently requires both `MQTT_ENABLED` and the explicit
`MQTT_ENABLE_EXPERIMENTAL` safety gate; both are false in `firmware/settings.py`.
The public `/api/screens` response carries the effective non-secret `flash`
settings so the board can apply admin changes on its normal HTTP refresh path;
it never carries broker credentials or reminder payloads.

## Local development and testing

Production authentication has no bypass flag. Unit tests inject a test signing key/JWK client or mock the authenticator at the Lambda boundary. This keeps local tests deterministic without adding a production environment variable that could accidentally disable authentication.

Run the repository suite with:

```bash
python -m pip install -r requirements-server.txt
bash scripts/run-tests.sh
```

For end-to-end testing, use the public LED hostname through Cloudflare Access. Calling the generated API Gateway URL without a valid `Cf-Access-Jwt-Assertion` must return `401`.

## Seed and reset

The DynamoDB table is retained across stack replacement/deletion. The control plane stores a single item with `config_id=runtime`.

To seed a new installation, deploy the stack and perform an authenticated `GET /api/control/v1/config`; the control Lambda conditionally writes version 1 from deployment defaults.

Reset is intentionally not exposed through the control API. An operator with separate AWS administration rights can delete only the `runtime` item from the `led-runtime-config` table, then perform an authenticated configuration GET to reseed it. Take care: this discards the current runtime settings and ride selections.

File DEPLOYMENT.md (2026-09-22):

# AWS deployment

Issue #74 adds a dormant MQTT flash-event path for generic reminder screens.
It is intentionally not enabled: `MQTT_ENABLED` and
`MQTT_ENABLE_EXPERIMENTAL` are both false, and no broker settings or
credentials are committed. Do not enable either gate until Home Assistant
issue #3, the normalized event contract, broker reachability and outage
behaviour have been reviewed together.

When that gate is eventually approved, the board will additionally need the
CircuitPython `adafruit_minimqtt` library copied to `CIRCUITPY/lib`. Until then
the library is intentionally not imported by the normal boot path.

The production LED backend is serverless and publishes a static renderer-neutral snapshot instead of running `backend/server.py` continuously.

```text
EventBridge Scheduler (1 minute)
        |
        v
  led-publisher Lambda <----> SSM Parameter Store
   |      |       |             /led/todoist/oauth SecureString
 Darwin  Queue-  Todoist
         Times      |
   |                |
   +------ Open-Meteo
        |
        v
 private S3 hosting/state bucket
 ├── index.html
 ├── api/screens
 └── state/feed-cache.json
        |
        v
 CloudFront + OAC
        |
 Windsor Cloudflare DNS (proxied for Access)
        |
 led.alf-broadcast.co.uk
   /             \
 browser      MatrixPortal
```

Lambda deployment packages are stored separately in a dedicated private bucket named `led-code-eu-west-2-<aws-account-id>`. The LED project does not use the shared Scouts/general Lambda code bucket.

`state/feed-cache.json` is never exposed through CloudFront. The CloudFront origin policy permits only `index.html` and `api/*`, while Lambda has separate read/write access to the private state object.

> **Privacy:** `/api/screens` is publicly retrievable through CloudFront. The Todoist feed is therefore `off` by default. Enabling it publishes the selected Todoist task names and scheduled dates/times into that public JSON object. Use a deliberately narrow filter/project/label if that exposure is acceptable, or protect/personalize the screen endpoint before enabling private task data.

## Deployment and secret conventions

GitHub Actions and runtime secrets are deliberately separated:

- GitHub Actions authenticates to AWS with GitHub OIDC; there are no long-lived AWS access keys in GitHub.
- deployment-time secrets are AWS Systems Manager Parameter Store **Standard `SecureString`** parameters under `/led/deploy/*`;
- `GitHubActionsLedDeployRole` may read only `/led/deploy/*` and cannot read `/led/todoist/oauth`;
- the workflow assumes the AWS role first, then runs `scripts/load-ssm-secrets.sh`, which decrypts, masks and exports the required values through `GITHUB_ENV`;
- the National Rail token continues to flow through the existing `NoEcho` CloudFormation parameter into the publisher Lambda;
- the Cloudflare API token remains deployment-only and never reaches Lambda;
- Todoist OAuth remains runtime-managed in `/led/todoist/oauth`, which the publisher Lambda can decrypt and update as Todoist rotates refresh tokens;
- Cloudflare DNS is constrained to the **Windsor** account; deployment must not use the Scouts account;
- the bootstrap stack owns the repo-scoped GitHub OIDC role, CloudFormation execution role and dedicated private Lambda artifact bucket.

The deployment parameters are:

```text
/led/deploy/national-rail-token     -> NATIONAL_RAIL_TOKEN
/led/deploy/cloudflare/api-token    -> CF_DEPLOY_API_TOKEN
```

Both are Standard `SecureString` parameters using the default AWS-managed SSM key. No customer-managed KMS permission is required by the GitHub role.

Todoist is intentionally outside that hierarchy:

```text
/led/todoist/oauth
```

Do not move, duplicate or expose the Todoist OAuth parameter to CI.

## GitHub repository settings

GitHub stores only non-secret deployment configuration.

Required variables:

- `AWS_ROLE_TO_ASSUME` — output `AwsRoleToAssume` from the `led-bootstrap` stack.
- `CLOUDFORMATION_ROLE_ARN` — output `CloudFormationRoleArn` from the bootstrap stack.
- `CLOUDFLARE_ACCOUNT_ID` — the 32-character Cloudflare account ID for the **Windsor** account.
- `CF_ACCESS_TEAM_DOMAIN` — the existing Cloudflare Access team domain.
- `CF_ACCESS_AUD` — the existing Cloudflare Access application audience tag.
- `LED_DEPLOY_SSM_PREFIX` — normally `/led/deploy`; the workflow defaults to that value.

Optional variables include `LED_DOMAIN_NAME`, `LED_CF_ZONE_NAME`, `LED_CALENDAR_SOURCE`, the `LED_TODOIST_*` timing/filter settings and the other feed configuration documented in the repository.

`CODE_BUCKET` is intentionally not required as a GitHub variable. CI derives `led-code-eu-west-2-<aws-account-id>` after assuming the LED AWS role and verifies that the bucket exists.

The workflow validates non-secret configuration before AWS authentication. Secret existence/readability is then validated by the SSM loader after OIDC succeeds. Missing or unreadable parameters fail the deployment without printing their values.

## First-time AWS bootstrap

The AWS account needs a GitHub Actions OIDC provider. If one already exists, the LED bootstrap script reuses it; otherwise the script creates the account-level provider.

Run with an AWS principal allowed to create/update IAM roles and S3 buckets:

```bash
AWS_PROFILE=<admin-profile> \
bash scripts/bootstrap-deployment-role.sh
```

The `led-bootstrap` stack creates or updates:

- `GitHubActionsLedDeployRole`, trusted only for `antonio1000homens/led` on `master`;
- `LedCloudFormationExecutionRole`, used by CloudFormation for the LED infrastructure;
- `led-code-eu-west-2-<aws-account-id>`, a dedicated encrypted/private Lambda artifact bucket;
- the narrowly scoped `ssm:GetParameter` permission for `parameter/led/deploy/*` on the GitHub deploy role.

The SSM deployment secret values are not CloudFormation resources. `AWS::SSM::Parameter` does not create `SecureString` values, so the migration/bootstrap script writes them directly through the authenticated AWS CLI.

The Todoist SSM parameter is also intentionally not created by CloudFormation. `scripts/bootstrap-todoist-oauth.py` creates or updates `/led/todoist/oauth`, while the main runtime stack grants only the publisher its separate runtime access.

## Migrate deployment secrets from Bitwarden to SSM

The repository includes an idempotent migration helper based on the recordings repository pattern:

```text
scripts/bootstrap-ssm-migration.sh
config/bootstrap-ssm-migration.env.example
```

Prerequisites are authenticated `aws`, `gh` and `bws` CLIs plus `jq`.

Create the ignored local config if desired:

```bash
cp config/bootstrap-ssm-migration.env.example config/bootstrap-ssm-migration.env
```

The script normally discovers the Bitwarden logical keys `NATIONAL_RAIL_TOKEN` and `CF_DEPLOY_API_TOKEN`. If discovery is ambiguous, set the existing Bitwarden secret UUIDs locally with `BW_NATIONAL_RAIL_TOKEN` and `BW_CF_DEPLOY_API_TOKEN`. Those variables are IDs only, never secret values.

Validate everything without changing AWS or GitHub first:

```bash
bash scripts/bootstrap-ssm-migration.sh --dry-run
```

Then perform the migration:

```bash
bash scripts/bootstrap-ssm-migration.sh
```

The real run:

1. validates AWS, GitHub and Bitwarden authentication;
2. validates `infrastructure/bootstrap.yaml`;
3. updates the existing `led-bootstrap` stack so `GitHubActionsLedDeployRole` can read only `/led/deploy/*`;
4. reads each Bitwarden value only when it is about to be written;
5. creates/updates `/led/deploy/national-rail-token` and `/led/deploy/cloudflare/api-token` as Standard `SecureString` parameters with overwrite enabled;
6. validates parameter names/types without decrypting or printing values;
7. writes only non-secret GitHub variables (`AWS_ROLE_TO_ASSUME`, `CLOUDFORMATION_ROLE_ARN`, `LED_DEPLOY_SSM_PREFIX`).

Secret values are passed to AWS through restrictive temporary request files/stdin rather than command-line arguments. Rerunning the script is safe and can refresh or rotate the two SSM values from Bitwarden during the migration window.

### Production validation and Bitwarden cleanup

After the parameters exist, run the production deployment workflow and verify:

- Lambda/package deployment succeeds;
- National Rail data is published;
- ACM validation and LED DNS updates succeed in the Windsor Cloudflare account;
- the Todoist screen remains healthy and `/led/todoist/oauth` is unchanged.

Only after that validation should the obsolete GitHub Bitwarden configuration be removed. The old settings were `BW_ACCESS_TOKEN`, `BW_NATIONAL_RAIL_TOKEN` and `BW_SECRET_ID_CF_DEPLOY_API_TOKEN`. They are no longer referenced by the active workflow.

For example, using an authenticated GitHub CLI:

```bash
gh secret delete BW_ACCESS_TOKEN --repo antonio1000homens/led
gh variable delete BW_NATIONAL_RAIL_TOKEN --repo antonio1000homens/led
gh variable delete BW_SECRET_ID_CF_DEPLOY_API_TOKEN --repo antonio1000homens/led
```

Remove the LED Bitwarden machine-account/project access as well if it is not used by any local-development workflow.

### Rotation after migration

During the migration window, rerun `scripts/bootstrap-ssm-migration.sh` after changing the source values in Bitwarden. The script overwrites the existing SSM parameters safely.

After Bitwarden access has been retired, rotate the values directly in Parameter Store using an authenticated administrative workflow that writes a Standard `SecureString` without placing the value in shell history or process arguments. Keep the names unchanged so GitHub requires no workflow change.

## Automated deployment

A push to `master`, or a manual `workflow_dispatch`, performs the production deployment:

1. run the Python unit/infrastructure tests;
2. validate non-secret configuration;
3. assume `GitHubActionsLedDeployRole` using GitHub OIDC;
4. decrypt, mask and export the National Rail and Windsor Cloudflare deployment secrets from `/led/deploy/*`;
5. derive and verify the dedicated `led-code-eu-west-2-<aws-account-id>` bucket;
6. request or reuse the `led.alf-broadcast.co.uk` ACM certificate in `us-east-1`;
7. create/update the ACM validation CNAME in the Windsor Cloudflare account and wait for issuance;
8. package the Lambda and upload it to the dedicated LED code bucket;
9. deploy `infrastructure/led-stack.yaml` through `LedCloudFormationExecutionRole`;
10. upload simulator/admin static content;
11. invoke the publisher once so `/api/screens` exists immediately;
12. verify the Todoist screen when enabled;
13. create/update the proxied LED hostname in Windsor Cloudflare;
14. invalidate the published CloudFront paths.

Subsequent deployments reuse the existing certificate, bucket and DNS records. Todoist OAuth state remains in SSM independently of stack deployments.

## Todoist production configuration

The CloudFormation defaults keep Todoist disabled:

```text
LED_CALENDAR_SOURCE=off
LED_TODOIST_CACHE_SECONDS=300
LED_TODOIST_MAX_EVENTS=6
LED_TODOIST_FILTER_QUERY=date after: yesterday
LED_TODOIST_TIMEZONE=Europe/London
LED_CALENDAR_DURATION_SECONDS=10
LED_CALENDAR_PAGE_SECONDS=5
```

### Initial OAuth exchange

For a new Todoist integration with a Client ID and Client Secret:

1. Keep `LED_CALENDAR_SOURCE=off` initially.
2. In Todoist App Management, register `http://127.0.0.1:8765/callback` as an OAuth redirect URL, or choose another URI and pass it through `TODOIST_REDIRECT_URI`.
3. Run:

```bash
TODOIST_CLIENT_ID='<client-id>' \
AWS_PROFILE='<aws-profile>' \
python3 scripts/bootstrap-todoist-oauth.py
```

The script prompts securely for the Client Secret, requests the read-only `data:read` scope, opens Todoist authorization in the browser, verifies the returned OAuth `state`, exchanges the code at `https://api.todoist.com/oauth/access_token`, and writes the client credentials plus access/refresh tokens into `/led/todoist/oauth` as an SSM Parameter Store Standard `SecureString`. It never prints the Client Secret or tokens.

If a localhost callback is not suitable, run with `--manual` and paste the complete redirected callback URL. If the registered callback differs from the default, set `TODOIST_REDIRECT_URI` or pass `--redirect-uri`.

4. Set GitHub repository variable `LED_CALENDAR_SOURCE=todoist` and run the deployment workflow.

No Todoist Client Secret, access token or refresh token is placed in GitHub Actions variables, CloudFormation parameters, `/api/screens`, S3 feed state, simulator code or MatrixPortal configuration.

### Migrating the previous Secrets Manager OAuth secret

If OAuth was already bootstrapped into the old Secrets Manager resource, do not authorize Todoist again. Copy the existing JSON into the Standard `SecureString`:

```bash
AWS_PROFILE='<aws-profile>' \
python3 scripts/bootstrap-todoist-oauth.py \
  --migrate-secret-id '<existing-secrets-manager-arn>'
```

After the SSM-backed stack has deployed and the Todoist calendar is verified, schedule the old Secrets Manager secret for deletion with a recovery window rather than forcing immediate deletion.

### Runtime refresh-token rotation

New Todoist applications issue short-lived access tokens and rotating refresh tokens. The publisher decrypts `/led/todoist/oauth`, reuses a still-valid access token, and refreshes shortly before expiry. Every successful refresh is persisted immediately because the returned refresh token replaces the consumed token.

If Todoist returns `401`, the provider forces one refresh and retries once. If a refresh response omits the replacement refresh token, the provider fails closed and the OAuth bootstrap must be run again.

## Cloudflare account safety

There are separate Scouts and Windsor Cloudflare accounts. LED is explicitly a Windsor service.

Set `CLOUDFLARE_ACCOUNT_ID` to the **Windsor** account ID. The deployment helper calls Cloudflare's zone-list API with an `account.id` filter and verifies the returned account name is `Windsor` before modifying DNS. The API token must also have access to the `alf-broadcast.co.uk` zone in that account.

The Scouts Cloudflare account ID must never be configured for LED.

## Manual deployment

For diagnosis or a first deployment outside GitHub Actions, obtain the deployment secrets from SSM using an authenticated AWS identity that is allowed to read `/led/deploy/*`, then export them only in the local process environment:

```bash
export NATIONAL_RAIL_TOKEN="$(aws ssm get-parameter --region eu-west-2 --name /led/deploy/national-rail-token --with-decryption --query Parameter.Value --output text)"
export CF_DEPLOY_API_TOKEN="$(aws ssm get-parameter --region eu-west-2 --name /led/deploy/cloudflare/api-token --with-decryption --query Parameter.Value --output text)"
export CLOUDFLARE_ACCOUNT_ID='<Windsor Cloudflare account id>'
export CLOUDFORMATION_ROLE_ARN='<bootstrap stack output>'

bash scripts/deploy.sh
```

For a Todoist-enabled deployment, OAuth must already be bootstrapped into `/led/todoist/oauth`; set `LED_CALENDAR_SOURCE=todoist` as required.

The component scripts can also be run independently:

```bash
bash scripts/request-acm-certificate.sh
bash scripts/configure-cloudflare-dns.sh
bash scripts/package-lambda.sh
bash scripts/deploy-stack.sh
bash scripts/deploy-static.sh
python3 scripts/bootstrap-todoist-oauth.py
```

## Runtime behaviour

EventBridge Scheduler invokes `led-publisher` once per minute. The Lambda loads the previous state from S3 and independently applies the configured refresh intervals:

- National Rail: 60 seconds;
- queue feeds: 300 seconds;
- Todoist calendar: 300 seconds when enabled;
- Open-Meteo weather: 600 seconds.

If a feed refresh fails after a prior successful result, the last successful data remains in the published screen payload with `stale: true`. A cold Todoist/OAuth failure affects only the calendar screen; rail/queue/weather screens continue to publish.

The Lambda replaces `api/screens` with one complete S3 `PutObject`; S3 object replacement is atomic, so readers never observe partially written JSON. CloudFront caching is disabled for `api/screens`.

## MatrixPortal

Configure the physical board with:

```python
SCREEN_SOURCE = "api"
SCREEN_API_URL = "https://led.alf-broadcast.co.uk"
POLL_SECONDS = 30
```

The client requests `${SCREEN_API_URL}/api/screens`; no National Rail, Todoist, Queue-Times, Open-Meteo, AWS, Cloudflare, SSM or OAuth credentials are stored on the MatrixPortal.

## Cost characteristics

There is no always-on EC2, ECS/Fargate, App Runner, NAT Gateway, or Secrets Manager runtime dependency. Deployment secrets and Todoist OAuth state use SSM Parameter Store Standard `SecureString` parameters with the default AWS-managed SSM key. The dedicated Lambda code bucket stores only deployment packages. Lambda, Scheduler, S3, CloudFront and standard Parameter Store usage should remain very small at this project's scale, subject to the account's aggregate usage and current AWS pricing.

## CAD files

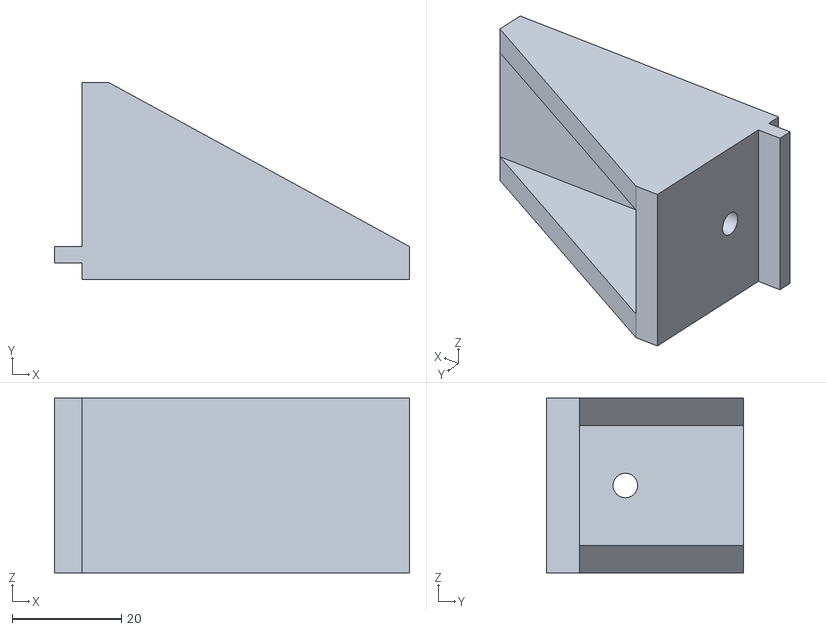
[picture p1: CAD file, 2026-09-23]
hardware/enclosure/direct-mount/09_centre_boss_desk_stand_PRINT_2.stl
65.0 x 36.0 x 32.0

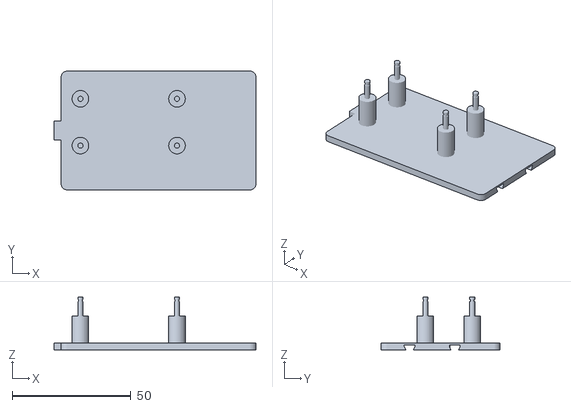
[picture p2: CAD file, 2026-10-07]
hardware/enclosure/stl/10_matrixportal_s3_carrier_PRINT_1.stl
85.0 x 50.0 x 22.2

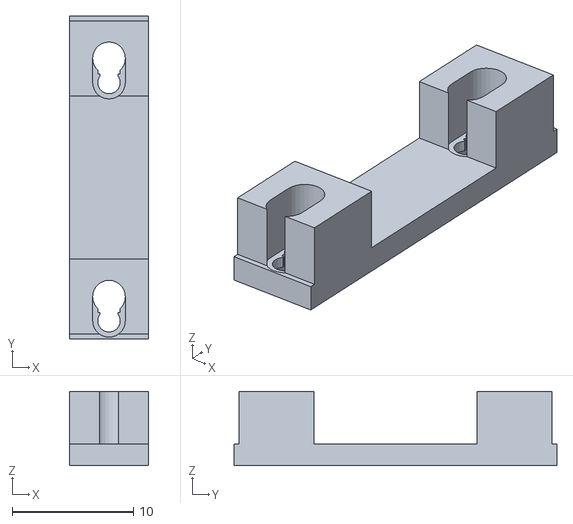
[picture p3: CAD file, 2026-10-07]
hardware/enclosure/stl/11_matrixportal_s3_keeper_PRINT_1.stl
6.50 x 26.7 x 6.15

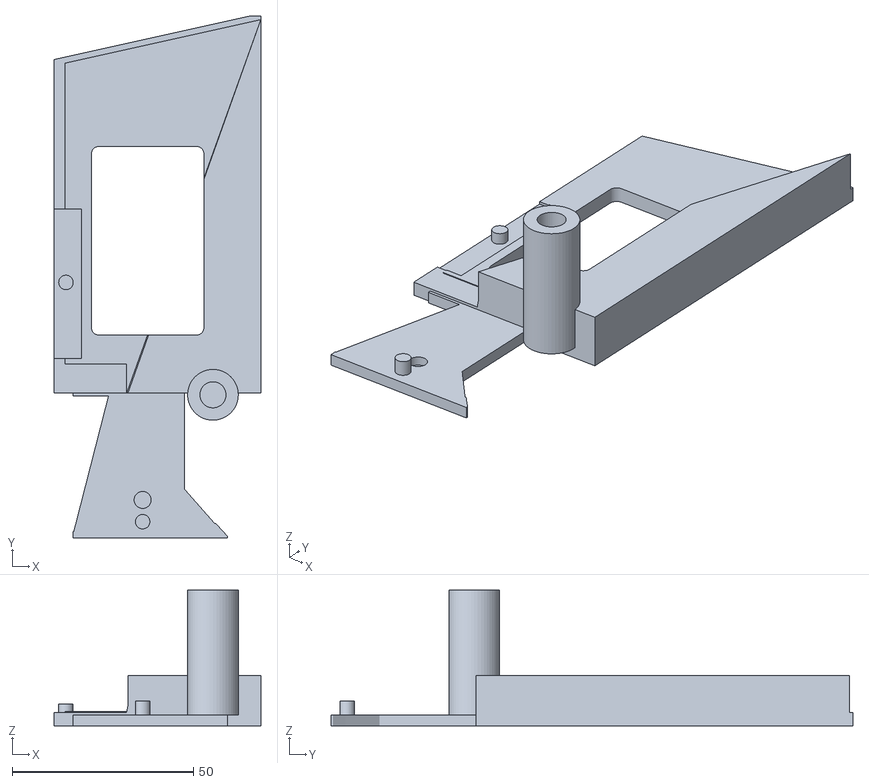
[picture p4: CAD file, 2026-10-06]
hardware/enclosure/stl/09_left_equipment_side_matrixportal_PRINT_1.stl
57.0 x 144.0 x 37.4

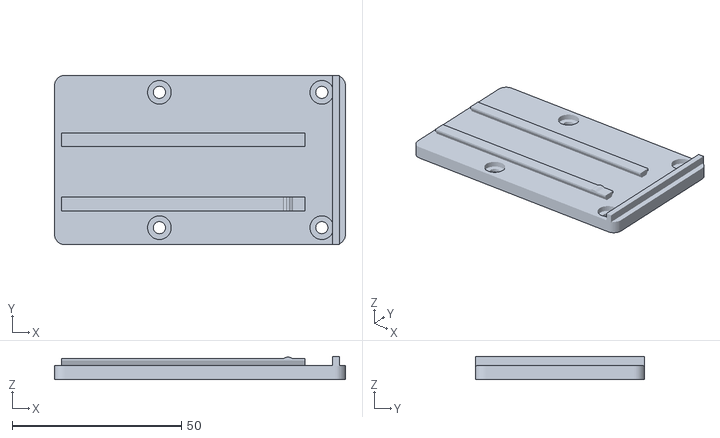
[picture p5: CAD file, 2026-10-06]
hardware/enclosure/stl/08_matrixportal_s3_dock_PRINT_1.stl
86.0 x 50.0 x 6.80

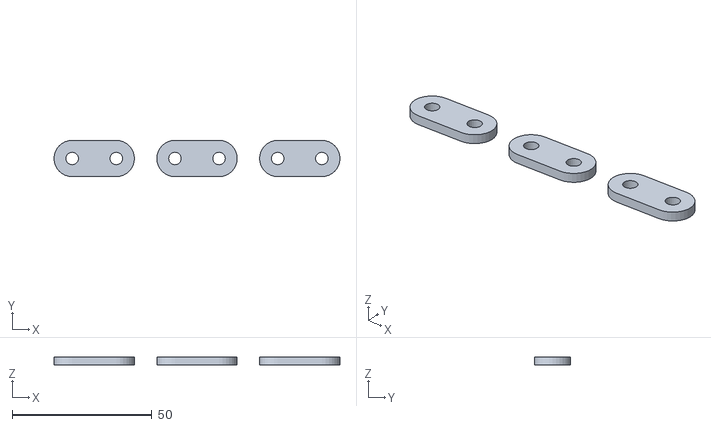
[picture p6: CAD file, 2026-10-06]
hardware/enclosure/stl/10_panel_pair_joiner_PRINT_3.stl
102.4 x 13.0 x 3.00

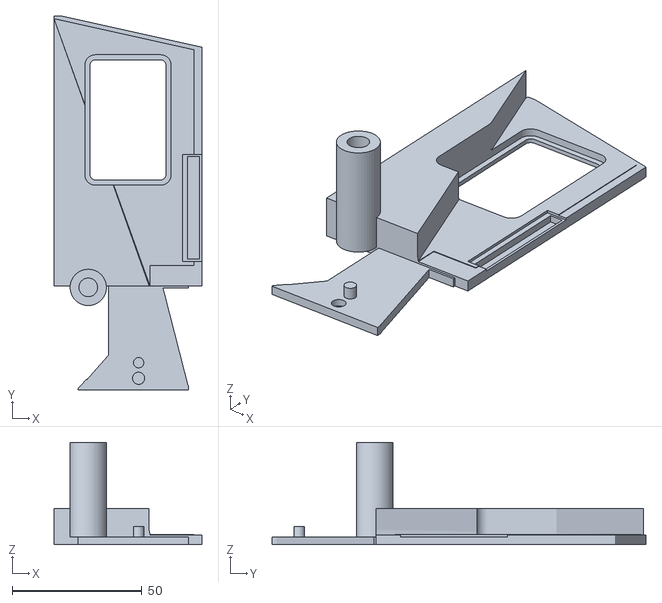
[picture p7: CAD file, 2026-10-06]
hardware/enclosure/stl/05_right_equipment_side_PRINT_1.stl
57.0 x 144.0 x 39.4

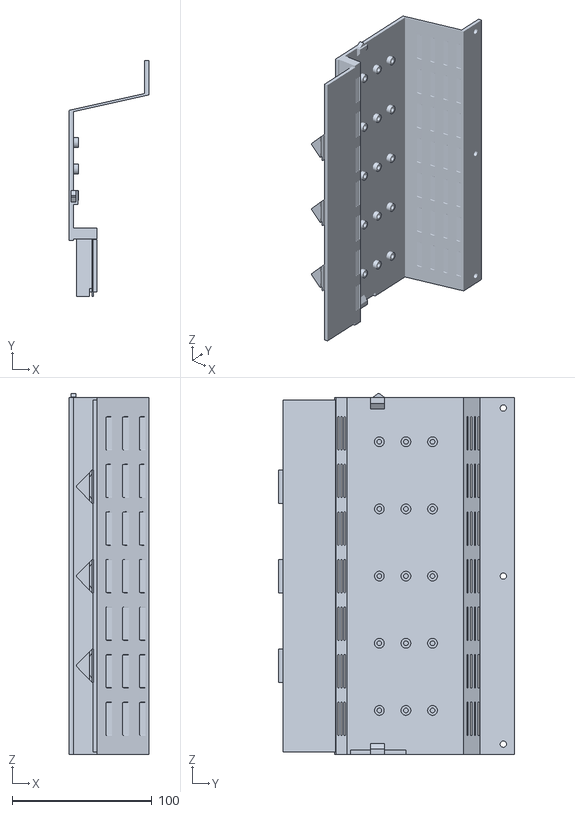
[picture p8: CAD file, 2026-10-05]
hardware/enclosure/stl/03_universal_equipment_backplane_PRINT_1.stl
57.0 x 168.5 x 258.0

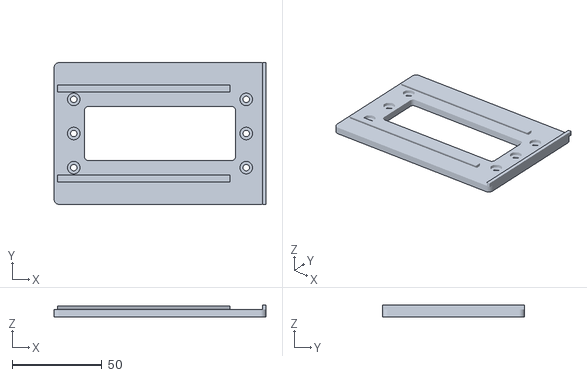
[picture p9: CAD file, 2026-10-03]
hardware/enclosure/stl/06_psu_service_tray_snap_dock_PRINT_1.stl
118.0 x 79.0 x 6.60

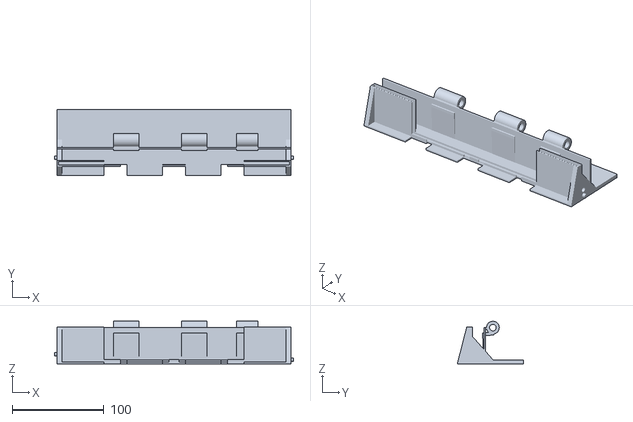
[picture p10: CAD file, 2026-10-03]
hardware/enclosure/stl/02_hinged_equipment_base_PRINT_1.stl
261.0 x 72.0 x 46.5

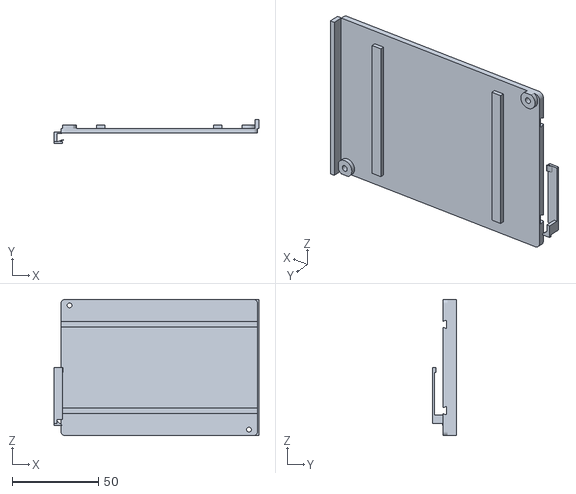
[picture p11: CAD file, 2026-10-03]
hardware/enclosure/stl/07_psu_service_tray_snap_tray_PRINT_1.stl
118.8 x 13.8 x 79.0

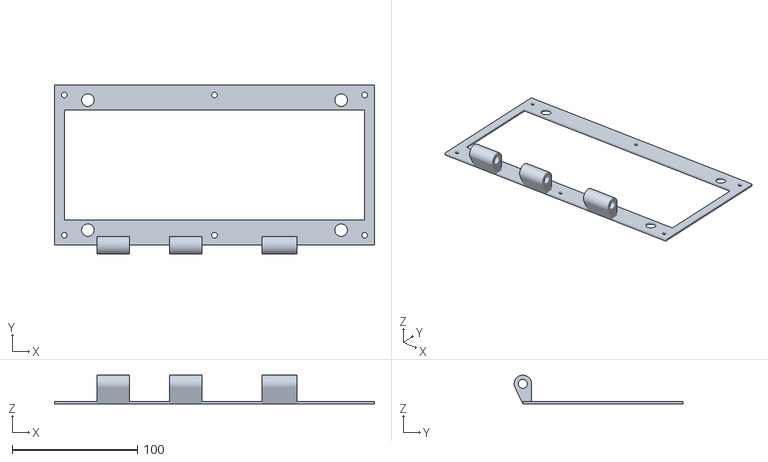
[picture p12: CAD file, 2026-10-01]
hardware/enclosure/stl/01_panel_hinge_template_PRINT_1.stl
256.0 x 135.0 x 23.0

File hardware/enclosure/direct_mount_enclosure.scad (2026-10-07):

// Canonical modular hinged direct-mount enclosure for four 256 x 128 mm P4 HUB75 panels.
//
// Issue #133 commits the project to the hinged architecture. This is the single
// parametric source of truth for the PR #119-style MOVING panel/template leaf,
// STATIONARY universal equipment base, top-down removable backplane and
// detachable side retainers.
//
// The physically corrected P4 panel coordinates remain the source of truth.
// Component-specific PSU/MatrixPortal geometry belongs on detachable adapters.

module_w = 256;
module_h = 128;
backplane_edge_inset = 0.5;
backplane_w = module_w - 2*backplane_edge_inset;
backplane_h = module_h - 2*backplane_edge_inset;

panel_mount_x = [7.9, 128.0, 248.1];
panel_mount_y = [7.9, 120.1];
panel_mount_hole_d = 4.5;

panel_locator_x = [26.704, 229.296];
panel_locator_y = [12.0, 116.0];
panel_locator_clearance_d = 10.0;

$fn = 48;

// ---------- Proven PR #119 hinge geometry ----------
//
// The equipment enclosure/base is STATIONARY. The LED panel + mounting
// template is the MOVING leaf and opens forward/down. These roles, dimensions
// and support strategy intentionally follow the validated PR #119 hinge.

hinge_rail_d = 6;
hinge_bore_d = 7.2;
hinge_outer_d = 14;
hinge_radius = hinge_outer_d/2;
hinge_axial_clearance = 1.0;

// Physical rail/side-support contract. The detachable outer end pieces retain
// the 6 mm rod axially, then continue inward as hollow sleeves around the rod
// until they meet the nearest hinge barrel. The sleeve uses the same outer
// diameter as the hinge barrels and the same 7.2 mm running bore, so the rod is
// supported without becoming bonded to the side piece.
hinge_rail_start_x = 10;
hinge_rail_length = 236;
hinge_rail_end_x = hinge_rail_start_x + hinge_rail_length;
side_rod_sleeve_outer_d = hinge_outer_d;
side_rod_sleeve_bore_d = hinge_bore_d;

// Raise the complete installed moving leaf/hinge 20 mm above the previous
// 20 mm baseline. The print wrapper subtracts this installation offset, so the
// moving panel/template STL itself remains unchanged.
baseline_ground_clearance = 20;
hinge_install_lift = 20;
ground_clearance = baseline_ground_clearance + hinge_install_lift;
hinge_axis_y = ground_clearance; // hinge centreline matches the moving panel's lower edge

moving_plate_t = 2;
fixed_template_t = moving_plate_t; // compatibility alias used by modular equipment geometry
hinge_plate_clearance = 7;
hinge_axis_z = moving_plate_t + hinge_radius + hinge_plate_clearance; // 16 mm

// Core stationary guard envelope is needed by both the base hinge structure and
// the detachable side cheeks. Keep these values next to the hinge axis so side
// geometry never depends on a later forward reference.
hinge_guard_t = 2;
hinge_guard_clearance = 0.8;
hinge_guard_front_z = hinge_axis_z + hinge_radius + hinge_guard_clearance;
hinge_guard_top_y = hinge_axis_y;

// Full 0-90 degree service arc is part of the proven hinge contract.
service_open_angle = 90;
mechanical_clearance_angle = 90;

// Moving LED/template knuckles from the validated PR #119 geometry.
panel_knuckles = [
    [34,26],
    [92,26],
    [166,28]
];

// Stationary equipment-side knuckles alternate with the moving panel knuckles.
stationary_knuckles = [
    [62,28],
    [136,28],
    [196,24]
];

hinge_left_barrel_start = min(
    min([for (segment=panel_knuckles) segment[0]]),
    min([for (segment=stationary_knuckles) segment[0]])
);
hinge_right_barrel_end = max(
    max([for (segment=panel_knuckles) segment[0]+segment[1]]),
    max([for (segment=stationary_knuckles) segment[0]+segment[1]])
);

module rail_hinge_barrel(x0, len, axis_z=hinge_axis_z) {
    translate([x0,hinge_axis_y,axis_z])
        rotate([0,90,0])
            difference() {
                cylinder(d=hinge_outer_d,h=len);
                translate([0,0,-0.2])
                    cylinder(d=hinge_bore_d,h=len+0.4);
            }
}

// ---------- Moving half: LED panel mounting template ----------

panel_band_h = 20;
panel_side_w = 8;


module panel_mount_pattern_template() {
    difference() {
        union() {
            cube([module_w,panel_band_h,moving_plate_t]);
            translate([0,module_h-panel_band_h,0])
                cube([module_w,panel_band_h,moving_plate_t]);
            cube([panel_side_w,module_h,moving_plate_t]);
            translate([module_w-panel_side_w,0,0])
                cube([panel_side_w,module_h,moving_plate_t]);
        }

        for (x=panel_mount_x)
            for (y=panel_mount_y)
                translate([x,y,-0.5])
                    cylinder(d=panel_mount_hole_d,h=moving_plate_t+1);

        for (x=panel_locator_x)
            for (y=panel_locator_y)
                translate([x,y,-0.5])
                    cylinder(d=panel_locator_clearance_d,h=moving_plate_t+1);
    }
}

module moving_panel_root(x0,len) {
    // PR #119: local reinforcement only. The moving leaf deliberately has no
    // full-width lower hinge lip that could collide with the stationary base.
    hull() {
        translate([x0,ground_clearance,0])
            cube([len,7,moving_plate_t]);

        translate([x0,hinge_axis_y,hinge_axis_z])
            rotate([0,90,0])
                cylinder(d=hinge_outer_d,h=len);
    }
}

module moving_panel_template_installed() {
    difference() {
        union() {
            translate([0,ground_clearance,0])
                panel_mount_pattern_template();

            for (segment=panel_knuckles)
                moving_panel_root(segment[0],segment[1]);
        }

        // One continuous rod bore guarantees all moving knuckles are coaxial.
        translate([-0.2,hinge_axis_y,hinge_axis_z])
            rotate([0,90,0])
                cylinder(d=hinge_bore_d,h=module_w+0.4);
    }
}

module moving_panel_template_print() {
    // Keep the verified panel/template face flat on the print bed.
    translate([0,-ground_clearance,0])
        moving_panel_template_installed();
}

// Compatibility name used by older previews/tests. This is the installed
// moving panel-side leaf, not a fixed equipment-side template.
module hinge_mount_pattern_template() {
    moving_panel_template_installed();
}

// ---------- Shared moving-envelope coordinates ----------

service_x = backplane_edge_inset;
service_base_y = backplane_edge_inset;
service_top_y = backplane_edge_inset + backplane_h;
service_w = backplane_w;

service_close_clearance = 0.6;
service_front_z = fixed_template_t + service_close_clearance;

// Revised upper enclosure profile and top closure fastening.
// Keep the 40 mm-deep equipment section taller, use a shorter/steeper ramp,
// then finish with a shallow wall parallel to the LED panel all the way to the
// full panel height. The three existing TOP-row panel screw locations are
// reused as removable closure fasteners between the moving panel/template and
// stationary enclosure.
enclosure_panel_clearance = 0.8;
enclosure_front_z = fixed_template_t + enclosure_panel_clearance; // 2.8 mm
enclosure_bottom_depth = 40;

// Single source of truth: closure holes directly reuse the measured panel
// mounting coordinates and diameter. Installed Y includes ground clearance.
panel_closure_x = panel_mount_x;
panel_closure_y = ground_clearance + panel_mount_y[1];
panel_closure_hole_d = panel_mount_hole_d;

backplane_ramp_start_y = 75;
backplane_ramp_end_y = 120;
enclosure_top_y = ground_clearance + module_h;
upper_vertical_h = enclosure_top_y - backplane_ramp_end_y;

equipment_backplane_t = 3;
equipment_backplane_lower_rear_z = enclosure_front_z + enclosure_bottom_depth;
equipment_backplane_front_z = equipment_backplane_lower_rear_z - equipment_backplane_t;
equipment_backplane_rear_z = equipment_backplane_lower_rear_z;
// At the top, the backplane itself now runs close and parallel to the moving
// template instead of sitting ~8 mm behind it. Its front face is only the
// intended 0.8 mm service clearance behind the template rear face.
equipment_backplane_top_front_z = enclosure_front_z;
equipment_backplane_top_rear_z =
    equipment_backplane_top_front_z + equipment_backplane_t;

// Physical PETG fit: give the removable tongue a little more running room in
// the rear seat so it does not bow while being pushed home.
backplane_guide_clearance = 0.6;
backplane_guide_t = 1.2;
backplane_seat_depth = 2.0;
base_seat_y = 4.5;
equipment_backplane_y0 = base_seat_y - backplane_seat_depth;
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

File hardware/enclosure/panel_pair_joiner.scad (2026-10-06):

// Removable seam joiner for the four-panel enclosure.
//
// Each joiner spans one adjacent pair of 256 mm LED/enclosure modules and
// reuses the existing top-row panel/enclosure closure screws nearest the seam.
// No new holes are introduced in either the LED panel or enclosure.

hinge_part = undef;
include <direct_mount_enclosure.scad>;

panel_pair_joiner_t = 3.0;
panel_pair_joiner_outer_d = 13.0;
panel_pair_joiner_hole_d = panel_mount_hole_d;
panel_pair_joiner_print_gap = 8.0;

panel_pair_joiner_left_edge_offset =
    module_w - panel_mount_x[len(panel_mount_x)-1];
panel_pair_joiner_right_edge_offset = panel_mount_x[0];
panel_pair_joiner_hole_spacing =
    panel_pair_joiner_left_edge_offset + panel_pair_joiner_right_edge_offset;
panel_pair_joiner_length =
    panel_pair_joiner_hole_spacing + panel_pair_joiner_outer_d;

assert(
    abs(panel_pair_joiner_hole_spacing-15.8) < 0.01,
    "panel-pair joiner must track the measured 15.8 mm seam hole spacing"
);
assert(
    abs(panel_pair_joiner_hole_d-4.5) < 0.01,
    "panel-pair joiner must reuse the 4.5 mm closure-hole clearance"
);

module panel_pair_joiner() {
    r = panel_pair_joiner_outer_d/2;
    left_x = r;
    right_x = r + panel_pair_joiner_hole_spacing;
    yc = r;

    difference() {
        hull() {
            translate([left_x,yc,0])
                cylinder(d=panel_pair_joiner_outer_d,h=panel_pair_joiner_t,$fn=32);
            translate([right_x,yc,0])
                cylinder(d=panel_pair_joiner_outer_d,h=panel_pair_joiner_t,$fn=32);
        }

        for (xx=[left_x,right_x])
            translate([xx,yc,-0.2])
                cylinder(d=panel_pair_joiner_hole_d,h=panel_pair_joiner_t+0.4,$fn=24);
    }
}

module panel_pair_joiners_print(count=3) {
    assert(count >= 1);

    for (i=[0:count-1])
        translate([
            i*(panel_pair_joiner_length+panel_pair_joiner_print_gap),
            0,
            0
        ])
            panel_pair_joiner();
}

module panel_pair_joiner_installed(seam_x) {
    // Place the joiner on the accessible rear face of the shallow top wall.
    // Its two holes land exactly on the right-most closure hole of the module
    // to the left and the left-most closure hole of the module to the right.
    translate([
        seam_x-panel_pair_joiner_left_edge_offset-panel_pair_joiner_outer_d/2,
        panel_closure_y-panel_pair_joiner_outer_d/2,
        equipment_backplane_top_rear_z
    ])
        panel_pair_joiner();
}

module all_panel_pair_joiners_installed() {
    for (seam=[1:3])
        panel_pair_joiner_installed(seam*module_w);
}

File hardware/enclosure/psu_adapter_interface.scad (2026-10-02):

// Geometry-free shared mounting-grid contract for the enclosure and PSU dock.
// Values here are local offsets/column selections; absolute Y is derived from
// the measured usable enclosure cavity in direct_mount_enclosure.scad.
psu_adapter_mount_row_offsets = [-19, 0, 19];
psu_adapter_selected_columns = [80, 176];
psu_adapter_all_columns = [32, 80, 128, 176, 224];

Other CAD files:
hardware/enclosure/stl/04_left_equipment_side_PRINT_1.stl
hardware/enclosure/direct-mount/00_complete_enclosure_ASSEMBLY.scad
hardware/enclosure/direct-mount/parts/01_backplane_module_PRINT_3.scad
hardware/enclosure/direct-mount/parts/02_module_joiner_PRINT_4.scad
hardware/enclosure/direct-mount/parts/03_rod_end_plug_PRINT_4.scad
hardware/enclosure/direct-mount/parts/04_matrixportal_mount_PRINT_1.scad
hardware/enclosure/direct-mount/parts/06_cable_clip_PRINT_8.scad
hardware/enclosure/direct-mount/parts/07_mounting_slot_coupon_PRINT_1.scad
hardware/enclosure/direct-mount/parts/08_mount_pattern_template_PRINT_1.scad
hardware/enclosure/matrixportal/matrixportal_s3_mount.scad
hardware/enclosure/parts/01_panel_hinge_template_PRINT_1.scad
hardware/enclosure/parts/02_hinged_equipment_base_PRINT_1.scad
hardware/enclosure/parts/03_universal_equipment_backplane_PRINT_1.scad
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

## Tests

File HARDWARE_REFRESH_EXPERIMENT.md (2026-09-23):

# MatrixPortal refresh experiment — issue #70

> **Historical experiment record.** For the current consolidated conclusions and
> design rules from #70, #91, #92 and #94, see
> [`docs/matrixportal-performance.md`](docs/matrixportal-performance.md).

This branch is intended to be copied directly to the physical MatrixPortal S3.

## Current decision

Mode A is retired as a production candidate. Its targeted refresh deadline
discarded a large proportion of changed frames in the physical runs. Further
testing is limited to Mode B (immediate refresh with application pacing) and
Mode C (CircuitPython auto-refresh).

B8 remains the production baseline because it combines the strongest tested
manual-refresh reliability with the lower 8-update/s cadence.

The merged source retains a focused post-#72 **B12** experiment. B12 keeps Mode B's
immediate refresh strategy but raises the application animation cadence to
12 updates/s while deliberately keeping the Todoist marquee speed at 8 px/s.
This isolates update smoothness from text travel speed.

The retained Todoist scene is identical across the primary test modes. Only the presentation strategy and animation cadence change.

## What the local board agent needs to do

For each run:

1. Edit **one line** in `firmware/matrix_config.py`:

   ```python
   MATRIX_EXPERIMENT_PRESET = "A7"
   ```

2. Upload/synchronise this branch with `bash scripts/install-firmware.sh /Volumes/CIRCUITPY`.
3. Allow the board to boot, fetch the live payload, and enter the Todoist screen.
4. Observe at least 30 seconds and preferably multiple complete six-task page cycles.
5. Capture the serial lines beginning with:
   - `MATRIX PRESENTATION`
   - `MATRIX STATS`
   - `FRAME PACE`
   - `FETCH START` / `FETCH OK`
   - any `DISPLAY REFRESH DEADLINE MISSED`
6. Record direct visual observations:
   - horizontal flashing
   - tearing / partial rows
   - title-scroll smoothness
   - skipped-pixel jumps
   - page-slide smoothness
   - readability
7. Reboot/reset the board between presets so counters start cleanly.
8. Post the results table to issue #70.

## Presets

The historical comparison presets remain available, plus the focused B12 follow-up:

| Preset | Presentation mode | Animation / target FPS | Todoist marquee |
| --- | --- | ---: | ---: |
| A7 | current `refresh(target_frames_per_second=N)` | 7 | 7 px/s |
| A8 | current `refresh(target_frames_per_second=N)` | 8 | 8 px/s |
| A10 | current `refresh(target_frames_per_second=N)` | 10 | 10 px/s |
| B7 | immediate `refresh(None)` + app pacing | 7 | 7 px/s |
| B8 | immediate `refresh(None)` + app pacing | 8 | 8 px/s |
| B10 | immediate `refresh(None)` + app pacing | 10 | 10 px/s |
| **B12** | immediate `refresh(None)` + app pacing | **12** | **8 px/s** |
| C7 | CircuitPython `auto_refresh=True` | 7 update ticks/s | 7 px/s |
| C8 | CircuitPython `auto_refresh=True` | 8 update ticks/s | 8 px/s |
| C10 | CircuitPython `auto_refresh=True` | 10 update ticks/s | 10 px/s |

The A7/A8/A10 presets remain in the code only as historical controls and are
not part of the remaining test plan.

For B and C presets, the number is the **application animation-update cadence**.
It is not the physical HUB75 scan rate.

B12 intentionally breaks the older "FPS equals marquee speed" pattern: it is
**12 animation updates/s with an 8 px/s Todoist marquee**. This lets the hardware
test answer whether more frequent coordinate updates improve smoothness without
making the text move faster.

For C presets, CircuitPython owns framebuffer refresh timing.

## What each mode does

### A — current control

- `FramebufferDisplay(auto_refresh=False)`
- changed scenes call `refresh(target_frames_per_second=N)`
- current relative outer sleep is retained
- late refresh calls may return `False`

### B — immediate manual refresh

- `FramebufferDisplay(auto_refresh=False)`
- changed scenes call `refresh(target_frames_per_second=None)`
- application uses an absolute animation deadline
- a long fetch/transition rebases instead of spinning through stale animation ticks

### C — CircuitPython auto-refresh

- `FramebufferDisplay(auto_refresh=True)`
- normal animation does **not** call `refresh()`
- application only mutates persistent group coordinates/state
- CircuitPython controls framebuffer presentation

## Serial metrics

Example startup:

```text
MATRIX PRESENTATION preset=B8 mode=immediate target_fps=8 marquee_px_s=8.0 auto_refresh=False
```

Manual modes periodically emit:

```text
MATRIX STATS mode=immediate target_fps=8 elapsed=... changes=... refresh_attempts=... refresh_successes=... refresh_failures=... presented_fps=... interval_min=... interval_max=... interval_avg=... heap_start=... heap_end=...
```

All Todoist runs periodically emit:

```text
FRAME PACE mode=immediate target_fps=8 elapsed=... animation_ticks=... tick_fps=... late_frames=... max_late_streak=...
```

In auto-refresh mode, `refresh_attempts`, `refresh_successes`, and `presented_fps` are intentionally not treated as observable physical-refresh metrics. Use `FRAME PACE`, heap data, and direct visual observation.

## Suggested result table

| Preset | Visual flashing | Tearing | Marquee | Page slide | Refresh failures | Late frames | Max late streak | Heap drift | Notes |
| --- | --- | --- | --- | --- | ---: | ---: | ---: | --- | --- |
| A7 | | | | | | | | | |
| A8 | | | | | | | | | |
| A10 | | | | | | | | | |
| B7 | | | | | | | | | |
| B8 | | | | | | | | | |
| B10 | | | | | | | | | |
| **B12 (12 updates/s, 8 px/s)** | | | | | | | | | |
| C7 | | | | | n/a | | | | |
| C8 | | | | | n/a | | | | |
| C10 | | | | | n/a | | | | |

### Current serial evidence

| Preset | Window | Refresh result | Application pacing | Network / reset |
| --- | ---: | --- | --- | --- |
| B8 | 60.9 s | 409/409 successful, 0 failures | 7.43 ticks/s; 4 late, max streak 3 | fetches succeeded; no reset observed |
| C8 | 20.1 s | n/a; auto-refresh owns presentation | 7.61 ticks/s; 10 late, max streak 2 | fetch succeeded; reload occurred after capture |
| B10 | 102.4 s | 706/706 successful, 0 failures | 10.44 ticks/s; 5 late, max streak 2 | fetches succeeded; no reset observed |
| C10 | 20.1 s | n/a; auto-refresh owns presentation | 10.06 ticks/s; 116 late, max streak 4 | fetch succeeded; reload occurred after capture |

These serial results do not establish flashing, tearing, or visual smoothness.

## Focused B12 check

Use this branch only after the #72 layout/timing changes have been loaded on the
physical board.

Compare B12 directly against the B8 production baseline using the same payload.
Do not change marquee speed between those two runs.

Record:

- horizontal flashing / tearing;
- Todoist marquee smoothness;
- Todoist page-slide smoothness;
- departures calling-at smoothness;
- visible pixel-step/jump behaviour;
- achieved animation tick rate;
- late frames and maximum late streak;
- refresh attempts/successes/failures;
- one live fetch during movement;
- DOWN/UP responsiveness.

If B12 is not visibly smoother than B8, or produces materially more lateness,
keep B8. Do not increase cadence further merely because the board can execute
more ticks.

If B12 is clearly smoother and remains stable, record that evidence on #70
before changing the production preset.

### B12 serial result

The connected-board run after PR #73 booted, fetched the live two-screen
payload, and completed all measured immediate refreshes successfully. At the
12-update/s cadence it reached 11.31 animation ticks/s in the first 20.1 s,
with 12 late frames and a maximum late streak of 3. The 40.2 s summary still
showed 135/135 successful refreshes and no refresh failures. No direct visual
observation was available, so B8 remains the production profile.

## Stress check for the best candidate

After the nine short comparisons, run the best candidate for several minutes and verify:

- six Todoist tasks / page transition
- several long titles
- live network fetch during movement
- DOWN manual screen change
- UP diagnostic mode and return
- no reset/reconnect failure
- no progressive heap loss
- root group remains stable during normal Todoist animation

Do not change `MATRIX_BIT_DEPTH` during this experiment.

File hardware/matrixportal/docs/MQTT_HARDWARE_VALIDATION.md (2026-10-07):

# Issue #74 hardware validation gate

This is the test procedure for the MatrixPortal MQTT path. Both local feature
flags now default to enabled, while broker configuration remains board-local.
The listener waits 30 seconds after display/client initialization before its
first connection attempt. The currently deployed Home Assistant contract
supersedes the original due-only proposal in issue #74: Home Assistant publishes a retained
QoS 1 snapshot of the nearest future reminder every minute, and the board uses
its synchronized clock to flash once when that reminder becomes due.

## Preconditions

- Home Assistant's minute scheduler is loaded and publishes
  `event: "scheduled"` snapshots to `led/flash/reminder` with QoS 1 and
  `retain: true`; an empty schedule publishes an explicit `event: "clear"`.
- The board polls MQTT every 60 seconds, caches the latest valid occurrence,
  and checks `due_at` against its synchronized internal clock between polls.
- A stable broker hostname and uncommitted board credentials are available.
- `adafruit_minimqtt` has been installed into `CIRCUITPY/lib`.
- The board is running the current B8 production refresh profile.
- Record a disabled-MQTT baseline first; do not compare against memory or a
  different payload.

## Capture for each run

Use the existing serial diagnostics for a minimum of 60 seconds of Todoist
and departures activity. Record:

- `MATRIX PRESENTATION` profile and target cadence;
- `MATRIX STATS` refresh attempts, successes, failures and heap values;
- `FRAME PACE` tick rate, late frames and maximum late streak;
- fetch success/failure and reconnect messages;
- visible flashing, tearing, marquee jumps and page-slide behaviour.

Run the same payload in two states:

1. MQTT disabled (B8 baseline).
2. MQTT enabled but idle, with no published messages.

The idle run must retain bounded socket servicing and show no material change
in refresh failures, late-frame streaks, heap drift or visible rendering.

## Event checks

With the idle run stable, publish several test events and verify:

- the flash starts without waiting for the HTTP poll;
- the configured runtime duration is honoured;
- the underlying screen resumes at its prior phase;
- a duplicate ID is ignored;
- an expired event is ignored;
- a newer event replaces an active flash and restarts its duration;
- broker disconnect leaves HTTP screen rotation operating;
- reconnect restores the subscription.

For the Home Assistant end-to-end check, create a reminder a few minutes in
the future. Confirm the retained MQTT snapshot is refreshed each minute before
the due time, the board does not flash early, and the board flashes exactly
once at the due time despite repeated snapshots. Confirm that edits replace
the pending occurrence and recurring occurrences receive distinct IDs. Also
verify a cleared schedule cancels the pending flash.

Do not close #74 until these observations are recorded against the actual
MatrixPortal and the Home Assistant publisher.

## Captured baseline

On 2026-09-21, the physically connected MatrixPortal S3 was synchronized with
the production bundle and measured with MQTT disabled (`MQTT_ENABLED = False`,
`MQTT_ENABLE_EXPERIMENTAL = False`) using the `B8` profile:

- presentation mode: `immediate`
- target animation rate: 8 FPS
- frame-pacing samples: 7.73 FPS at 40.2 seconds, 7.07 FPS at 82.7 seconds
- late frames: 6 and 9 respectively; maximum late streak: 1 and 2
- HUB75 refresh failures: 0 in each observed matrix statistics sample
- departures and calendar rendered, with successful HTTP refreshes during the capture
- observed render times: 1.070 seconds for departures and 0.526 seconds for calendar

The following captures are historical. Current firmware enables the MQTT
listener after its startup delay when the board-local broker is configured and
the runtime Flash setting is enabled.

## Fresh synchronized baseline

On 2026-09-21, after synchronizing the attached MatrixPortal with the merged
`master` runtime bundle, a 70-second disabled-MQTT capture was recorded with
both local MQTT gates false:

- target animation rate: 8 FPS;
- frame-pacing samples: 7.67 FPS at 60.2 seconds, 7.75 FPS at 80.2 seconds,
  7.78 FPS at 100.3 seconds and 7.79 FPS at 120.4 seconds;
- late frames: 10, 10, 13 and 15 respectively; maximum late streak: 2;
- HUB75 refresh failures: 0 in every sample;
- normal HTTP refreshes succeeded (`FETCH OK screens=2`);
- no MQTT connection or flash-event output appeared.

Use this synchronized capture as a historical disabled-MQTT reference. A
controlled but incomplete same-session comparison is recorded below.

## Manual due-event smoke test

With MQTT enabled only in the board's uncommitted `settings_local.py`, run from
the repository root:

```bash
./.venv/bin/python scripts/publish_mqtt_test_event.py --label "Manual MQTT test"
```

The publisher reads the private board settings without printing credentials,
connects to the configured broker, and publishes a unique `event: "due"`
message to `led/flash/reminder` with QoS 1 and `retain: false`. A successful
run reports PUBACK. On the physical board, confirm `FLASH START`, the supplied
label, the configured flash duration, `FLASH END`, and normal-screen recovery.
This is a board transport smoke test; it does not exercise Home Assistant's
Alexa schedule.

Focused parser/state checks can use explicit IDs and expiry values:

```bash
# Send this command twice; the second event must not start another flash.
./.venv/bin/python scripts/publish_mqtt_test_event.py --event-id duplicate-check

# Both messages must be ignored by the board.
./.venv/bin/python scripts/publish_mqtt_test_event.py --event scheduled --event-id scheduled-check
./.venv/bin/python scripts/publish_mqtt_test_event.py --expires-in-seconds -60 --event-id expired-check
```

For replacement, publish two different IDs and labels less than five seconds
apart. Expect `FLASH START` for A, then `FLASH START` for B before one `FLASH
END`; the underlying rotation should resume after B.

## Controlled MQTT-enabled comparison (2026-09-25)

The same attached MatrixPortal S3, B8 presentation profile and target cadence
were used. MQTT ran over authenticated raw MQTT/TCP to
`windsor-app2.internal.alf1000.uk:1883`; the board credentials remain only in
`CIRCUITPY/settings_local.py`. Adafruit MiniMQTT was present in
`CIRCUITPY/lib`. The local transport used a 10 ms socket timeout and a 2-second
poll interval. The checked-in safe defaults were not changed.

| State | Capture | Presented FPS | Max frame interval | HUB75 refresh failures | Heap at start/end | Todoist marquee ticks | HTTP |
| --- | ---: | ---: | ---: | ---: | ---: | ---: | --- |
| MQTT enabled, idle | 121.8 s | 7.23 | 4.4224 s | 0 | 1,959,296 / 1,747,392 | 1 | fetches succeeded |
| MQTT enabled, idle | 160.6 s | 7.00 | 5.1689 s | 0 | 1,959,264 / 1,623,424 | 234 | fetches succeeded |
| MQTT disabled | 60.4 s | 7.25 | 4.3364 s | 0 | 1,959,328 / 1,813,072 | 0 | fetch succeeded |
| MQTT disabled | 60.4 s | 7.03 | 4.4399 s | 0 | 1,959,248 / 1,804,400 | 0 | fetches succeeded |

Two nearby comparisons differ by 0.02 and 0.03 FPS, with zero HUB75 refresh
failures in every run. The enabled sample at 160.6 seconds also recorded 234
Todoist marquee ticks; its matching disabled run did not contain Todoist
marquee activity. All run lengths differ, so this does not prove a causal
performance gain from increasing the poll interval. It does show no consistent
idle regression from the 2-second poll. Frame intervals over four seconds and
the long scene renders/fetches dominate the worst stalls.

The enabled frame-pacing sample at telemetry elapsed 153.2 seconds recorded
94 late frames, a maximum late streak of 35, six fetches with no failures, and
four over-budget scene renders (average 0.842 seconds, maximum 1.625 seconds).
No equivalent `FRAME PACE` sample was captured in the disabled runs, so their
late-frame counts and streaks remain unverified.

The board subscribed at QoS 1 and stayed connected during the enabled-idle
capture. With MQTT enabled, the following controlled checks were observed:

- valid event: flash started and ended, then normal rendering continued;
- duplicate event ID: one flash start only;
- expired event: ignored;
- replacement A then B: both accepted, with B replacing the active flash;
- broker hostname path: a fresh valid event reached the board and logged both
  `FLASH START` and `FLASH END`;
- 2-second polling: one valid event was observed starting 1.339 seconds after
  the publisher received PUBACK.

CircuitPython prints `Code stopped by auto-reload` when files on the mounted
`CIRCUITPY` drive change. The observed reloads coincided with the deliberate
firmware/configuration writes during these tests. Keep all test settings
changes together and allow the board to finish reloading before measuring.

After this capture, the board was soft-restarted and logged a fresh Wi-Fi
connection, `MQTT subscribed topic=led/flash/reminder`, then a valid event's
`FLASH START` and `FLASH END`. Additional hardware checks confirmed one flash
for two identical IDs, no flash for a scheduled or expired event, and
replacement of event A by event B before the flash ended. After a parser fix,
a payload with fractional-second ISO 8601 timestamps also flashed and ended
normally. These focused runs verify event handling but are not matched
performance samples.

Local safety-gate toggle smoke test on 2026-09-25:

- With both local MQTT gates false for 100 seconds, the board continued to
  fetch and render HTTP screens; the observed matrix samples had zero HUB75
  refresh failures. No MQTT subscription was made. The workload had no active
  Todoist marquee content.
- After restoring both local MQTT gates to true, the board logged a new QoS 1
  subscription. A fresh due event received PUBACK and produced `FLASH START`
  and `FLASH END`; HTTP screen fetches continued during the flash.
- This verifies board-local bootstrap gating and re-subscription after a
  CircuitPython reload. It does not exercise the runtime flash controls from
  `/api/screens`, simulate a broker outage, or provide a matched performance
  comparison. The enabled run later included Todoist marquee activity, so its
  timing is not comparable to the disabled run.

Runtime flash-control hardware smoke test on 2026-09-25:

- Kept both board-local MQTT gates enabled and temporarily served a synthetic
  `/api/screens` response from the LAN with a one-screen test payload.
- With `flash.enabled=false` and `screen_duration_seconds=3`, the board fetched
  the response and stayed subscribed. A valid QoS 1 event received PUBACK but
  produced no `FLASH START` or `FLASH END` during the six-second observation.
- With `flash.enabled=true`, a fresh event produced `FLASH START` and the
  matching end log on the board. After changing
  `screen_duration_seconds` from 3 to 6 in the served response and waiting for
  the next fetch, another fresh event also produced the expected start/end
  transition.
- The serial output was not timestamped closely enough to claim a precise
  measured flash interval; this verifies runtime enable/disable and duration
  updates reached the hardware, while exact visual timing still merits direct
  inspection.
- Restored `SCREEN_API_URL=https://led.alf-broadcast.co.uk`; the board
  reloaded, resubscribed to `led/flash/reminder`, and fetched two public screens
  successfully. The temporary LAN server was stopped.

Broker outage/recovery hardware smoke test on 2026-09-25:

- To avoid interrupting the shared Home Assistant broker, ran a temporary
  authenticated MQTT broker on the laptop and changed only the board-local
  `MQTT_BROKER` host for this test. The normal public screen API remained in
  use.
- The board subscribed to `led/flash/reminder`. Stopping the temporary broker
  produced `MQTT unavailable`; HTTP screen fetches and rendering continued.
- After restarting that broker, the board resubscribed to the topic. A fresh
  QoS 1 test event received PUBACK and produced `FLASH START` followed by
  `FLASH END` on the board.
- Restored `MQTT_BROKER=windsor-app2.internal.alf1000.uk`; after reload the
  board subscribed again and fetched the public API. The temporary broker was
  stopped; the shared Home Assistant broker was never interrupted.

Synthetic Home Assistant due-time to physical-board test on 2026-09-25:

- Started an isolated Home Assistant Core 2026.9.3 instance with the reminder
  package from Home Assistant PR #5 (`41a2063`) and its native MQTT integration
  pointed at a temporary authenticated laptop broker. The physical board was
  temporarily pointed at the same broker; its normal public screen API stayed
  unchanged.
- Set a synthetic reminder helper for a future due time through Home
  Assistant's `input_datetime.set_datetime` service. Home Assistant loaded the
  MQTT config entry, the due-time automation fired with ID
  `issue74-local-ha-e2e-1`, and the automation cleared its active schedule.
- The physical board received the resulting MQTT event and logged
  `FLASH START id=issue74-local-ha-e2e-1` followed by `FLASH END`; it then
  resumed normal rendering. This exercises the actual Home Assistant
  due-time automation, MQTT integration, broker, and physical board, but uses
  a synthetic reminder rather than Alexa Devices data.
- The test does not validate Alexa sensor discovery or real reminder label
  attributes, Home Assistant restart/recovery, or a real recurring Alexa
  reminder. Those acceptance checks remain open.
- Restored the board's `MQTT_BROKER=windsor-app2.internal.alf1000.uk` and
  verified a new subscription plus a successful fetch from the public screen
  API. Stopped the temporary broker; the shared Home Assistant broker was
  never interrupted.

Supplemental idle observations on 2026-09-25 after the parser update:

- MQTT enabled, no reminder traffic: at telemetry elapsed 40 seconds, the
  frame-pacing sample recorded 9.32 tick FPS, 95 late frames, maximum late
  streak 27, 17 successful fetches, and six over-budget scene renders. At
  elapsed 448.8 seconds the matrix summary reported 7.58 presented FPS, a
  5.1504-second maximum interval, zero refresh failures, and heap
  1,959,184/1,609,600 bytes.
- MQTT disabled locally for comparison: after 82.4 seconds the matrix summary
  reported 7.09 presented FPS, a 4.3438-second maximum interval, zero refresh
  failures, and heap 1,959,232/1,807,088 bytes. HTTP fetches succeeded, but
  Todoist marquee ticks remained zero.

These captures are not workload-matched: the enabled run had Todoist marquee
activity, the disabled run did not, and both include different startup/fetch
conditions. They are recorded as supplemental evidence only and do not show a
causal performance difference.

Matched local-fixture comparison on 2026-09-25:

- The board fetched the same two-screen payload from a temporary LAN fixture
  server in both runs. MQTT gates were the only setting changed between runs.
- MQTT disabled: 120.4 seconds, 83 matrix refreshes, 0 refresh failures,
  0.69 presented FPS, 1.4146-second average refresh interval, and 6.1 ms
  average scene update time.
- MQTT enabled and idle: 121.7 seconds, 53 matrix refreshes, 0 refresh
  failures, 0.44 presented FPS, 2.1836-second average refresh interval, and
  4.1 ms average scene update time.
- The animation phase differed between captures, so refresh counts, interval,
  and update-time differences are not attributable to MQTT. The board logs do
  not measure whole-device CPU utilization; this comparison cannot establish
  a CPU saving from changing the two-second MQTT service interval to one
  minute. Both runs continued HTTP fetches without matrix refresh failures.
- The board was restored to `https://led.alf-broadcast.co.uk`, with both
  local MQTT gates enabled. It reloaded, subscribed to
  `led/flash/reminder`, and fetched the public API successfully. The temporary
  LAN fixture server was stopped.

Still outstanding: repeated workload-aligned captures that allow CPU use to
be measured directly, visual inspection for tearing, and the live Home
Assistant #4 Alexa recurrence and restart scenarios. Do not close #74 on these
partial measurements.

## Minute schedule protocol (2026-10-04)

The current implementation supersedes the due-only protocol described in the
historical captures above. HA publishes retained QoS-1 `scheduled` snapshots
every minute and `clear` when no next reminder exists. Firmware polls every
60 seconds with a 180-second keepalive, caches the nearest occurrence, and
checks its due time locally during rendering and static-screen sleeps.
Duplicate IDs do not restart a flash; cancellation clears pending work and
older publication timestamps cannot restore it. IDs are remembered in RAM
across broker reconnects, but not firmware reboots.

Upgrade the board before reloading the HA package. Validate repeated snapshots
without an early flash, a single flash at due time, edit/cancel behavior,
expiry, reconnect, and clock synchronization. Compare identical animated
workloads to determine whether minute polling reduces jumps. A new reminder
or cancellation can take up to 60 seconds to be received; reminders created
just before due time can be late. Only the nearest occurrence is cached.
The synthetic publisher's `scheduled` mode must include `published_at` and a
future `due_at`; it now schedules a flash rather than being rejected.

## Wi-Fi readback and clock correction (2026-10-04)

The board was located through the GLBuddy DHCP lease at `192.168.8.88`
(MAC `68:ee:8f:f7:07:50`), then identified through Web Workflow as
MatrixPortal S3 UID `86EEF87F7005`, CircuitPython 10.3.0. Authenticated Wi-Fi
readback showed `code.py`, `mqtt_client.py`, and `flash_events.py` already
matched checkout `309f31f`. Both local MQTT gates were enabled, the MiniMQTT
library was present, and the production runtime flash duration was 30 seconds.
The board was reloaded to ensure the files on disk were active.

Live testing exposed two clock faults which CPython tests had not caught:

- `/api/screens` payload `fetched_at` is screen-data generation time, sometimes
  approximately a minute behind the current response. The HTTP `Date` header
  was current. Firmware now uses that header for clock synchronization while
  retaining `fetched_at` as the data-age timestamp and as a compatibility
  fallback when the header is absent/invalid.
- Unix epoch arithmetic passed through CircuitPython floating-point values.
  A physical REPL check produced `int(1791150000 + 0.0) == 1791149952`, a
  48-second rounding error. Epoch advancement and expiry comparison now use
  integers. The physical replacement clock returned `1791150000` and
  `1791150001`, both `int`, for adjacent seconds.

Only `flash_events.py`, `screen_client.py`, and `code.py` were uploaded for
these corrections, with `code.py` last and SHA-256 readback verified. Local
settings, credentials, libraries, and the renderer were preserved. The board
then reloaded, subscribed to `led/flash/reminder`, and fetched the normal HTTP
screens successfully.

Deployed file SHA-256 values:

- `flash_events.py`: `fc338dfdd2c8fe936c49e62836dffd19d4d8c26271bd1b586cffc7d80133b4d5`
- `screen_client.py`: `7eac90051bb92e5f779354776feba87ed339bd2704696c0fff042780e8bf0a87`
- `code.py`: `6b6f44bcb3a6954ad5bf82d05f104f6096df50beaf935094ccc8c31f3fbb4c14`
- Unchanged `mqtt_client.py`: `ea11d006cb3ebc3a0f6b05d5dd6aefbe851ae7b2f253aaed3f75874210b38d8f`

The 46 focused clock/reminder/transport/safety tests passed. The complete suite
ran 313 tests with two existing weekly-weather layout problems (one failure,
one error), also present before these clock changes. Unrelated concurrent
renderer edits were preserved and were not uploaded by this deployment.

These source changes implement the user's updated minute-snapshot contract;
the original issue #74 body still describes due-only, non-retained events.
Real Alexa, Home Assistant minute publication, recurrence/restart, matched
performance comparisons, and user-visible tearing remain separate acceptance
gates. Do not close #74 on a synthetic test alone.

Final physical synthetic test after both clock corrections:

- Test occurrence `wifi-validation-53f36573634c` was due at
  `2026-10-04T21:42:47.459441+00:00` (22:42:47 London).
- Non-retained QoS-1 scheduled copies were published at elapsed 0, 60.55, and
  135.46 seconds, each acknowledged by the broker. No event was published at
  the due instant.
- Exactly one `FLASH START` appeared at elapsed 100.71 seconds, 0.71 seconds
  after the intended due time. There was no early flash.
- `FLASH END` appeared at 130.75 seconds: the configured 30-second timer was
  honored. Flash scene construction took 0.854 seconds. The interrupted
  calendar resumed at phase 31.20, then normal rotation reached weekly weather.
- The same ID republished after the flash ended did not fire again during the
  195-second capture. There were zero MQTT disconnect/unavailable messages,
  zero recorded matrix refresh failures, and successful HTTP fetches.
- The latest matrix summary recorded 1,011/1,011 successful refreshes,
  5.47 presented FPS over a 184.7-second mixed workload, maximum interval
  14.8174 seconds, and heap 1,647,616 to 1,641,808 bytes.
- Normal calendar scene construction still took 14.500 seconds; the initial
  Departures construction took 9.094 seconds. These renderer costs remain
  potential interruption sources with minute MQTT polling active. This is not
  a matched two-second-versus-minute A/B performance test, and serial telemetry
  cannot prove the absence of visible jumps or scan-line tearing.

The Home Assistant minute publisher is deployed and tracked in
`antonio1000homens/homeassistant#6`. Its live Alexa sensor resolves to
`2026-10-11T16:00:00Z` (17:00 BST); a timezone conversion defect had stored the
helper as 16:00 BST. The conversion is fixed in the PR and live package, and
the corrected retained snapshot now carries `due_at: 2026-10-11T17:00:00+01:00`
with an ID encoding the same UTC instant. This validates discovery-to-snapshot
time alignment, but real Alexa firing, Home Assistant restart/recovery, and a
matched scrolling performance comparison remain open. Do not close #74 based
on the synthetic board event alone.

## Issue #219 cycle-screen frame-pacing comparison

The #219 firmware adds `led/screens/+` to the existing MQTT connection. On the
MatrixPortal, compare the same normal screen workload in these states:

1. MQTT disabled as the local B8 control.
2. MQTT enabled and idle, subscribed to both topics.
3. MQTT enabled with one retained `bin_collection` snapshot and a long label
   scrolling at the producer's `slide_speed`.

Capture at least 60 seconds per state with `FRAME PACE`, `MATRIX STATS`, HTTP
fetch results, heap values, and MQTT reconnect/subscription messages. Record
label movement and any visible blank interval at the scroll wrap. The long
label intentionally has a short off-panel interval so reconnect handshakes
have a frame-pacing-safe window; verify the MQTT connection can recover there.
Also publish a newer retained upsert, a valid clear, and an expired retained
snapshot; confirm phase continuity, immediate removal, and rejection after
reconnect. Use the same screen workload and record board UID, firmware version,
broker path and capture duration for each run.

This matched #219 hardware comparison has not yet been recorded. The last
known board identity is MatrixPortal S3 UID `86EEF87F7005` at
`192.168.8.88`; verify `/cp/version.json` again before any upload or capture.

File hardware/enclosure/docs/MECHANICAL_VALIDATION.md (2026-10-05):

# Hinged enclosure mechanical validation

The modular hinged design is the only supported direct-mount enclosure.

The canonical hinge motion follows PR #119: the equipment-side enclosure/base
remains stationary and the LED panel/template is the moving leaf.

## Automated gates

Run:

```bash
python hardware/enclosure/scripts/validate_enclosure.py
```

The validator regenerates all five canonical OpenSCAD parts and verifies:

- non-empty positive-volume meshes;
- the installed backplane contains no permanent rear support feet;
- the manufacturing wrapper rotates the backplane so its **256 mm X dimension
  is the print-vertical axis**;
- the shell above the guide section keeps one constant Y/Z profile across X;
- the old under-ramp support forest and transverse front/rear stabilisers remain
  absent;
- the narrowed lower insertion tongue remains clean in the generated STL; its
  elevated first layers are intentionally delegated to the Windsor Slicer
  `petg-supported` tree-auto variant rather than fused CAD support;
- watertight/single-shell geometry after mesh processing;
- bounded printable extents;
- a 2 mm voxel floating-layer/island proxy for support-free parts; the
  backplane is excluded because its tongue support is intentionally
  slicer-generated;
- no volumetric interference between the stationary base and removable backplane;
- positive backplane seating in the recessed rear base groove;
- top-down insertion clearance and 0.6 mm nominal groove clearance;
- dual **40 mm × 5 mm** structural side guides with 0.6 mm running clearance;
- each guide's 16 mm-high lower junction support tied forward into the hinge
  plate/guard at the same height;
- one 26 mm-footprint triangular floor gusset under each guide, full guide width
  and rising to 75% of guide height; the gussets overlap the guide roots while
  staying completely ahead of the insertion slot;
- both 1.2 mm front/rear capture lips extend inward from each 5 mm side guide to
  the outer edge of the nearest X=64 / X=192 mm continuous-rib socket. The
  extension overlaps the original guide by 0.4 mm, remains 40 mm high, preserves
  the original backplane slot, and leaves 0.6 mm clearance before the rib;
- a **10 mm rearward triangular buttress** at each guide root, tapering to the
  native rail rear face at the guide top while leaving the slot unchanged;
- a low full-width stationary **rear shelf** ending on the common rear plane;
  left/right 1.2 mm-thick upright guardrails continue about **58.5 mm** inward
  from each side guide to the nearest outer rib tab, while the centre span
  remains open apart from the existing X = **128 mm** centre tab;
- the shorter lower stepped/narrowed backplane insertion section and full-width shoulder above it;
- three **continuous 24 mm transition ribs** centred at X = **64 / 128 / 192 mm**,
  each running from the reinforced shoulder to **Y=-0.5 mm**, i.e. **1 mm below
  the nominal Y=0.5 mm base reference**, so the correction is entirely on the
  removable backplane and the stationary base remains unchanged. The stationary guardrail occupies an 18 mm tapered channel
  carved into the lower/front portion of the solid rib, preserving 0.6 mm
  tongue clearance, 1.2 mm guardrail thickness and 0.6 mm rear clearance.
  Matching vertical sockets clear the complete rib footprint through the rear
  shelf/base-seat band. The #170 rails/tabs are retained inside those sockets
  and enter lower side/front relief in the ribs. All three rib feet keep that
  relief open from both sides so top-down insertion cannot catch on an asymmetric
  outer-rib wall. Two short low spurs root the centre tab into the surrounding
  shelf across the centre-rib socket without
  closing the full centre span; the existing 24 mm X/print-Z taper prevents
  floating regions;
- hidden guide-tower junctions kept within the bed-connected lower band;
- blind inside accessory bosses with a solid external rear skin;
- exactly three slimmer accessory-boss rows (7 mm OD × 4 mm high), with the outer rows 22 mm in from the full-depth-region edges and the third row centred;
- the 2 mm seat depth and rear-edge groove location;
- a 54 mm clear-depth universal equipment zone preserving the smaller lower
  guide/insertion section only where the U-channel capture requires it;
- full-width rear-shell coverage immediately above the guide section with no
  X-dependent edge-depth transition;
- a **92 mm structural full-depth rear-wall region**, of which the lower **8 mm**
  is the reinforced shoulder, leaving **84 mm usable full-depth height above the
  shoulder** for the 80 mm PSU plus 4 mm clearance, followed by a restored **12 mm** return ramp;
- three rows of seven **24 mm × 1 mm rounded vent slots** on the reinforced lower
  transition shoulder, with 1.25 mm solid lands, and four rows of seven matching
  slots across the restored **12 mm upper return ramp**, with at least 1.5 mm
  solid material between rows;
- the full-depth M3 boss wall remains solid apart from its blind mounting holes;
- a final **23.5 mm** flat upper wall parallel to the lifted LED panel; the raised
  enclosure supplies the extra ramp height without reducing the PSU envelope,
  and the three aligned 4.5 mm top-row closure holes retain at least 1 mm of
  material from the ramp bend;
- at least 15 mm of vertical release travel through the shortened upper alignment connector;
- no rear cable/ribbon through-slots;
- side-piece fit, hinge-rod clearance, and capped hollow left/right rod sleeves;
- moving/front-panel hinge-root geometry remains unchanged from the existing
  validated template;
- a **20 mm forward extension** of the stationary base floor, retained as a
  flat floor with no shallow front ramp;
- no volumetric intersection between the stationary base and the unchanged
  moving panel throughout the full hinge sweep;
- an unobstructed lower equipment volume ahead of the rear groove;
- the stationary enclosure and 6 mm rail against the moving panel/template at
  **0, 15, 30, 45, 60, 75 and 90°**;
- neighboring module cores at the 256 mm pitch, with side retainers only at
  the outside edges;
- successful open and closed assembly-preview rendering.

The hinge regression contract includes:

- **14 mm** barrel OD;
- **7.2 mm** printed bore for the 6 mm rail;
- installed moving-panel lower edge and hinge axis at **y=40 mm, z=16 mm**,
  representing a **20 mm lift** from the previous 20 mm baseline;
- stationary base floor extended **20 mm toward the front** while remaining
  clear of the full 0–90° moving-panel sweep;
- **7 mm** closed template-to-barrel clearance;
- local roots on the moving template retained at their existing validated
  geometry; no front-panel/template reprint is introduced by this change;
- rearward support webs that terminate at the reinforced hinge shelf;
- 3 mm local pads at the stationary hinge roots;
- **2 mm** stationary lower guard with **0.8 mm** barrel clearance;
- **6 mm rail from X=10 to X=246 mm**;
- side-piece rod supports matching the **14 mm hinge-barrel OD** with a
  **7.2 mm clearance bore** around the rod span;
- capped outer sections retaining the rail at X=10/246, with hollow sleeves
  continuing from those endpoints to the first barrel at X=34 and final barrel
  end at X=220.

The previous full-width captive tongue/channel is retired. The backplane enters
a 2 mm-deep **recessed groove at the rear of the base**. The shorter lower U-channel
insertion section remains narrower and shallower, but immediately above the
guide tops the backplane uses one full-width **54 mm** profile across the entire
256 mm X length. The full-depth rear wall is **92 mm high** overall; its reinforced
8 mm lower shoulder leaves **84 mm of usable full-depth height above it**, restoring
80 mm PSU fit plus 4 mm clearance. The raised enclosure then provides a restored
**12 mm return ramp** carrying four upper ventilation rows before reaching the
**23.5 mm flat upper wall** at the lifted **168 mm** enclosure/panel height.
The full-depth rear mounting wall remains solid.
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

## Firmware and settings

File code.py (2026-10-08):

"""MatrixPortal / Wokwi information-board entrypoint."""

import sys
import time

# Wokwi requires code.py at the project root, while implementation modules are
# grouped by responsibility in the repository. Physical-board staging flattens
# these directories back onto CIRCUITPY, where the extra paths are harmless.
for source_path in ("/hardware/matrixportal/firmware", "/shared", "hardware/matrixportal/firmware", "shared"):
    if source_path not in sys.path:
        sys.path.append(source_path)

try:
    import gc
except ImportError:
    gc = None

import settings

try:
    import settings_local as local
except ImportError:
    local = None

if local:
    for name in dir(local):
        if not name.startswith("_"):
            setattr(settings, name, getattr(local, name))

from wifi_startup import start_wifi

start_wifi(settings)

from queue_display import create
from fixtures import animated_services
from flash_events import FlashState
from animation_scheduler import earliest_wake_seconds, next_deadline, screen_fetch_decision
from matrix_runtime import RuntimeMode
from screen_client import ClockState, ScreenClient, ScreenRotation
from mqtt_screens import MqttScreenState
from matrix_config import (
    MATRIX_PRESENTATION_MODE,
    MATRIX_REFRESH_FPS,
    MATRIX_STATS_INTERVAL_SECONDS,
)


if settings.SCREEN_SOURCE not in ("fixture", "api"):
    raise ValueError("SCREEN_SOURCE must be fixture or api")

# The four-panel MatrixPortal installation is operated in static mode.  A
# local settings file may select the backend and network, but cannot re-enable
# the high-frequency animation path that produced scan-line flashes.
if settings.DISPLAY_BACKEND == "matrix":
    settings.ANIMATE = False


def fixture_payload(now):
    services = animated_services(now, settings.ANIMATION_SECONDS)
    weather = {
        "source": "fixture",
        "stale": False,
        "temperature_c": 17,
        "weather_code": 2,
        "icon": "partly_cloudy_day",
        "is_day": True,
    }
    return {
        "fetched_at": "2026-09-12T12:00:00Z",
        "screens": [
            {
                "id": "steam-train",
                "kind": "steam_train_intro",
                "duration_seconds": 16,
                "title": "Steam train",
                "source": "fixture",
                "stale": False,
                "animation_speed": 24,
                "words": "choo choo",
            },
            {
                "id": "departures",
                "kind": "rail_combined",
                "duration_seconds": 8,
                "title": "{} departures".format(settings.STATION_CRS),
                "source": "fixture",
                "stale": False,
                "services": services[:3],
                "weather": weather,
            }
        ],
    }


def hardware_safe_screen(screen):
    """Keep hardware-safe screen text without collapsing combined park titles."""
    return screen


display = create(settings)
rotation = ScreenRotation()
clock = ClockState()
client = ScreenClient(settings) if settings.SCREEN_SOURCE == "api" else None
buttons = None
if settings.DISPLAY_BACKEND == "matrix":
    from button_control import MatrixButtons

    buttons = MatrixButtons()

_pending_button_events = []
_BUTTON_POLL_SECONDS = 0.05
_MQTT_SLEEP_POLL_SECONDS = 0.25
_ANIMATION_FETCH_RETRY_SECONDS = 0.5
_ANIMATION_FETCH_GUARD_SECONDS = 3.0
mqtt_screens_changed = False


def _sleep_interruptible(seconds, service_mqtt=False):
    """Sleep without changing render cadence, servicing requested I/O while idle."""
    global mqtt_screens_changed
    seconds = max(0.0, float(seconds or 0))
    if buttons is None and not service_mqtt:
        time.sleep(seconds)
        return
    deadline = time.monotonic() + seconds
    next_mqtt_poll = time.monotonic()
    while True:
        remaining = deadline - time.monotonic()
        if remaining <= 0:
            return
        time.sleep(min(_BUTTON_POLL_SECONDS, remaining))
        now = time.monotonic()
        epoch_now = _reminder_epoch(now)
        if epoch_now is not None and mqtt_screens.expire(epoch_now):
            rotation.update_sources(rotation.http_screens, mqtt_screens.screens(epoch_now), now)
            mqtt_screens_changed = True
            return
        if service_mqtt and _service_reminder_clock(now):
            return
        if service_mqtt and mqtt is not None and now >= next_mqtt_poll:
            mqtt.poll(now)
            next_mqtt_poll = now + _MQTT_SLEEP_POLL_SECONDS
            if mqtt_screens_changed:
                return
            if flash.active(now):
                return
        if buttons is not None:
            events = buttons.poll(now)
            if events:
                _pending_button_events.extend(events)
                return


next_fetch = 0
transport_stale = False
fixture_clock_synced = False
runtime_mode = RuntimeMode()
flash = FlashState(
    # Reminder events stay gated until the screen payload enables Flash in
    # the admin control plane. Cycle screens use the independent MQTT source.
    enabled=False,
)
flash_resume = None
mqtt = None
mqtt_screens = MqttScreenState(
    getattr(settings, "MQTT_SCREENS_TOPIC", "led/screens/+")
)


def _reminder_epoch(now):
    epoch_now = clock.epoch(now)
    if epoch_now is None:
        system_epoch = time.time()
        epoch_now = system_epoch if system_epoch >= 1000000000 else None
    return epoch_now


def _flash_started(now):
    global flash_resume, last_render_key
    if flash_resume is None:
        flash_resume = rotation.freeze(now)
    last_render_key = None
    print("FLASH START id={}".format(flash.event["id"]))


def _service_reminder_clock(now):
    if not flash.enabled or flash.pending is None:
        return False
    if flash.tick(now, _reminder_epoch(now)):
        _flash_started(now)
        return True
    return False


if settings.MQTT_ENABLED and settings.MQTT_ENABLE_EXPERIMENTAL:
    from mqtt_client import FlashMqttClient

    def receive_mqtt(topic, payload):
        global mqtt_screens_changed
        now = time.monotonic()
        if topic == settings.MQTT_TOPIC:
            epoch_now = _reminder_epoch(now)
            if epoch_now is None:
                print("FLASH ignored: clock not synchronized")
                return
            if flash.accept(payload, now, epoch_now=epoch_now):
                _flash_started(now)
            return
        epoch_now = _reminder_epoch(now)
        if epoch_now is None:
            print("MQTT screen ignored: clock not synchronized")
            return
        if mqtt_screens.accept(topic, payload, epoch_now):
            rotation.update_sources(
                rotation.http_screens, mqtt_screens.screens(epoch_now), now
            )
            mqtt_screens_changed = True

    mqtt = FlashMqttClient(
        settings,
        receive_mqtt,
        startup_delay_seconds=settings.MQTT_STARTUP_DELAY_SECONDS,
    )
rendered_diagnostic_index = None
last_render_key = None

# Todoist frame-pacing diagnostics are reset whenever the board enters the
# Todoist screen, so each serial summary represents one comparable run.
pace_active = False
pace_started = 0.0
pace_last_report = 0.0
pace_ticks = 0
pace_late_frames = 0
pace_late_streak = 0
pace_max_late_streak = 0
pace_last_tick_started = None
pace_interval_total = 0.0
pace_interval_count = 0
pace_interval_max = 0.0
pace_worst_gap_show = 0.0
pace_worst_gap_sleep = 0.0
pace_worst_gap_other = 0.0
pace_worst_gap_preframe = 0.0
pace_interval_over_200ms = 0
pace_interval_over_500ms = 0
pace_other_total = 0.0
pace_other_count = 0
pace_other_max = 0.0
pace_other_over_200ms = 0
pace_preframe_total = 0.0
pace_preframe_count = 0
pace_preframe_max = 0.0
pace_preframe_stage_max = {
    "reminder": 0.0, "mqtt": 0.0, "buttons": 0.0,
    "fetch_decision": 0.0, "fetch": 0.0, "screen_select": 0.0,
}
pace_last_show_seconds = 0.0
pace_last_sleep_seconds = 0.0
pace_sleep_requested_total = 0.0
pace_sleep_requested_count = 0
pace_sleep_requested_max = 0.0
pace_sleep_actual_total = 0.0
pace_sleep_actual_count = 0
pace_sleep_actual_max = 0.0
pace_sleep_overshoots = 0
pace_show_total = 0.0
pace_show_count = 0
pace_show_max = 0.0
next_animation_deadline = None

# Low-volume work-attribution telemetry for soak runs. These counters are
# reported with FRAME PACE and deliberately avoid per-frame serial output.
telemetry_started = time.monotonic()
telemetry_fetches = 0
telemetry_fetch_failures = 0
telemetry_fetch_total = 0.0
telemetry_fetch_max = 0.0
telemetry_scene_renders = 0
telemetry_scene_render_total = 0.0
telemetry_scene_render_max = 0.0
telemetry_scene_render_over_budget = 0
animation_cadence = None


def _matrix_root_token():
    """Return the current root-group identity when running on MatrixPortal."""
    base = getattr(display, "base", display)
    hardware_display = getattr(base, "display", None)
    root_group = getattr(hardware_display, "root_group", None)
    return id(root_group) if root_group is not None else None


def _memory_free():
    if gc is None or not hasattr(gc, "mem_free"):
        return None
    return gc.mem_free()


def _display_phase(screen, phase):
    if screen.get("kind") == "flash":
        return phase
    if settings.ANIMATE:
        return phase
    if _smooth_departures(screen):
        return phase
    if _smooth_steam_train(screen):
        return phase
    if screen.get("kind") == "calendar_agenda" and screen.get("source") == "todoist":
        return phase
    if _smooth_queue(screen):
        return phase
    if _smooth_sun_weather(screen):
        return phase
    if _smooth_bin_collection(screen):
        return phase
    return 2


def _smooth_todoist(screen):
    return (
        settings.DISPLAY_BACKEND == "matrix"
        and screen.get("kind") == "calendar_agenda"
        and screen.get("source") == "todoist"
    )


def _smooth_departures(screen):
    return (
        settings.DISPLAY_BACKEND == "matrix"
        and screen.get("kind") == "rail_combined"
    )


def _smooth_queue(screen):
    return (
        settings.DISPLAY_BACKEND == "matrix"
        and screen.get("kind") == "theme_park_queues"
    )


def _smooth_sun_weather(screen):
    return (
        settings.DISPLAY_BACKEND == "matrix"
        and screen.get("kind") == "weather_sun"
    )


def _smooth_steam_train(screen):
    return (
        settings.DISPLAY_BACKEND == "matrix"
        and screen.get("kind") == "steam_train_intro"
    )


def _smooth_bin_collection(screen):
    return (
        settings.DISPLAY_BACKEND == "matrix"
        and screen.get("kind") == "bin_collection"
    )


def _report_pace(now):
    if not pace_active or now - pace_last_report < MATRIX_STATS_INTERVAL_SECONDS:
        return False
    elapsed = max(0.001, now - pace_started)
    telemetry_elapsed = max(0.001, now - telemetry_started)
    fetch_average = telemetry_fetch_total / telemetry_fetches if telemetry_fetches else 0.0
    render_average = (
        telemetry_scene_render_total / telemetry_scene_renders
        if telemetry_scene_renders else 0.0
    )
    interval_average = (
        pace_interval_total / pace_interval_count if pace_interval_count else 0.0
    )
    other_average = pace_other_total / pace_other_count if pace_other_count else 0.0
    sleep_requested_average = (
        pace_sleep_requested_total / pace_sleep_requested_count
        if pace_sleep_requested_count else 0.0
    )
    sleep_actual_average = (
        pace_sleep_actual_total / pace_sleep_actual_count
        if pace_sleep_actual_count else 0.0
    )
    show_average = pace_show_total / pace_show_count if pace_show_count else 0.0
    print(
        "FRAME PACE mode={} target_fps={} elapsed={:.1f} animation_ticks={} "
        "tick_fps={:.2f} late_frames={} max_late_streak={} "
        "tick_gap_avg={:.3f} tick_gap_max={:.3f} gap_over_200ms={} "
        "gap_over_500ms={} other_avg={:.4f} other_max={:.4f} "
        "worst_gap_parts_show={:.3f} sleep={:.3f} other={:.3f} "
        "preframe_avg={:.4f} preframe_max={:.4f} worst_preframe={:.3f} "
        "stage_maxes={} "
        "other_over_200ms={} show_avg={:.4f} show_max={:.4f} "
        "sleep_req_avg={:.4f} sleep_req_max={:.4f} "
        "sleep_avg={:.4f} sleep_max={:.4f} sleep_overshoots={} "
        "fetches={} fetch_failures={} fetch_avg={:.3f} fetch_max={:.3f} "
        "scene_renders={} render_avg={:.3f} render_max={:.3f} "
        "render_over_budget={} telemetry_elapsed={:.1f}".format(
            MATRIX_PRESENTATION_MODE,
            MATRIX_REFRESH_FPS,
            elapsed,
            pace_ticks,
            pace_ticks / elapsed,
            pace_late_frames,
            pace_max_late_streak,
            interval_average,
            pace_interval_max,
            pace_interval_over_200ms,
            pace_interval_over_500ms,
            other_average,
            pace_other_max,
            pace_worst_gap_show,
            pace_worst_gap_sleep,
            pace_worst_gap_other,
            pace_preframe_total / pace_preframe_count if pace_preframe_count else 0.0,
            pace_preframe_max,
            pace_worst_gap_preframe,
            pace_preframe_stage_max,
            pace_other_over_200ms,
            show_average,
            pace_show_max,
            sleep_requested_average,
            pace_sleep_requested_max,
            sleep_actual_average,
            pace_sleep_actual_max,
            pace_sleep_overshoots,
            telemetry_fetches,
            telemetry_fetch_failures,
            fetch_average,
            telemetry_fetch_max,
            telemetry_scene_renders,
            render_average,
            telemetry_scene_render_max,
            telemetry_scene_render_over_budget,
            telemetry_elapsed,
        )
    )
    return True


def _apply_flash_config(payload):
    config = payload.get("flash") if isinstance(payload, dict) else None
    if not isinstance(config, dict):
        return
    # The public screen payload carries only non-secret operational settings.
    # Both board-local flags and this runtime setting gate reminders.
    runtime_enabled = (
        settings.MQTT_ENABLED
        and settings.MQTT_ENABLE_EXPERIMENTAL
        and config.get("enabled", False)
    )
    flash.configure(
        enabled=runtime_enabled,
        duration_seconds=config.get("screen_duration_seconds"),
    )


while True:
    now = time.monotonic()
    loop_started = now
    stage_started = time.monotonic()
    _service_reminder_clock(now)
    stage_durations = {"reminder": time.monotonic() - stage_started}
    stage_started = time.monotonic()
    if mqtt is not None:
        mqtt_allow_connect = True
        if rotation.screens and not flash.active(now):
            mqtt_screen, mqtt_phase = rotation.current(now)
            mqtt_allow_connect = not display.animation_active(mqtt_screen, mqtt_phase)
        mqtt.poll(now, allow_connect=mqtt_allow_connect)
    stage_durations["mqtt"] = time.monotonic() - stage_started
    stage_started = time.monotonic()
    button_events = list(_pending_button_events)
    _pending_button_events[:] = []
    if buttons is not None:
        button_events.extend(buttons.poll(now))
    stage_durations["buttons"] = time.monotonic() - stage_started
    for event in button_events:
        if runtime_mode.mode == "normal" and event in ("up", "down"):
            display.adjust_brightness(1 if event == "up" else -1)
            continue
        if runtime_mode.handle(event, rotation, now):
            rendered_diagnostic_index = None

    if runtime_mode.mode == "diagnostic":
        if rendered_diagnostic_index != runtime_mode.diagnostic_index:
            name, color = runtime_mode.diagnostic()
            print("DIAGNOSTIC", name)
            display.show_diagnostic(color)
            rendered_diagnostic_index = runtime_mode.diagnostic_index
        _sleep_interruptible(settings.FRAME_SECONDS)
        continue

    stage_started = time.monotonic()
    should_fetch = settings.SCREEN_SOURCE == "fixture"
    fetch_during_animation = False
    if settings.SCREEN_SOURCE != "fixture":
        candidate = None
        candidate_phase = 0
        if rotation.screens and not flash.active(now):
            candidate, candidate_phase = rotation.current(now)
            fetch_during_animation = (
                _smooth_todoist(candidate)
                or _smooth_departures(candidate)
                or _smooth_steam_train(candidate)
                or _smooth_sun_weather(candidate)
            )
        animation_active = bool(
            fetch_during_animation
            and display.animation_active(candidate, candidate_phase)
        )
        safe_window = None
        if fetch_during_animation and not animation_active:
            safe_window = display.animation_sleep_seconds(candidate, candidate_phase)
        should_fetch, next_fetch = screen_fetch_decision(
            now,
            next_fetch,
            animation_active,
            safe_window,
            _ANIMATION_FETCH_RETRY_SECONDS,
            _ANIMATION_FETCH_GUARD_SECONDS,
        )
    stage_durations["fetch_decision"] = time.monotonic() - stage_started
    stage_started = time.monotonic()
    if should_fetch:
        fetch_started = time.monotonic()
        # Screen API calls are synchronous and can take multiple animation
        # frames. Freeze the selected screen phase for that interval so the
        # first post-fetch frame resumes where the last one left off.
        fetch_resume = None
        if rotation.screens and not flash.active(fetch_started):
            fetch_resume = rotation.pause(fetch_started)
        try:
            print("FETCH START")
            payload = fixture_payload(now) if client is None else client.fetch()
            screens = payload.get("screens")
            display_config = payload.get("display")
            if (
                isinstance(display_config, dict)
                and "brightness_percent" in display_config
                and hasattr(display, "set_brightness_percent")
            ):
                display.set_brightness_percent(display_config["brightness_percent"])
            fetch_completed = time.monotonic()
            fetch_duration = fetch_completed - fetch_started
            telemetry_fetches += 1
            telemetry_fetch_total += fetch_duration
            telemetry_fetch_max = max(telemetry_fetch_max, fetch_duration)
            print("FETCH OK screens={} duration={:.3f}".format(len(screens or []), fetch_duration))
            epoch_now = _reminder_epoch(fetch_completed)
            rotation.update_sources(
                screens,
                mqtt_screens.screens(epoch_now) if epoch_now is not None else [],
                fetch_completed,
            )
            if fetch_resume is not None:
                rotation.resume(fetch_completed, fetch_resume[0], fetch_resume[1])
            _apply_flash_config(payload)
            fetched_at = payload.get("clock_at") or payload.get("fetched_at")
            if fetched_at and (client is not None or not fixture_clock_synced):
                clock.sync(fetched_at, fetch_completed)
                fixture_clock_synced = True
            transport_stale = False
        except Exception as error:
            fetch_completed = time.monotonic()
            fetch_duration = fetch_completed - fetch_started
            telemetry_fetches += 1
            telemetry_fetch_failures += 1
            telemetry_fetch_total += fetch_duration
            telemetry_fetch_max = max(telemetry_fetch_max, fetch_duration)
            print("Screen fetch failed duration={:.3f}:".format(fetch_duration), error)
            transport_stale = bool(rotation.screens)
            if fetch_resume is not None:
                rotation.resume(fetch_completed, fetch_resume[0], fetch_resume[1])
        now = fetch_completed
        next_fetch = now + settings.POLL_SECONDS
        if fetch_during_animation and hasattr(display, "note_fetch_overlap"):
            display.note_fetch_overlap()
    stage_durations["fetch"] = time.monotonic() - stage_started

    epoch_now = _reminder_epoch(now)
    if epoch_now is not None and mqtt_screens.expire(epoch_now):
        rotation.update_sources(rotation.http_screens, mqtt_screens.screens(epoch_now), now)
        mqtt_screens_changed = True
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

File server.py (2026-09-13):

"""Local departures API and browser simulator server.

This is deliberately CPython-only. It keeps external feed integration on the
backend and exposes a small JSON contract that a browser or a future
CircuitPython client can consume.
"""

from __future__ import annotations

import argparse
import copy
from datetime import datetime, timezone
from functools import partial
from http.server import SimpleHTTPRequestHandler, ThreadingHTTPServer
import json
import os
from pathlib import Path
import re
import subprocess
import threading
import time
from urllib.parse import urlparse

from fixtures import CALENDAR_EVENTS, PAGES
from queue_times import QueueFeedUnavailable, QueueTimesProvider, ThorpeParkFeed
from weather import OpenMeteoProvider, WeatherFeed, WeatherFeedUnavailable


WSDL_URL = "https://lite.realtime.nationalrail.co.uk/OpenLDBWS/wsdl.aspx?ver=2021-11-01"
SECRET_ID_PATTERN = re.compile(r"^[0-9a-fA-F-]{36}$")
PROJECT_ROOT = Path(__file__).resolve().parent
SIMULATOR_ROOT = PROJECT_ROOT / "simulator"
DEFAULT_THORPE_PARK_RIDES = (
    "Hyperia",
    "Stealth",
    "The Swarm",
    "SAW - The Ride",
    "Nemesis Inferno",
    "Colossus",
    "Ghost Train",
    "Rush",
    "Detonator",
    "Tidal Wave",
)
DEFAULT_WEATHER_LATITUDE = 51.4039
DEFAULT_WEATHER_LONGITUDE = -0.256


class ConfigurationError(RuntimeError):
    """The server cannot start safely with its current configuration."""


class FeedUnavailable(RuntimeError):
    """No departure data is currently available."""


def load_dotenv(path=PROJECT_ROOT / ".env"):
    """Load simple KEY=VALUE settings without overwriting the environment."""
    try:
        lines = path.read_text(encoding="utf-8").splitlines()
    except FileNotFoundError:
        return
    for raw_line in lines:
        line = raw_line.strip()
        if not line or line.startswith("#") or "=" not in line:
            continue
        key, value = line.split("=", 1)
        key = key.strip()
        if key:
            os.environ.setdefault(key, value.strip())


def resolve_bitwarden_secret(secret_id, runner=None):
    """Resolve one Bitwarden secret without propagating sensitive output."""
    if not SECRET_ID_PATTERN.fullmatch(secret_id or ""):
        raise ConfigurationError("BWS_NATIONAL_RAIL_TOKEN_SECRET_ID must be a secret UUID")
    runner = runner or subprocess.run
    try:
        result = runner(
            ["bws", "secret", "get", secret_id, "--output", "json"],
            check=True,
            capture_output=True,
            text=True,
        )
        value = json.loads(result.stdout).get("value", "")
    except (FileNotFoundError, subprocess.SubprocessError, json.JSONDecodeError, AttributeError) as error:
        raise ConfigurationError("Unable to resolve the National Rail token from Bitwarden") from error
    if not isinstance(value, str) or not value.strip():
        raise ConfigurationError("The configured Bitwarden secret has no value")
    return value.strip()


def _first_location_name(value):
    if not isinstance(value, dict):
        return "Unknown"
    locations = value.get("location") or []
    if isinstance(locations, dict):
        locations = [locations]
    if locations and isinstance(locations[0], dict):
        return str(locations[0].get("locationName") or "Unknown")
    return "Unknown"


def _reason_text(value):
    if isinstance(value, str):
        return value
    if isinstance(value, dict):
        return str(value.get("reason") or value.get("value") or "")
    return ""


def _calling_points(value):
    """Flatten Darwin's destination-grouped calling-point structure."""
    groups = value or []
    if isinstance(groups, dict):
        groups = groups.get("callingPointList") or [groups]
    points = []
    for group in groups:
        if not isinstance(group, dict):
            continue
        raw_points = group.get("callingPoint") or group.get("callingPoints") or []
        if isinstance(raw_points, dict):
            raw_points = [raw_points]
        for point in raw_points:
            if not isinstance(point, dict):
                continue
            scheduled = str(point.get("st") or point.get("sta") or "--:--")
            expected = str(point.get("et") or point.get("at") or scheduled)
            cancelled = bool(point.get("isCancelled")) or expected.lower() == "cancelled"
            if cancelled:
                status = "Cancelled"
            elif expected.lower() == "on time" or expected == scheduled:
                status = "On time"
            else:
                status = expected
            points.append({
                "station": str(point.get("locationName") or "Unknown"),
                "crs": str(point.get("crs") or ""),
                "time": scheduled,
                "status": status,
                "cancelled": cancelled,
            })
    return points


def normalize_darwin_board(board, max_rows=10):
    """Convert a serialized Darwin departure board to the stable LED model."""
    container = (board or {}).get("trainServices") or {}
    raw_services = container.get("service") or [] if isinstance(container, dict) else []
    if isinstance(raw_services, dict):
        raw_services = [raw_services]

    services = []
    for item in raw_services[:max_rows]:
        scheduled = str(item.get("std") or item.get("sta") or "--:--")
        expected = str(item.get("etd") or item.get("eta") or scheduled)
        cancelled = bool(item.get("isCancelled")) or expected.lower() == "cancelled"
        if cancelled:
            status = "Cancelled"
        elif expected.lower() == "on time" or expected == scheduled:
            status = "On time"
        else:
            status = expected
        services.append(
            {
                "time": scheduled,
                "destination": _first_location_name(item.get("destination")),
                "platform": str(item.get("platform") or "-"),
                "status": status,
                "cancelled": cancelled,
                "delay_reason": _reason_text(item.get("delayReason") or item.get("cancelReason")),
                "stops": _calling_points(item.get("subsequentCallingPoints")),
            }
        )
    return services


class FixtureProvider:
    source = "fixture"

    def __init__(self, max_rows=10):
        self.max_rows = max_rows

    def fetch(self):
        return [copy.deepcopy(service) for page in PAGES for service in page][: self.max_rows]


class FixtureCalendarProvider:
    """Credential-free stand-in for a future calendar adapter."""

    source = "calendar_fixture"

    def fetch(self):
        return copy.deepcopy(CALENDAR_EVENTS)
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

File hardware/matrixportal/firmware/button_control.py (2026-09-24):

"""Non-blocking debounced button helpers for the MatrixPortal S3."""


class DebouncedButton:
    """Emit ``pressed`` once after a raw input stays changed long enough."""

    def __init__(self, read, debounce_seconds=0.05, active_low=True):
        self.read = read
        self.debounce_seconds = float(debounce_seconds)
        self.active_low = bool(active_low)
        raw = bool(read())
        self._raw_pressed = (not raw) if self.active_low else raw
        self._stable_pressed = self._raw_pressed
        self._changed_at = None

    @property
    def pressed(self):
        return self._stable_pressed

    def poll(self, now):
        raw = bool(self.read())
        pressed = (not raw) if self.active_low else raw
        if pressed != self._raw_pressed:
            self._raw_pressed = pressed
            self._changed_at = now
            return False
        if self._changed_at is None or pressed == self._stable_pressed:
            return False
        if now - self._changed_at < self.debounce_seconds:
            return False
        self._stable_pressed = pressed
        return pressed


class ButtonGesture:
    """Classify a debounced button as a short or long press."""

    def __init__(self, read, debounce_seconds=0.05, long_press_seconds=0.8):
        self.button = DebouncedButton(read, debounce_seconds=debounce_seconds)
        self.long_press_seconds = float(long_press_seconds)
        self._pressed_at = None
        self._long_emitted = False

    def poll(self, now):
        just_pressed = self.button.poll(now)
        if just_pressed:
            self._pressed_at = now
            self._long_emitted = False

        if self._pressed_at is not None and self.button.pressed:
            if not self._long_emitted and now - self._pressed_at >= self.long_press_seconds:
                self._long_emitted = True
                return "long"
            return None

        if self._pressed_at is not None and not self.button.pressed:
            event = None if self._long_emitted else "short"
            self._pressed_at = None
            self._long_emitted = False
            return event
        return None


class MatrixButtons:
    """Configure the MatrixPortal UP and DOWN buttons without host imports."""

    def __init__(self):
        import board
        import digitalio

        self._up_io = digitalio.DigitalInOut(board.BUTTON_UP)
        self._down_io = digitalio.DigitalInOut(board.BUTTON_DOWN)
        self._up_io.switch_to_input(pull=digitalio.Pull.UP)
        self._down_io.switch_to_input(pull=digitalio.Pull.UP)
        self._up = ButtonGesture(lambda: self._up_io.value)
        self._down = ButtonGesture(lambda: self._down_io.value)

    def poll(self, now):
        events = []
        up = self._up.poll(now)
        down = self._down.poll(now)
        if up:
            events.append("up_long" if up == "long" else "up")
        if down:
            events.append("down_long" if down == "long" else "down")
        return events

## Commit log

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2026-09-19 Issue #53: replace side-loading enclosure with direct-mount STL set
    Remove superseded side-loading CAD/STLs and add the complete direct-mount enclosure STL set, generation workflow, assembly documentation, and supporting hardware mounts.
    [01_backplane_module_PRINT_4.stl, 01_frame_module_256mm_PRINT_4.stl, 02_left_end_cap_PRINT_1.stl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]
2026-09-19 Issue #53: use reference-derived LED panel mount positions
    Adopt expected mount centres derived from the supplied 160x80 HUB75 reference STL, relocate reinforcement bars to clear those rows, and add a full-pattern verification template.
    [01_backplane_module_PRINT_4.stl, 02_module_joiner_PRINT_3.stl, 04_matrixportal_mount_PRINT_1.stl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]
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2026-09-21 Add mechanical validation and fix enclosure assembly clashes (#82)
    * Add mechanical assembly mesh validator
    * Define enclosure assembly validation intent
    * Run mechanical fit validation in enclosure CI
    * Document enclosure mechanical validation
    * Fix enclosure mechanical interfaces
    * Promote fixed enclosure interfaces to required checks
    * Regenerate enclosure STLs for mechanical fixes
    * Regenerate enclosure STLs after mechanical fixes
    * Document enclosure mechanical fixes
    * Regenerate enclosure STLs after mechanical fixes
    * Remove one-off STL regeneration hook
    * Update enclosure STL inventory
    * Record resolved mechanical validation findings
    ---------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
    [01_backplane_module_PRINT_3.stl, 01b_backplane_right_end_PRINT_1.stl, 02_module_joiner_PRINT_3.stl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]
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2026-09-23 Replace provisional P4 backplane mounting pattern with measured six-point layout (#96)
    * Replace provisional P4 mount pattern with six measured inserts
    * Document measured six-point P4 mount and locating-pin clearance
    * Record measured P4 mount geometry and locator-clearance gate
    * Regenerate measured P4 backplane artifacts on branch
    * Regenerate measured P4 backplane STLs
    * Restore read-only enclosure validation
    * Open locator clearances into frame opening
    * Document 10 mm moulded-locator clearances
    * Record manifold locator clearance geometry
    * Regenerate corrected P4 backplane artifacts
    * Regenerate P4 backplanes with locator clearances
    * Restore read-only validation after P4 r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
    [01_backplane_module_PRINT_3.stl, 01b_backplane_right_end_PRINT_1.stl, 08_mount_pattern_template_PRINT_1.stl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]
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2026-09-27 Restore rear hinge webs and clear floating-region warnings (#130)
    * Add bed-tied stationary hinge root support
    * Regenerate hinge v2 test STLs
    * Restore rear hinge webs and package supported Bambu slice
    * Expose hinge v2 models to Windsor Slicer
    * Make controller standoffs self-supporting
    * Temporarily regenerate PR130 controller STL
    * Regenerate controller hinge STL
    * Remove temporary STL regeneration workflow
    * Remove obsolete support-enabled slicer workaround
    * Remove obsolete support-enabled slicer workaround
    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
    [01_moving_panel_template_HINGE_TEST.stl, 02_middle_stationary_enclosure_HINGE_TEST.stl, 03_left_controller_end_enclosure_HINGE_TEST.stl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]
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2026-09-27 Restore proven 90 degree hinge clearance (#135)
    Restore the 7 mm panel-to-barrel hinge offset, keep 72 degrees as the normal service angle, and protect the full 90 degree mechanical sweep with CI validation.
    [direct_mount_enclosure.scad]
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2026-09-27 Move front-panel hinge to lower edge (#145)
    * Move panel hinge to lower edge
    * Align canonical meshes with CI renderer
    * Fix backplane side guides as U-channels
    * Move side junctions clear of backplane channel
    * Regenerate corrected enclosure STLs [skip ci]
    * Restore temporary STL workflow configuration
    * Reinforce hinge supports and side connectors
    * Regenerate corrected enclosure STLs [skip ci]
    * Restore temporary STL workflow configuration
    * Add upper backplane alignment connector
    * Make upper backplane connector support-free
    * Regenerate corrected enclosure STLs [skip ci]
    * Remove obsolete temporary STL sync workflow
    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
    [01_panel_hinge_template_PRINT_1.stl, 02_hinged_equipment_base_PRINT_1.stl, 03_universal_equipment_backplane_PRINT_1.stl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]
2026-09-27 Restore MatrixPortal Wi-Fi uploader for issue #113 (#146)
    * Restore MatrixPortal Wi-Fi uploader for issue #113
    * Add Wi-Fi uploader failure and retry tests
    * Add CircuitPython Web Workflow settings example
    * Ignore board-local Web Workflow settings
    * Read MatrixPortal Wi-Fi from CircuitPython settings
    * Document MatrixPortal Web Workflow upload procedure
    * Validate MatrixPortal Wi-Fi uploader in CI
    * Document manual MatrixPortal Wi-Fi update scope
    [settings.py]
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2026-09-28 Enclosure: reserve top-middle rotating clamp clearance (#148)
    * feat(enclosure): clear top-middle rotating clamp
    * test(enclosure): validate rotating clamp clearance profile
    * docs(enclosure): document top clamp clearance profile
    * docs(enclosure): update clamp profile validation
    * ci(enclosure): temporarily sync generated STL artifacts
    * chore(enclosure): regenerate canonical STLs
    * ci(enclosure): restore validation workflow
    * chore(enclosure): keep unchanged 01_panel_hinge_template_PRINT_1.stl canonical
    * chore(enclosure): keep unchanged 02_hinged_equipment_base_PRINT_1.stl canonical
    * fix(enclosure): extend upper connector release slot
    * test(enclosure): guard 15mm connector rel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
    [01_panel_hinge_template_PRINT_1.stl, 02_hinged_equipment_base_PRINT_1.stl, 03_universal_equipment_backplane_PRINT_1.stl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]
2026-09-28 Enclosure: full-height backplane with three aligned top closure screws (#149)
    * feat(enclosure): use full-height backplane with round clamp pocket
    * test(enclosure): validate full-height clamp pocket
    * docs(enclosure): describe full-height round clamp pocket
    * docs(enclosure): update clamp pocket validation
    * ci(enclosure): temporarily refresh full-height clamp-pocket STLs
    * chore(enclosure): refresh full-height clamp-pocket STLs
    * ci(enclosure): restore read-only validation after clamp-pocket STL refresh
    * feat(enclosure): replace rotating clamp with three aligned closure holes
    * test(enclosure): validate three aligned top closure holes
    * chore(enclosure): remove rotating clamp fro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
    [01_panel_hinge_template_PRINT_1.stl, 02_hinged_equipment_base_PRINT_1.stl, 03_universal_equipment_backplane_PRINT_1.stl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]
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2026-09-28 Enclosure: remove all rear ventilation (#152)
    * fix(enclosure): remove all rear ventilation slots
    * test(enclosure): require fully solid rear enclosure
    * docs(enclosure): specify completely solid rear enclosure
    * docs(enclosure): remove rear ventilation contract
    * ci(enclosure): temporarily refresh solid rear STL
    * chore(enclosure): refresh solid rear enclosure STLs
    * ci(enclosure): restore read-only validation after solid rear STL refresh
    * chore(enclosure): keep unrelated canonical STLs unchanged
    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
    [03_universal_equipment_backplane_PRINT_1.stl, direct_mount_enclosure.scad]
2026-09-28 Enclosure: remove rear cable slots and restore anti-tip print supports (#153)
    * fix(enclosure): remove remaining rear cable slots
    * docs(enclosure): route cabling through open module sides
    * docs(enclosure): forbid rear cable slots
    * test(enclosure): prevent rear cable slots returning
    * fix(enclosure): restore sacrificial anti-tip backplane supports
    * test(enclosure): require backplane anti-tip stabilisers
    * docs(enclosure): restore anti-tip backplane printing guidance
    * docs(enclosure): validate sacrificial print stabilisers
    * ci(enclosure): temporarily refresh stabilised backplane STL
    * chore(enclosure): refresh stabilised backplane STL
    * ci(enclosure): restore read-only validati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
    [03_universal_equipment_backplane_PRINT_1.stl, direct_mount_enclosure.scad]
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2026-09-29 Shorten and centre backplane print stabiliser feet (#155)
    * fix(enclosure): shorten and centre backplane stabiliser feet
    * test(enclosure): guard centred 26 mm stabiliser feet
    * docs(enclosure): document shorter centred print feet
    * docs(enclosure): update stabiliser validation contract
    * ci(enclosure): temporarily refresh shorter-foot canonical STL
    * ci(enclosure): restore read-only validation workflow
    * ci(enclosure): temporarily refresh shorter-foot canonical STL
    * chore(enclosure): refresh shorter-foot backplane STL [skip ci]
    * ci(enclosure): restore read-only validation after STL refresh
    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
    [03_universal_equipment_backplane_PRINT_1.stl, direct_mount_enclosure.scad]
2026-09-29 Fix/boss sockets edge inset (#156)
    * fix(enclosure): position boss sockets 10 mm from edges
    * chore(enclosure): refresh edge-positioned boss STL [skip ci]
    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
    [03_universal_equipment_backplane_PRINT_1.stl, direct_mount_enclosure.scad]
2026-09-29 Redesign enclosure ends to match full-depth profile (#157)
    * fix(enclosure): match end pieces to full-depth profile
    * docs(enclosure): document full-depth matching end pieces
    * docs(enclosure): update end-profile validation contract
    * docs(enclosure): clarify lower-only guide inset
    * test(enclosure): guard full-depth end profile
    * ci(enclosure): temporarily refresh redesigned end STLs
    * chore(enclosure): refresh full-depth end-profile STLs [skip ci]
    * fix(enclosure): clear guide shoulder before depth transition
    * test(enclosure): guard guide-to-depth-transition clearance
    * ci(enclosure): refresh corrected end-profile STLs
    * ch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
    [03_universal_equipment_backplane_PRINT_1.stl, 04_left_equipment_side_PRINT_1.stl, 05_right_equipment_side_PRINT_1.stl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]
2026-09-30 Support enclosure return ramp during upright print (#159)
    * fix(enclosure): support return ramp during upright print
    * test(enclosure): validate removable ramp print supports
    * docs(enclosure): document under-ramp print supports
    * docs(enclosure): update ramp-support validation gates
    * ci(enclosure): refresh under-ramp support STL
    * chore(enclosure): refresh under-ramp support STL [skip ci]
    * fix(enclosure): distribute supports across full ramp
    * test(enclosure): require early and late ramp support
    * docs(enclosure): document full ramp support coverage
    * docs(enclosure): update ramp support coverage
    * fix(enclosure): use break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
    [03_universal_equipment_backplane_PRINT_1.stl, direct_mount_enclosure.scad]
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2026-09-30 Refine enclosure for vertical printing and hinge rod sleeves (#160)
    * fix(enclosure): sleeve hinge rods into side pieces
    * test(enclosure): guard hollow rod side sleeves
    * docs(enclosure): document hinge rod support sleeves
    * docs(enclosure): update rod sleeve validation contract
    * ci(enclosure): temporarily refresh rod-sleeve STLs
    * chore(enclosure): refresh rod-sleeve side STLs [skip ci]
    * refactor(enclosure): define side-on vertical print profile
    * refactor(enclosure): make shell profile constant across length
    * feat(enclosure): print backplane side-on with breakaway tongue support
    * test(enclosure): validate side-on print p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
    [03_universal_equipment_backplane_PRINT_1.stl, 04_left_equipment_side_PRINT_1.stl, 05_right_equipment_side_PRINT_1.stl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]
2026-09-30 Simplify universal backplane upper seam reinforcement (#161)
    * refactor(enclosure): replace backplane arms with compact seam bosses
    * test(enclosure): enforce compact upper seam bosses
    * docs(enclosure): document compact seam reinforcement
    * ci(enclosure): temporarily refresh compact backplane STL
    * chore(enclosure): refresh compact-seam backplane STL
    * ci(enclosure): check out refresh branch directly
    * chore(enclosure): refresh compact-seam backplane STL
    * ci(enclosure): temporarily refresh connector-dependent STLs
    * chore(enclosure): refresh compact connector STLs
    * ci(enclosure): restore read-only validation after c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
    [03_universal_equipment_backplane_PRINT_1.stl, 04_left_equipment_side_PRINT_1.stl, 05_right_equipment_side_PRINT_1.stl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]
2026-10-01 Fix universal backplane physical fit and reinforcement (#164)
    * fix(enclosure): strengthen and loosen universal backplane fit
    * test(enclosure): guard issue 163 physical-fit geometry
    * docs(enclosure): document issue 163 backplane changes
    * docs(enclosure): align source comments with physical-fit geometry
    * docs(enclosure): refresh universal backplane dimensions
    * docs(enclosure): correct insertion support offset
    * docs(enclosure): correct shortened guide comments
    * docs(enclosure): finish issue 163 dimension refresh
    * docs(enclosure): align physical gates with issue 163
    * ci(enclosure): temporarily refresh issue 163 canonical STLs
    * chore(enclosure): refresh issue 163 canonical ST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
    [01_panel_hinge_template_PRINT_1.stl, 02_hinged_equipment_base_PRINT_1.stl, 03_universal_equipment_backplane_PRINT_1.stl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]
2026-10-02 Add PSU mounting SCAD prototypes for #166 (#167)
    * feat(enclosure): add PSU mounting prototypes for #166
    * fix(enclosure): repair corrupted PSU mount shared SCAD
    * chore(enclosure): keep PSU SCAD sources ASCII clean
    * chore(enclosure): keep PSU SCAD sources ASCII clean
    * chore(enclosure): keep PSU SCAD sources ASCII clean
    * chore(enclosure): keep PSU SCAD sources ASCII clean
    * test(enclosure): compile PSU SCAD prototypes in CI
    * fix(enclosure): align PSU mounts with current accessory boss grid
    * chore(enclosure): remove simulated PSU preview
    * chore(enclosure): remove simulated PSU preview
    * chore(enclosure): remove simulated PSU preview
    * chore(enclosure): remove simulated PSU pr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
    [01_service_tray_snap_latch.scad, 02_service_tray_snap_dock_PRINT_1.scad, 03_service_tray_snap_tray_PRINT_1.scad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]
2026-10-02 Add canonical PSU service-tray STL outputs (#169)
    * ci(enclosure): include PSU parts in canonical STL verification
    * build(enclosure): generate canonical PSU service-tray STLs
    * docs(enclosure): document canonical PSU STL outputs
    * ci(enclosure): publish canonical PSU STL filenames
    * ci(enclosure): bootstrap canonical PSU STL files
    * build(enclosure): add canonical PSU service-tray STLs
    * ci(enclosure): restore read-only canonical STL validation
    * ci(policy): prevent enclosure STL generation loops
    * docs(ci): document loop-safe STL validation
    * docs(enclosure): explain loop-safe STL workflow
    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
    [06_psu_service_tray_snap_dock_PRINT_1.stl, 07_psu_service_tray_snap_tray_PRINT_1.stl, 08_psu_service_tray_snap_latch_PRINT_1.stl]
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2026-10-02 Fix PSU dock fit for 80 mm enclosure opening (#173)
    * fix(enclosure): move accessory boss rows 5mm inward
    * fix(enclosure): align PSU dock interface to inset boss rows
    * test(enclosure): expect 5mm-inset accessory boss rows
    * fix(enclosure): keep PSU dock and tray inside 80mm envelope
    * docs(enclosure): record 80mm PSU dock fit correction
    * ci(enclosure): add one-time loop-safe STL refresh
    * build(enclosure): refresh 80mm PSU fit STLs [skip ci]
    * ci(enclosure): remove one-time STL refresh helper
    * fix(enclosure): mount PSU latch with heat-set inserts [skip ci]
    * ci(enclosure): validate heat-set latch geometry
    * ci(enclosure): temporarily refresh latch heat-set STLs
    * build(enclosu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
    [03_universal_equipment_backplane_PRINT_1.stl, 06_psu_service_tray_snap_dock_PRINT_1.stl, 07_psu_service_tray_snap_tray_PRINT_1.stl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]
2026-10-02 Strengthen universal backplane print footing (#168)
    * Resolve PR 168 after PSU fit update
    * ci: refresh PR 168 meshes after PSU fit update
    * Regenerate PR 168 meshes after PSU fit update [skip ci]
    * Restore read-only validation after PSU-fit conflict resolution
    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
    [02_hinged_equipment_base_PRINT_1.stl, 03_universal_equipment_backplane_PRINT_1.stl, direct_mount_enclosure.scad]
2026-10-02 Make rear reinforcement ribs continuous to enclosure floor (#174)
    * Use continuous floor-reaching ribs with guardrail slots
    * ci: refresh continuous-rib enclosure meshes
    * Regenerate continuous-rib enclosure meshes [skip ci]
    * Restore read-only validation after continuous-rib mesh refresh
    * Fix continuous-rib base clearance and guardrail slots
    * ci: refresh fixed continuous-rib meshes
    * Regenerate fixed continuous-rib meshes [skip ci]
    * experiment: preserve manifold guardrail roots through rib pockets
    * Regenerate fixed continuous-rib meshes [skip ci]
    * Extend continuous-rib sockets through base seat
    * Regenerate fixed continuous-rib meshes [skip ci]
    * Root centre guardrail tab ac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
    [02_hinged_equipment_base_PRINT_1.stl, 03_universal_equipment_backplane_PRINT_1.stl, direct_mount_enclosure.scad]
2026-10-02 issue 175 triangular slider supports (#176)
    * Add triangular base supports under backplane sliders
    * Ignore zero-volume shells in clearance validation
    * Use CI-rendered canonical base mesh
    * ci: refresh PR176 canonical base STL
    * Refresh canonical base STL [skip ci]
    * ci: remove temporary PR176 STL refresh workflow
    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
    [02_hinged_equipment_base_PRINT_1.stl, direct_mount_enclosure.scad]
2026-10-02 codex/issue 177 psu dock (#179)
    * Implement issue 177 enclosure-aligned PSU dock
    * Print PSU tray on edge for supported flexure
    * Fuse PSU support bars into tray plate
    * Add removable print tethers for PSU flexure
    * Record PSU tray slicer support limitation
    * Regenerate issue 177 enclosure and PSU meshes
    * Support PSU flexure through removable print tethers
    * Clarify unresolved PSU tray slicer warning
    * Regenerate tethered PSU tray mesh from SCAD
    * Add continuous print support for PSU flexure
    * Use slicer supports for PSU tray flexure
    * Regenerate clean supported PSU tray mesh
    * Add PSU detent test coupon
    * Document PSU dock bill of materials
    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
    [01_service_tray_snap_latch.scad, 02_service_tray_snap_dock_PRINT_1.scad, 03_service_tray_snap_tray_PRINT_1.scad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]
2026-10-03 Fix issue #177 PSU dock screw and pilot clearance (#181)
    * Fix PSU dock screw and pilot clearance
    * Assert recessed dock screw and corrected PSU pilots
    * Validate PSU dock screw slide clearance
    * Document PSU dock clearance correction
    * Align PSU validation with thicker dock geometry
    * Update PSU tray print dimensions
    * Correct PSU pilot measurement comment
    * ci: temporarily refresh issue 177 PSU canonical meshes
    * ci: refresh issue 177 meshes from PR head
    * Refresh issue 177 PSU canonical meshes [skip ci]
    * ci: restore read-only enclosure validation
    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
    [06_psu_service_tray_snap_dock_PRINT_1.stl, 07_psu_service_tray_snap_tray_PRINT_1.stl, psu_mount_common.scad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]
2026-10-03 Extend base side guides inward to first rib gaps (#183)
    * Extend side-guide capture lips to first rib gaps
    * Validate inward side-guide extensions
    * Document inward guide backup support
    * Document side-guide extension validation
    * ci: refresh PR183 canonical base STL
    * ci: remove temporary PR183 STL refresh workflow
    * Clean enclosure validator formatting
    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
    [02_hinged_equipment_base_PRINT_1.stl, direct_mount_enclosure.scad]
2026-10-03 Extend backplane ribs and use removable slicer support (#182) (#184)
    * Extend backplane ribs 1 mm and remove fused print support
    * Declare supported backplane print variant
    * Validate rib-only issue 182 geometry and slicer support
    * Document rib-only seating compensation
    * Update validation notes for rib-only issue 182 fix
    * Add one-shot issue 182 backplane STL refresh
    * Refresh issue 182 backplane STL [skip ci]
    * Trigger validation for rib-only issue 182 fix
    * Extend rib guardrail relief through issue 182 foot
    * Refresh issue 182 backplane STL after relief fix
    * Refresh issue 182 backplane STL [skip ci]
    * Trigger enclosure validation after rib relief fix
    Co-authored-b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
    [03_universal_equipment_backplane_PRINT_1.stl, direct_mount_enclosure.scad]
2026-10-03 Center PSU tray detent in dock pocket (#185)
    * Center PSU tray detent nose in dock pocket
    * Document centred PSU tray detent
    * Validate centred PSU detent geometry
    * ci: temporarily refresh centred-detent tray STL
    * Refresh centred-detent PSU tray STL [skip ci]
    * Center dock pocket on unchanged PSU tray detent
    * Document dock-pocket detent centring
    * Validate centred dock pocket without flexure drift
    * Restore unchanged PSU tray canonical STL
    * ci: temporarily refresh centred-detent dock STL
    * Refresh centred-detent PSU dock STL [skip ci]
    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
    [06_psu_service_tray_snap_dock_PRINT_1.stl, service_tray_snap_latch_common.scad]
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2026-10-04 Fix admin Flash toggle to stop MQTT polling (#190)
    * push
    * Clean PR 190 to MQTT runtime-toggle scope
    [code.py, flash_events.py, mqtt_client.py]
2026-10-04 Add 7-day weather forecast screen (#192)
    * Add seven-day Open-Meteo forecast
    * Emit weekly weather screen in local feed
    * Add configurable weather screen duration
    * Publish dedicated weekly weather screen
    * Render seven-day weather on MatrixPortal
    * Render weekly weather in browser simulator
    * Test weekly weather provider and cache
    * Test local weekly weather screen
    * Test weather runtime duration migration
    * Test weekly weather publishing
    * Test weekly weather display layout
    * Document weekly weather screen
    * Document weather screen runtime duration
    * Clarify atomic weather cache behaviour
    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
    [display.py, server.py]
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2026-10-05 Fix bilateral base slots on universal backplane ribs (#198)
    * Fix symmetric base slots on backplane ribs
    * Validate bilateral rib base entry slots
    * Document bilateral rib entry relief
    * Document symmetric rib-slot validation
    * Add one-off STL regeneration helper
    * Regenerate universal equipment backplane STL
    * Document bilateral rib slot inspection
    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
    [03_universal_equipment_backplane_PRINT_1.stl, direct_mount_enclosure.scad]
2026-10-05 Add snap-in C14 inlet to left enclosure side (#165)
    * Rebase C14 inlet onto current side geometry
    * Validate C14 inlet against current enclosure envelope
    * Document rebased C14 side inlet
    * ci: temporarily regenerate PR 165 left-side STL
    * Regenerate C14 left-side canonical STL
    * ci: remove temporary PR 165 STL refresh helper
    * Document canonical C14 side regeneration
    * Use measured portrait C14 connector envelope
    * Validate measured C14 body against rod sleeve
    * Document measured portrait C14 placement
    * ci: temporarily refresh measured C14 left STL
    * Regenerate measured C14 left-side STL
    * ci: remove temporary measured C14 STL helper
    * Document C14 rod and connector clearances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
    [04_left_equipment_side_PRINT_1.stl, 05_right_equipment_side_PRINT_1.stl, direct_mount_enclosure.scad]
2026-10-05 Fix PR165 post-merge enclosure validation (#199)
    * Remove temporary PR165 STL refresh helper
    * Add side-return hinge rod regression checks
    * Document PR165 hinge rod regression
    * Align bottom-extension check with production triangle
    [direct_mount_enclosure.scad]
2026-10-05 Fix weekly weather temperature glyphs (#195)
    * Fix weekly weather temperature glyphs
    * Keep weekly weather labels clear of icons
    [display.py]
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
